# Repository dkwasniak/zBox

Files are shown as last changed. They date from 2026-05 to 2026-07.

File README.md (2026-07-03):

# zBox

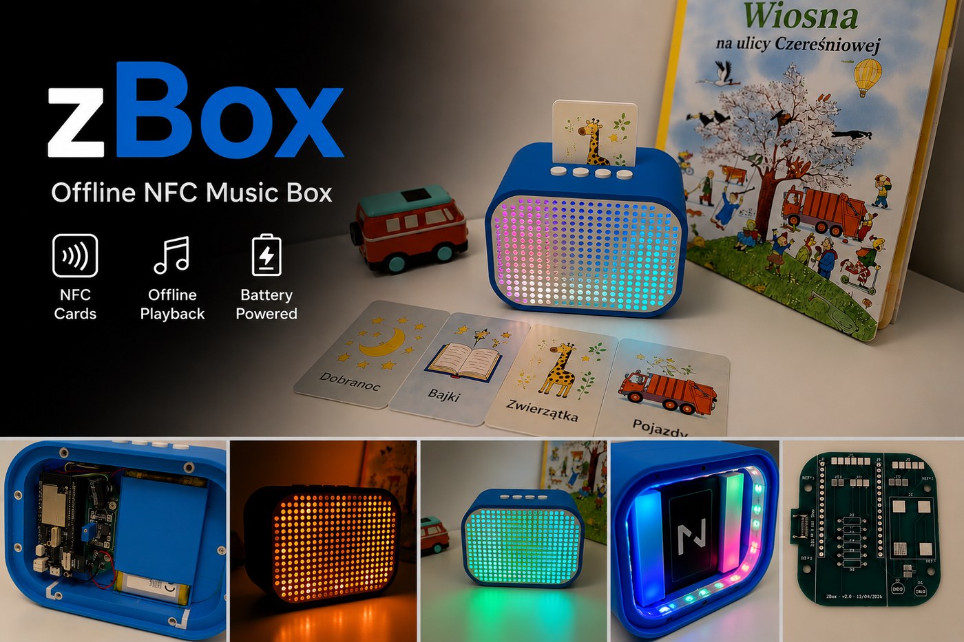
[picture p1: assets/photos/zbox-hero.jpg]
zBox hero


zBox is a custom offline NFC audio box I built for my daughter. It combines an ESP32, local SD card playback, a Raspberry Pi-hosted admin portal, LED effects, and a 3D-printed enclosure into a durable player that works with NFC cards.

This repository is the full build source for the project: firmware, backend, web admin, PCB design files, and the project documentation needed to rebuild it or adapt it for a similar box. The device plays audio stored on its SD card after an NFC tag is presented, and Wi-Fi is only used for sync and maintenance.

The box itself is built around a 3D-printed shell and custom electronics. This repository focuses on the complete hardware and software stack used in the build, from the ESP32 firmware and server to the PCB sources and operating notes. Mechanical exports such as the Fusion 360 STEP model live in `hardware/cad/fusion360/step/`.

## Project gallery

<p>
  zBox front view
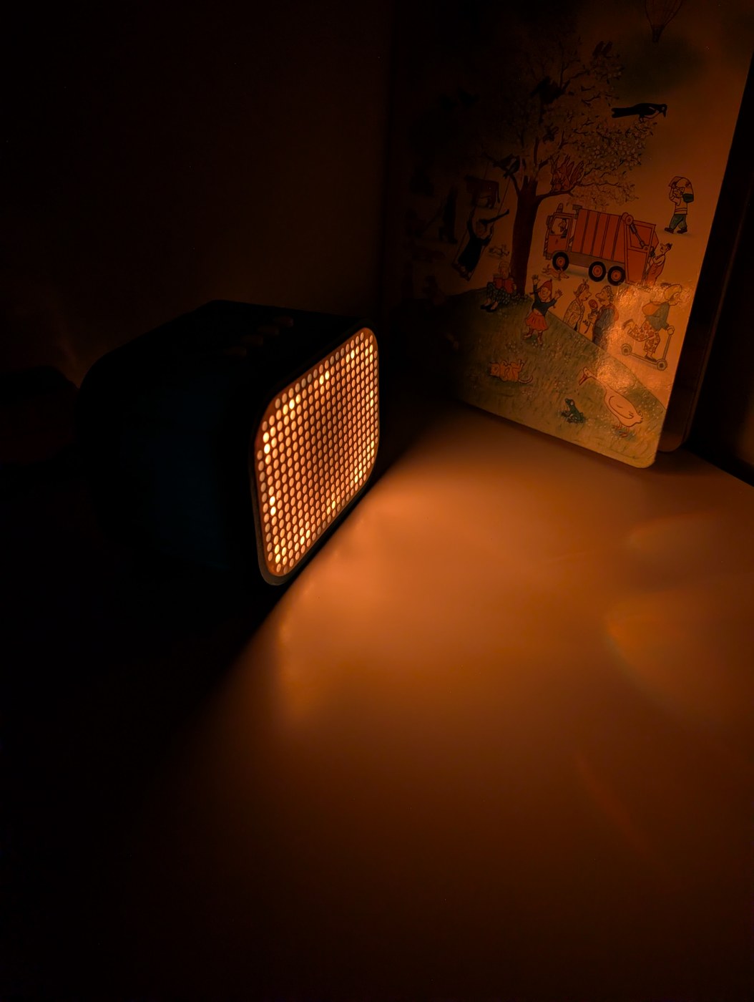
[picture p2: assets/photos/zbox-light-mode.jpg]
zBox in Light Mode
  
</p>
<p>
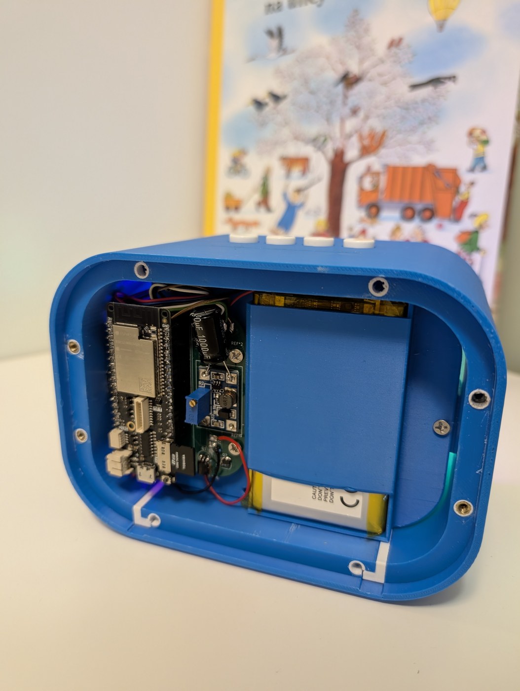
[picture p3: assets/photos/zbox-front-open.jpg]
zBox front opened
  
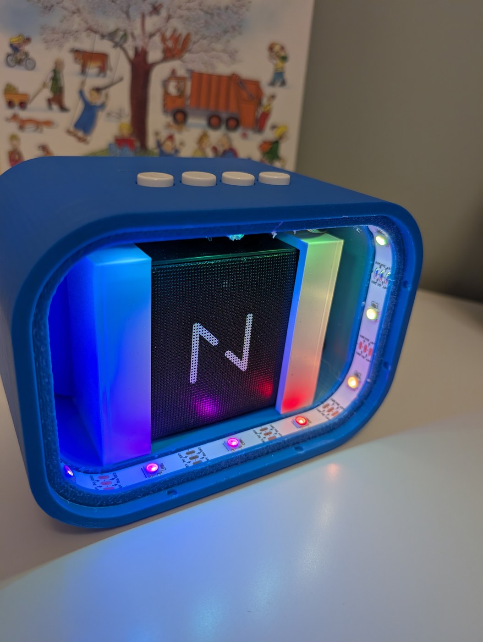
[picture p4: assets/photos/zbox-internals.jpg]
zBox internal layout
  
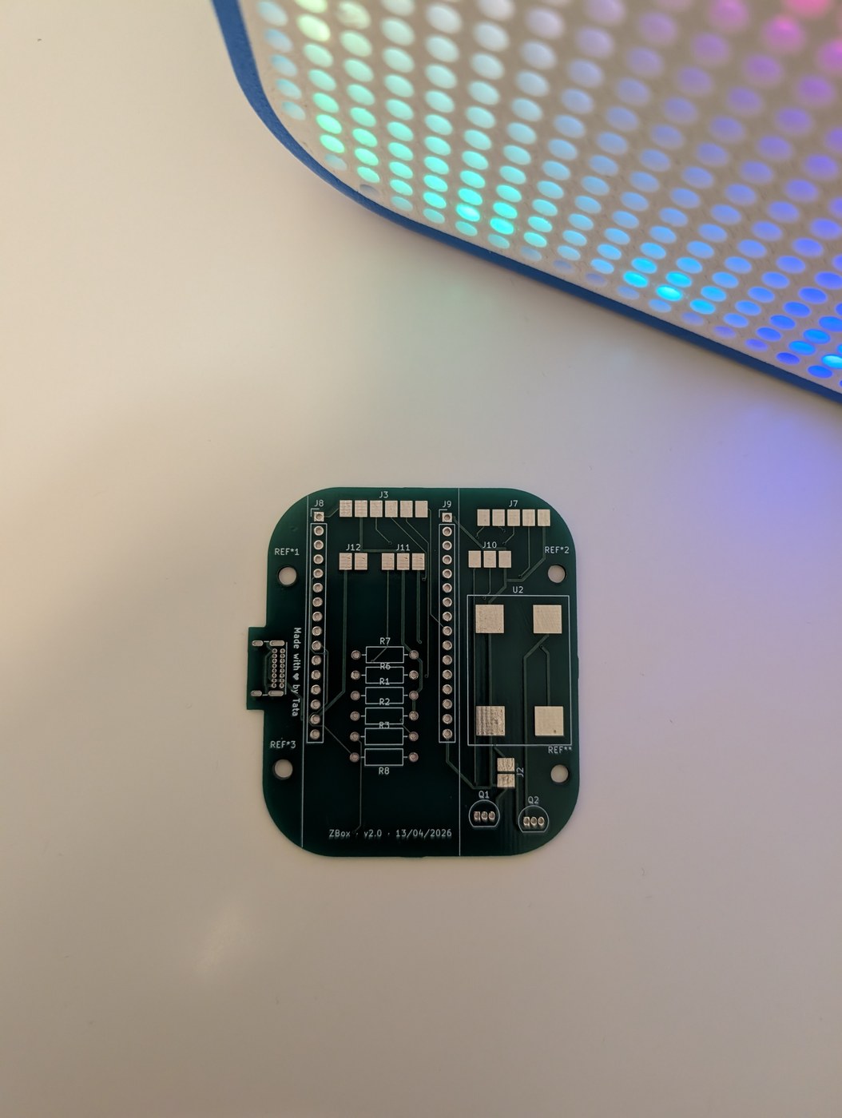
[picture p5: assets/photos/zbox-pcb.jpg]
zBox PCB
  
</p>

## Repository layout

```text
.
├── docs/                   Project documentation
├── esp32/                  ESP32 firmware (PlatformIO)
├── server/                 FastAPI backend and web admin UI
├── web/                    Static admin portal
├── hardware/               PCB, KiCad, Gerbers, and CAD exports
├── assets/                 Project photos and media used in docs
├── scripts/                Utility scripts
├── Dockerfile
└── docker-compose.yml
```

## Project split

- `esp32/` contains the offline playback firmware, Bluetooth audio pipeline, NFC handling, LED logic, and Sync Mode service flow.
- `server/` contains the FastAPI backend, SQLite integration, sync logic, and admin API.
- `web/` contains the static admin portal served by the backend.
- `hardware/pcb/kicad/` contains the PCB and schematic sources for the hardware build.
- `hardware/pcb/gerbers/` contains manufacturing outputs.
- `hardware/cad/fusion360/step/` contains exported mechanical CAD files such as STEP models.
- `assets/photos/` contains the product images used in this README.

## What to buy

If you want to build the current hardware revision, this is the practical shopping list. The various `PAD_*` items in KiCad are just solder pads for wires, not parts you need to buy.

- `1x` ESP32 Lolin D32 Pro
- `1x` PN532 NFC module that supports SPI mode
- `1x` MT3608 step-up module
- `1x` USB-C receptacle `GCT USB4085` or a compatible `USB 2.0 14-pin` footprint match
- `1x` P-channel MOSFET `AO3415A` in `SOT-23`
- `1x` NPN transistor `BC547` in `TO-92`
- `1x` electrolytic capacitor `470uF`
- `2x` resistors `5.1k`
- `1x` resistor `2.2k`
- `1x` resistor `10k`
- `1x` resistor `22k`
- `1x` resistor `100k`
- `1x` WS2812B LED strip or panel for the front light matrix
- `4x` momentary tactile buttons for `A`, `B`, `C`, and `D` — `12 × 12 × 7.3 mm`, 4-pin TACT switches with colored caps (e.g. MSALAMON kit or any equivalent 12 × 12 × 7.3 mm TACT switch)
- `1x` LiPo battery, currently `Akyga LP805080 3.7V / 4000mAh` with `JST 2-pin` connector
  This is the battery used in my build. Pack size: `8 mm` thick, `50 mm` wide, `80 mm` high. If you swap it for another pack, check the physical dimensions against the enclosure first.
- `1x` Bluetooth speaker, currently `JBL Go 2`
- hookup wire for all off-board connections

You will also need the non-electronic build parts:

- 3D-printed enclosure parts from the project CAD
- speaker holder inserts matching the audio setup you choose
- screws or other mounting hardware that fit your chosen assembly method

## Build cost

This is what I spent building one unit. Prices reflect individual-quantity purchases — buying components in bulk would bring the per-unit cost down.

| Part | Cost |
|---|---|
| PCB manufacturing | $5 |
| ESP32 Lolin D32 Pro | $15 |
| LiPo battery | $10 |
| Tactile buttons | $1 |
| Electronic components (resistors, caps, MOSFET, etc.) | ~$5–10 |
| 3D-printed enclosure filament | — |
| Bluetooth speaker (JBL Go 2) | had it at home |
| **Total (without speaker and filament)** | **~$36–41** |
| Enclosure design, prototype prints, and iteration | countless hours |
| Electrical prototyping and circuit debugging | countless hours |
| Fixing the low-quality software Claude Code produced | countless hours |

## Hardware overview

```text
NFC card
        │
        ▼
   PN532 reader
        │
        ▼
 ESP32 Lolin D32 Pro
   ├── SD card with local audio
   ├── WS2812B LED panel
   ├── buttons A / B / C / D
   ├── speaker power control
   └── Wi-Fi for sync and maintenance
        │
        ▼
 Bluetooth speaker
```

The device is offline-first during normal use. Audio and mappings live on the SD card, while Wi-Fi is only used for sync and maintenance.

## Audio design notes

For the current build I used a `JBL Go 2` connected over Bluetooth. It was a pragmatic choice: I already had that speaker at home, it was collecting dust, and I wanted the sound quality to stay reasonably good instead of dropping in a very cheap `2 USD` speaker.

I originally tried a direct wired path using a `PCM5102A` audio module and a jack connection into that speaker, but I could not get rid of the noise and crackling well enough to be happy with the result. Bluetooth ended up being the cleaner and more reliable solution for this revision.

The long-term plan is to reuse the speaker drivers from the JBL and connect them directly to the ESP32 through an `I2S Audio Amplifier Module NS4168`. The reason for that direction is simple: it should remove the extra Bluetooth speaker from the mechanical stack, give tighter integration with the enclosure, and keep a proper digital audio path from the ESP32 to the amplifier.

The speaker sits in a dedicated holder that slides onto internal rails built into the enclosure shell. The holder locks into position on those rails, so swapping it out for a different design requires no changes to the shell itself — print a new holder and slide it in. This makes it straightforward to adapt the enclosure for a different speaker body or a directly-wired driver setup without redesigning the main enclosure.

## PCB and schematic

> [!CAUTION]
> The PCB photo in this repository shows an earlier revision. The current schematic already includes corrections that came up after assembling the enclosure. If you are manufacturing a board, use the schematic and Gerbers from this repository — not the photo.

If you want to inspect or modify the hardware design, start here:

- Schematic: [zbox.kicad_sch](hardware/pcb/kicad/zbox.kicad_sch)
- PCB layout: [zbox.kicad_pcb](hardware/pcb/kicad/zbox.kicad_pcb)
- KiCad project: [zbox.kicad_pro](hardware/pcb/kicad/zbox.kicad_pro)
- Manufacturing outputs: [hardware/pcb/gerbers](hardware/pcb/gerbers)
- 3D enclosure export: [zbox_clear.step](hardware/cad/fusion360/step/zbox_clear.step)

## Printing the enclosure

The STEP model is ready to print. Each part must be printed separately. Print orientation matters:

| Part | Orientation |
|---|---|
| Shell (main body) | Standing upright on the front face |
| Side wall | Vertical |
| Front cover | No strong preference |
| Rear cover | Lying flat on its inner surface |

### Screws and heat-set inserts

| Location | Insert | Screw |
|---|---|---|
| Rear cover | M3 heat-set inserts | M3 |
| Side wall mounting | — | M4 |
| ESP32 board mounting | — | M4 |

### Build notes

- The buttons are soldered onto a protoboard — there is no custom PCB for them. The build uses **12 × 12 × 7.3 mm momentary tactile switches (TACT, 4-pin)** with colored caps, from the MSALAMON kit. Any equivalent 12 × 12 × 7.3 mm TACT switch will fit.
- The cutout for the button board in the enclosure is not symmetric. This can be corrected in Fusion 360, or you can just account for it when positioning the buttons during soldering. It turned out that way, reason unknown.
- The button board is attached to the speaker enclosure with hot glue.

## Hardware disclaimer

I am self-taught when it comes to electronics, so the hardware part of this project may still contain mistakes, weak assumptions, or design issues that I am not aware of.

The current revision works for me in real use, but if you want to reuse, manufacture, or adapt it, treat the design as something to review carefully rather than as a guaranteed reference design. In classic programmer terms: it works on my desk.

## First build walkthrough

Complete flow from assembled hardware to first playback.

**1. Prepare the SD card**

Format the card as FAT32. A 4–16 GB card is sufficient for most use cases. Leave it empty — the sync operation creates the directory structure on the device automatically.

**2. Configure the firmware**

Open the server configuration and set `ZBOX_IP` in `.env` to the IP address or hostname of the ESP32. The admin portal uses this address to reach the device in Sync Mode.

**3. Flash the firmware**

```bash
cd esp32
pio run -t upload
```

**4. Start the server**

```bash
docker compose up -d --build
```

The admin portal is available at `http://<host>:8000`. Set `ZBOX_IP` in `.env` to the IP address or mDNS hostname of the ESP32 so the admin portal can reach the device for maintenance and sync.

**5. Pair the Bluetooth speaker**

See [Bluetooth pairing](#bluetooth-pairing) below.

**6. Add music and register NFC tags**

See [Adding music and NFC tags](#adding-music-and-nfc-tags) below.

**7. Sync**

Trigger a sync from the admin portal. The device must be on the same Wi-Fi network as the server. LEDs show yellow while Wi-Fi is active and a blue progress bar while files are transferring. After sync completes, presenting a registered NFC tag in Card Mode starts playback.

## Bluetooth pairing

The firmware connects to the Bluetooth speaker by name. The expected name is `JBL GO 2`, defined as `BT_SPEAKER_NAME` in `esp32/src/zbox_config.h`. If your speaker broadcasts a different name, update that constant before flashing.

To pair on first boot:

1. Power on the device (hold `D` for 0.8–2 sec from deep sleep).
2. Put the speaker into pairing mode.
3. The device scans for the speaker by name and connects automatically. LEDs show soft blue breathing while waiting.
4. Once connected, LEDs switch to green idle animation.

The connection is not persisted — the device reconnects by name on every boot.

## Adding music and NFC tags

The firmware plays **MP3 files only**. Other formats are not recognised.

**1. Upload a track**

Open the admin portal at `http://<host>:8000`, go to **Songs**, and upload an MP3 file.

**2. Register an NFC tag**

Go to **Tags**. Power on the ESP32 and hold an NFC tag over the PN532 reader — the portal shows the scanned UID once the device is connected. Assign a name to the tag and link it to a track.

**3. Sync**

After saving the mapping, trigger a sync from the portal. The server pushes the updated mappings and audio files to the device over Wi-Fi. Once sync finishes, presenting the tag in Card Mode starts the assigned track.

## Admin portal

The web admin portal runs at `http://<host>:8000` and covers everything needed to manage the device without touching the firmware.

### Dashboard

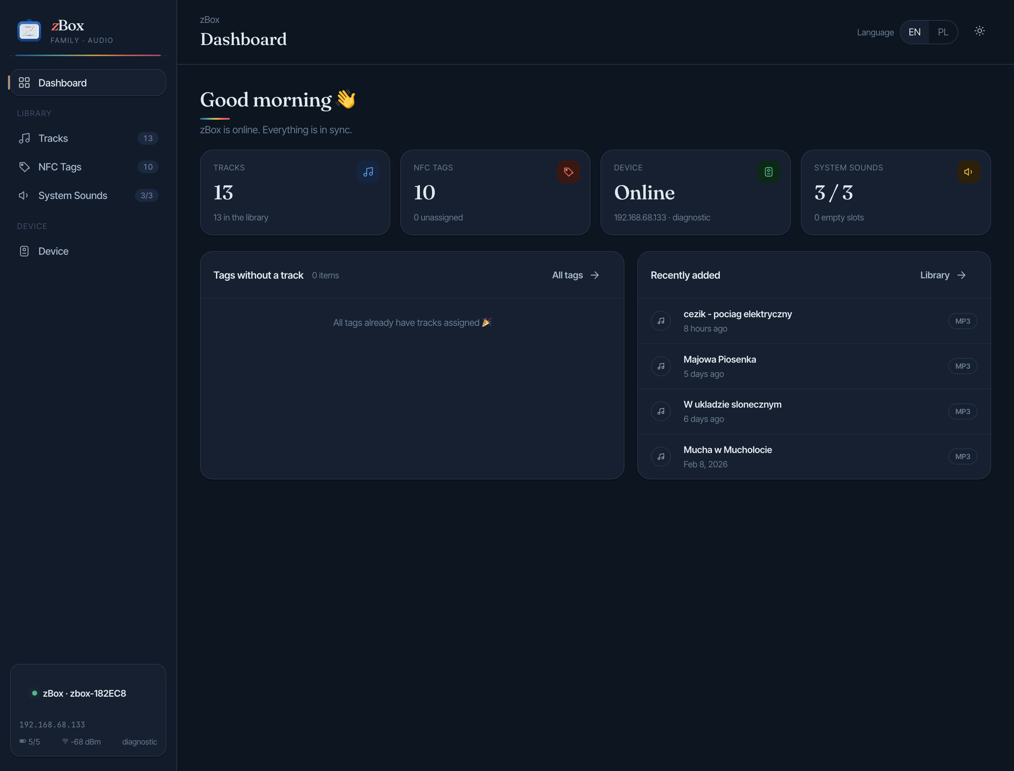
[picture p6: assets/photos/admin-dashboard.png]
Admin dashboard


The dashboard shows the live device status at a glance: connection state, number of tracks and NFC tags in the library, battery level, system sounds assignment, and recently added tracks. If any tags have no track assigned, they are flagged here.

### Tracks

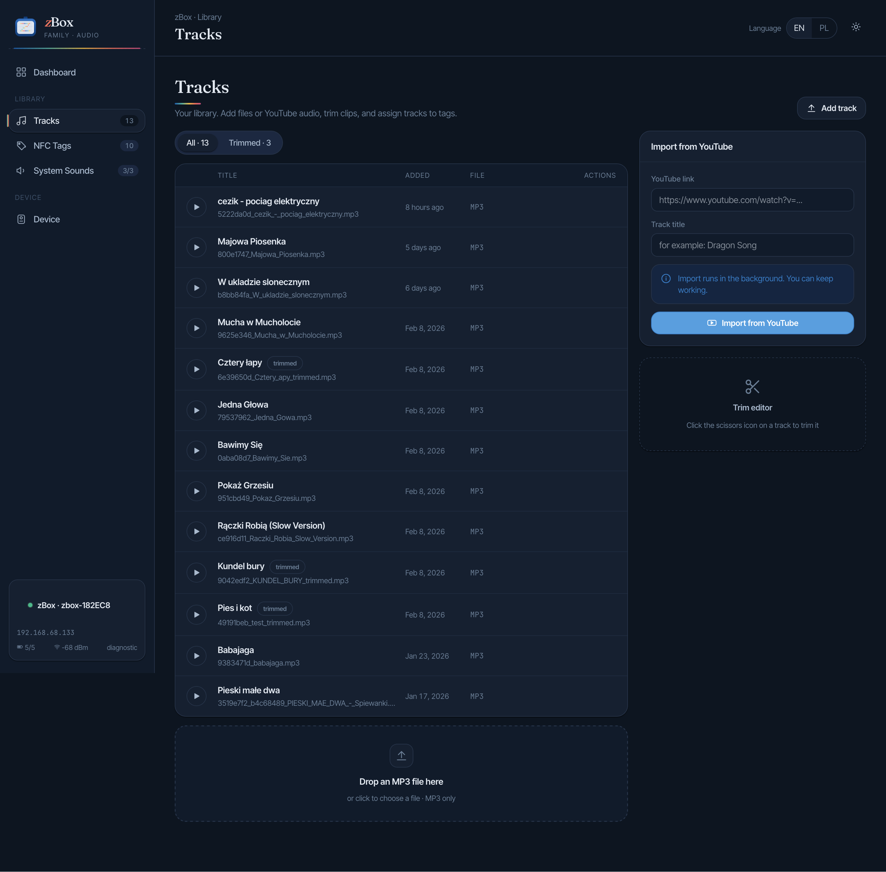
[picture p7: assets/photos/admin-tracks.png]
Tracks


The Tracks section is the music library. You can add tracks by dragging and dropping an MP3 file, or by pasting a YouTube URL to import audio directly in the background. Each track shows its filename, upload date, and size. A built-in trim editor lets you clip the start and end of a track without re-uploading the file.

**YouTube import.** Paste any YouTube URL into the import panel, give the track a title, and the server downloads and converts the audio in the background. You can keep using the portal while it runs — the track appears in the library once the download is complete.

**Trim editor.** Each track has an in-browser trim editor. Set the start and end points to cut intros, silence, or anything you do not want to play on the device. The trimmed version is what gets synced to the SD card. Tracks with an active trim are marked in the library so you can tell them apart from the originals.

### NFC Tags

The NFC Tags section lists every registered tag with its name, UID, and assigned track. The quick assign panel on the right lets you pick a tag and a track and save the mapping in one click. You can also add a tag manually by typing its name and UID hex string — useful when you want to register a tag without having the physical device connected.

**Reading a tag UID with an Android phone**

The admin portal has a built-in NFC scanner that uses the Web NFC API — no separate app needed. It works only in **Chrome on Android**; on iPhone you need to enter the UID manually.

To use it directly from the portal:

1. Open the admin portal in Chrome on Android and go to the **Tags** section.
2. The scan card appears automatically if your browser supports Web NFC.
3. Tap **Scan** and hold the tag against the back of the phone.
4. The UID is read and pre-filled into the tag form.

Web NFC requires a secure context (HTTPS or localhost). If the portal is served over plain HTTP on your local network, Chrome will block it. To work around this, enable the following Chrome flag and add your server address to the allowlist:

```
chrome://flags/#unsafely-treat-insecure-origin-as-secure
```

Alternatively, install a standalone NFC reader app (e.g. **NFC Tools** by wakdev), read the UID from there, and paste it into the manual entry field in the portal.

### System Sounds

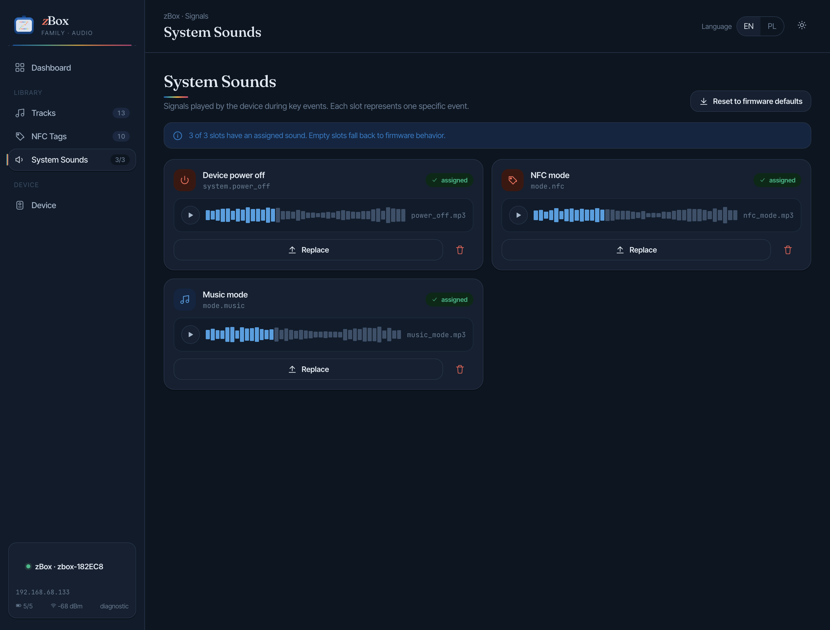
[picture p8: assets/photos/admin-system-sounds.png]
System Sounds


System Sounds are short audio clips the device plays for specific events: power off, switching to NFC mode, and switching to Music mode. Each slot shows a waveform preview and can be replaced with a custom MP3. The reset button restores the firmware defaults.

### Device and sync

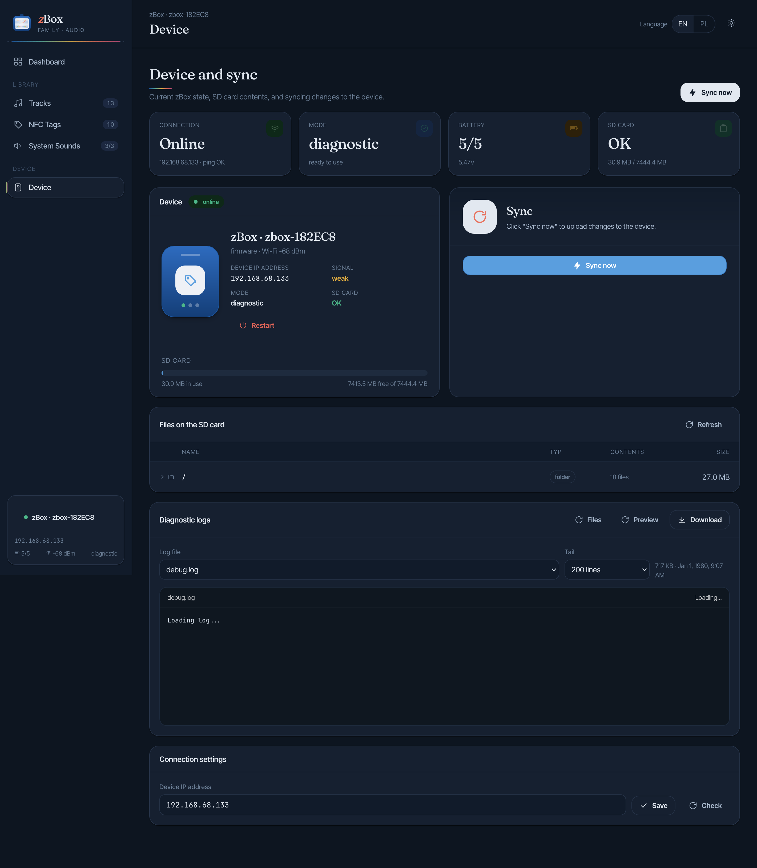
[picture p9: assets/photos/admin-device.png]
Device


The Device section is the maintenance hub. It shows live connection status, current mode, battery voltage, and SD card usage. The sync button pushes the current library and tag mappings to the device over Wi-Fi. Below that, a file browser shows everything on the SD card, and the diagnostic log viewer lets you stream or download device logs without a serial cable. The connection settings panel at the bottom is where you configure the device IP address for the portal.

## Getting started

### Server

```bash
docker compose up -d --build
```

The server runs in Docker. Runtime data is stored in `./data/`, audio assets in `./music/`, and the admin portal files in `./web/`, all mounted into the container by `docker-compose.yml`.

### ESP32 firmware

```bash
cd esp32
pio run
pio run -t upload
pio device monitor
```

The firmware depends on `esp32/lib/ESP32-A2DP`, which is kept as a Git submodule reference to the upstream project.

## Configuration model

- Server runtime configuration is local and installation-specific. The only required variable is `ZBOX_IP` — the IP address or mDNS hostname of the ESP32. Copy `.env.example` to `.env` and set it before starting the container.
- Wiring and GPIO pin assignments are documented in [`docs/hardware.md`](docs/hardware.md).

## Modes

- **Card Mode**. Default playback mode. The device reacts to NFC tags. Placing a known tag starts the assigned track from the SD card.
- **Music Mode**. Library playback mode. NFC is ignored and the buttons control pause, previous, and next track inside the local music library.
- **Light Mode**. Night light mode. Started from deep sleep by holding `D` longer during wake. In this mode `C` and `D` change brightness instead of volume.
- **Sync Mode**. Service mode used by the admin portal for maintenance, file transfer, log access, and configuration over Wi-Fi.

## Button shortcuts

| Button(s) | Action | Hold / Press | Context |
|---|---|---|---|
| `D` | **Power on** | hold `0.8–1.6 sec` while waking from deep sleep | from deep sleep |
| `D` | **Turn night light on** | hold `>= 1.6 sec` while waking from deep sleep | from deep sleep |
| `C` | **Power off** | hold `2 sec`, then release | Card Mode / Music Mode |
| `C` | **Emergency deep sleep** | hold `10 sec` | Card Mode / Music Mode |
| `C` | **Turn night light off** | hold `1 sec` | Light Mode |
| `B` | **Change mode: Music / Card** | hold `2 sec` | Card Mode / Music Mode |
| `A + B` | **Sync mode** | hold `2 sec` | Card Mode / Music Mode |
| `A` | **Battery level** | hold `2 sec` | Card Mode / Music Mode |
| `A` | **Pause / Resume** | short press | Music Mode |
| `A` | **Previous song** | double press | Music Mode |
| `B` | **Next song** | double press | Music Mode |
| `C` | **Vol −** | short press | Card Mode / Music Mode |
| `D` | **Vol +** | short press | Card Mode / Music Mode |
| `C` | **Light −** | short press | Light Mode |
| `D` | **Light +** | short press | Light Mode |

## LED animations

- **Boot progress**. Blue step-by-step progress. Each completed startup stage stays lit, and the current stage blinks three times.
- **Waiting for Bluetooth**. Soft blue breathing animation while the device is waiting for the speaker connection.
- **Idle**. Calm green breathing animation when the device is ready but not currently playing.
- **Playing**. Animated rainbow ring that reacts to audio energy and beats during playback.
- **Night Light**. Solid warm orange light. Brightness is controlled by `C` and `D`.
- **Volume**. Temporary white bar showing the current volume level for about one second after `Vol +` or `Vol -`.
- **Mode change**. Two short flashes. Music Mode uses the Music color, Card Mode uses the Card color.
- **Sleep ready**. Red blinking animation after holding `C` for two seconds. Releasing `C` at that point enters normal deep sleep.
- **Sync mode entry**. Purple animated dot pattern shown after `A+B` is held, while the device is preparing to reboot into Sync Mode.
- **Wi-Fi sync**. Blue blinking after the reboot, while the device is connecting to Wi-Fi and exposing the service endpoints used by the admin portal.
- **Sync progress**. Blue progress bar that fills while files are transferred to the SD card during sync.
- **Warning**. Slow amber breathing pulse when a mapping or file is missing.
- **Shutdown**. Purple sweep animation before the device powers down.
- **Battery check**. A color-coded bar on the LEDs: blue for high charge, then green, yellow, orange, and red for critical battery.

## Emergency deep sleep

**Emergency deep sleep** is a forced low-power shutdown triggered by holding `C` for `10 sec`.

- It is intended as a fallback if the normal shutdown path is not enough.
- It skips the regular graceful flow and shuts the device down as directly as possible.
- It still tries to turn the speaker off first if the hardware status line says the speaker is on.

## Deployment shape

The intended deployment is:

1. Build and run the FastAPI server in Docker on a small Linux host such as a Raspberry Pi.
2. Flash the ESP32 and configure the server to reach it via `ZBOX_IP`.
3. Use the web admin portal to manage tracks, NFC mappings, system sounds, and sync operations.

## Documentation

- [Server docs](docs/server.md)
- [Hardware docs](docs/hardware.md)
- [ESP32 quick start](esp32/README.md)

## Known constraints

- Playback is offline-first. The device syncs files and metadata to the SD card instead of streaming during normal use.
- Bluetooth and Wi-Fi are intentionally not used at the same time on the ESP32 due to memory and radio constraints.
- The current firmware configuration still requires a compile-time server host value.

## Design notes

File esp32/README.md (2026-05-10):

# zBox ESP32 Firmware

Firmware for the ESP32 Lolin D32 Pro using PlatformIO and the mixed `arduino, espidf` framework setup.

## Quick start

```bash
pio run
pio run -t upload
pio device monitor
```

## Before flashing

- review `ENABLE_LEDS`
- set `SERVER_HOST` for your own deployment
- verify the board and partition settings match your hardware

The main project constants live in [`src/zbox_config.h`](src/zbox_config.h).

## Documentation

- [Firmware architecture](../docs/esp32-firmware.md)
- [Hardware notes](../docs/hardware.md)
- [Server API and deployment](../docs/server.md)

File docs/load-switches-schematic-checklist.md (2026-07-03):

# Checklista do naniesienia w schemacie KiCad — load-switche NS + NFC

Mechaniczna lista do wklepania w `hardware/pcb/kicad/zbox.kicad_sch`. Bez step-upa.
Źródło prawdy: [`load-switches.md`](load-switches.md). Kolejność: nety → elementy → połączenia → zmiany na złączach.

## 0. Nowe nety do utworzenia

| Net | Rola |
|---|---|
| `+3V3_NS` | zasilanie modułu NS4168 za tranzystorem Q3 (przełączane) |
| `NS_EN_G` | bramka Q3 |
| `NFC_GND_SW` | masa modułu PN532 za tranzystorem Q4 (przełączana) |
| `NFC_EN_G` | bramka Q4 |

Istniejące, używane bez zmian: `+3V3`, `GND`, `GPIO15` (J9.15), `GPIO12` (J8.12).

## 1. Elementy do dodania

| Ref | Symbol / wartość | Footprint |
|---|---|---|
| Q3 | AO3401A (P-MOSFET) | `Package_TO_SOT_SMD:SOT-23` |
| Q4 | AO3400A (N-MOSFET) | `Package_TO_SOT_SMD:SOT-23` |
| R11 | 100k | `Resistor_THT:R_Axial_DIN0207_L6.3mm_D2.5mm_P10.16mm_Horizontal` |
| R12 | 10k | `Resistor_THT:R_Axial_DIN0207_L6.3mm_D2.5mm_P10.16mm_Horizontal` |
| R13 | 100k | `Resistor_THT:R_Axial_DIN0207_L6.3mm_D2.5mm_P10.16mm_Horizontal` |
| R14 | 100R | `Resistor_THT:R_Axial_DIN0207_L6.3mm_D2.5mm_P10.16mm_Horizontal` |
| C6 | 100nF | `Capacitor_THT:C_Disc_D5.0mm_W2.5mm_P5.00mm` |
| C2 | 10µF (elektrolit) | `Capacitor_THT:CP_Radial_D5.0mm_P2.50mm` |
| C3 | 100nF | `Capacitor_THT:C_Disc_D5.0mm_W2.5mm_P5.00mm` |
| C4 | 10µF (elektrolit) | `Capacitor_THT:CP_Radial_D5.0mm_P2.50mm` |
| C5 | 100nF | `Capacitor_THT:C_Disc_D5.0mm_W2.5mm_P5.00mm` |

BOM: 1× AO3401A · 1× AO3400A · 2× 100k · 1× 10k · 1× 100R · 3× 100nF · 2× 10µF.

## 2. Pinout FET-ów (SOT-23)

Oba: **pin1 = G, pin2 = S, pin3 = D.**

## 3. Połączenia pin-po-pinie

### NS — Q3 (high-side P-FET, aktywne LOW, soft-start)

| Od | Net |
|---|---|
| Q3 pin2 (S) | `+3V3` |
| Q3 pin3 (D) | `+3V3_NS` |
| Q3 pin1 (G) | `NS_EN_G` |
| R11 | `NS_EN_G` ↔ `+3V3` |
| R12 (10k) | `GPIO15` (J9.15) ↔ `NS_EN_G` |
| C6 (100nF) | `NS_EN_G` ↔ `+3V3` |
| C2 (10µF) | `+3V3_NS` (**+**) ↔ `GND` (**–**) |
| C3 (100nF) | `+3V3_NS` ↔ `GND` |

### NFC — Q4 (low-side N-FET, aktywne HIGH)

| Od | Net |
|---|---|
| Q4 pin3 (D) | `NFC_GND_SW` |
| Q4 pin2 (S) | `GND` |
| Q4 pin1 (G) | `NFC_EN_G` |
| R13 | `NFC_EN_G` ↔ `GND` |
| R14 (100R) | `GPIO12` (J8.12) ↔ `NFC_EN_G` |
| C4 (10µF) | `+3V3` (**+**) ↔ `NFC_GND_SW` (**–**) |
| C5 (100nF) | `+3V3` ↔ `NFC_GND_SW` |

## 4. Zmiany netów na istniejących połączeniach (KRYTYCZNE)

Nie zapomnij przepiąć zasilania modułów — inaczej switche nic nie robią:

- **NS4168 VDD:** `J13.p4` z `+3V3` → **`+3V3_NS`**.
- **PN532 GND:** `J3.p2` z `GND` → **`NFC_GND_SW`** (p1 zostaje `+3V3`).

## 5. Sanity-check po naniesieniu (ERC + logika)

- `+3V3_NS` łączy: Q3.D, C2+, C3, VDD NS4168 — i **nic** poza tym (żadnego `+3V3`).
- `NFC_GND_SW` łączy: Q4.D, C4–, C5, GND PN532 — i **nic** poza tym (żadnego `GND`).
- `NS_EN_G` łączy tylko: Q3.G, R11, R12, C6.
- `NFC_EN_G` łączy tylko: Q4.G, R13, R14.
- Bramki wyjściowe: `GPIO15`→R12, `GPIO12`→R14 (nie wprost do bramki).
- Elektrolity: C2 **+** na `+3V3_NS`, C4 **+** na `+3V3`.
- ERC bez „unconnected"/„conflict" na nowych netach.

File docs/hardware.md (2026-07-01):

# zBox Hardware

## Main components

- ESP32 Lolin D32 Pro
- PN532 NFC reader over software SPI
- NS4168 I2S amplifier as the default speaker output
- Optional Bluetooth headphones mode over A2DP
- WS2812B LED strip
- SD card for offline music and mappings
- Custom PCB for wiring and power distribution
- 3D-printed enclosure with exported CAD kept in `hardware/cad/fusion360/step/`
- Current exported model: `hardware/cad/fusion360/step/zbox_clear.step`

## High-level architecture

```text
ESP32 + SD + NFC + LEDs + buttons
        │
        ├── I2S audio ──> NS4168 amplifier ──> speaker
        ├── Optional Bluetooth A2DP audio ──> headphones
        └── Wi-Fi only during sync / diagnostics
```

## Important pin assignments

| GPIO | Function |
|---|---|
| `4` | SD card chip select |
| `5` | PN532 chip select |
| `0` | PN532 MOSI |
| `12` | PN532 power enable (NFC_EN, low-side, active HIGH) |
| `13` | NS4168 I2S data out |
| `14` | WS2812B data |
| `15` | NS4168 power enable (NS_EN, high-side, active LOW) |
| `21` | PN532 MISO |
| `22` | PN532 SCK |
| `25` | Button C |
| `26` | Button D |
| `27` | LED power enable |
| `32` | NS4168 I2S bit clock |
| `33` | NS4168 I2S word select |
| `36` | Button A |
| `39` | Button B |

## Lolin D32 Pro header numbering from the board photo

The board photo uses `L1..L16` on the left header and `R1..R16` on the right header, counted from top to bottom with the USB connector at the bottom.

### Header labels from the board photo

| Position | Board label | GPIO / signal |
|---|---|---|
| `L1` | `3V3` | `3V3` |
| `L2` | `RST` | `RST` |
| `L3` | `VP` | `GPIO36` |
| `L4` | `VN` | `GPIO39` |
| `L5` | `34` | `GPIO34` |
| `L6` | `32` | `GPIO32` |
| `L7` | `33` | `GPIO33` |
| `L8` | `25` | `GPIO25` |
| `L9` | `26` | `GPIO26` |
| `L10` | `27` | `GPIO27` |
| `L11` | `14` | `GPIO14` |
| `L12` | `12` | `GPIO12` |
| `L13` | `13` | `GPIO13` |
| `L14` | `EN` | `EN` |
| `L15` | `USB` | `5V / USB` |
| `L16` | `BAT` | `VBAT` |
| `R1` | `GND` | `GND` |
| `R2` | `23` | `GPIO23` |
| `R3` | `22` | `GPIO22` |
| `R4` | `TX` | `GPIO1` |
| `R5` | `RX` | `GPIO3` |
| `R6` | `21` | `GPIO21` |
| `R7` | `19` | `GPIO19` |
| `R8` | `18` | `GPIO18` |
| `R9` | `5` | `GPIO5` |
| `R10` | `NC` | `NC` |
| `R11` | `NC` | `NC` |
| `R12` | `4` | `GPIO4` |
| `R13` | `0` | `GPIO0` |
| `R14` | `2` | `GPIO2` |
| `R15` | `15` | `GPIO15` |
| `R16` | `GND` | `GND` |

### Project wiring in `Lx/Rx` format

| Position | Function |
|---|---|
| `L3` | `GPIO36 / BTN_A` |
| `L4` | `GPIO39 / BTN_B` |
| `L6` | `GPIO32 / AUDIO_I2S_BCLK` |
| `L7` | `GPIO33 / AUDIO_I2S_LRCK` |
| `L8` | `GPIO25 / BTN_C` |
| `L9` | `GPIO26 / BTN_D` |
| `L10` | `GPIO27 / LED_EN` |
| `L11` | `GPIO14 / LED_PIN` |
| `L13` | `GPIO13 / AUDIO_I2S_DOUT` |
| `R3` | `GPIO22 / PN532_SCK` |
| `R6` | `GPIO21 / PN532_MISO` |
| `R9` | `GPIO5 / PN532_SS` |
| `R12` | `GPIO4 / SD_CS` |
| `R13` | `GPIO0 / PN532_MOSI` |

## Audio wiring

The current board revision assumes a direct digital audio path:

- `GPIO32` -> `NS4168 BCLK`
- `GPIO33` -> `NS4168 LRCK / WS`
- `GPIO13` -> `NS4168 DIN`

The old JBL-specific control wiring is no longer part of the active firmware design:

- `GPIO13` is reused for I2S data.
- `GPIO34` is free from audio duties.
- There is no firmware dependency on a speaker power transistor or speaker status ADC.

## Power switching (load switches)

Goal: the NS4168 amplifier and the PN532 NFC reader are powered only while the ESP32 is
awake, each on its own transistor. They stay off in deep sleep and default off at
power-on/flash.

Pin choice is constrained by ESP32 strapping: the only free output-capable GPIOs are
`2`, `12`, `15` (`16/17` are PSRAM on the D32 Pro, `34` is input-only, the rest are used).
- `NS_EN = GPIO15` — high-side P-FET, gate pull-up to `+3V3` (default OFF); HIGH at boot is
  safe. **Active LOW** (LOW = on).
- `NFC_EN = GPIO12` — MTDI must be LOW at boot, so PN532 uses a **low-side N-FET** with a
  gate pull-down. **Active HIGH** (HIGH = on).
- `GPIO2` was rejected: a pull-up to `+3V3` (HIGH at boot) can block USB flashing.

### NS4168 amplifier — high-side P-FET (Q3), `GPIO15`

| Part | Value | Connection |
|---|---|---|
| Q3 | AO3401A (P-MOSFET, SOT-23) | S -> `+3V3`, D -> `+3V3_NS`, G -> `NS_EN_G` |
| R11 | 100k | `NS_EN_G` <-> `+3V3` (gate pull-up, default OFF) |
| R12 | 100R | `GPIO15` <-> `NS_EN_G` (series gate) |
| C2 | 220uF | `+3V3_NS` <-> `GND` (bulk near J13) |
| C3 | 100nF | `+3V3_NS` <-> `GND` (HF decoupling near J13) |

Net change: **J13 (NS4168) VDD pin `+3V3` -> `+3V3_NS`**.

### PN532 NFC reader — low-side N-FET (Q4), `GPIO12`

| Part | Value | Connection |
|---|---|---|
| Q4 | AO3400A (N-MOSFET, SOT-23) | D -> `NFC_GND_SW`, S -> `GND`, G -> `NFC_EN_G` |
| R13 | 100k | `NFC_EN_G` <-> `GND` (gate pull-down, default OFF + strap LOW) |
| R14 | 100R | `GPIO12` <-> `NFC_EN_G` (series gate) |
| C4 | 10uF | `+3V3` <-> `NFC_GND_SW` (bulk near J3) |
| C5 | 100nF | `+3V3` <-> `NFC_GND_SW` (HF decoupling near J3) |

Net change: **J3 (PN532) GND pin `GND` -> `NFC_GND_SW`** (VDD pin stays `+3V3`).

Firmware (`esp32/src/zbox_config.h`): add `NS_EN 15` (active LOW) and `NFC_EN 12`
(active HIGH). On wake: enable, wait ~20-50 ms, then init SPI/NFC and `i2s.begin()`. Before
sleep:
- NS (high-side): deinit I2S -> lines **LOW** -> `NS_EN = HIGH` (off). LOW is safe because
  the module VDD is 0.
- NFC (low-side): deinit SPI -> lines **hi-Z (INPUT)** -> `NFC_EN = LOW` (off). Not LOW! The
  module ground floats toward `+3V3`, so driving the lines LOW would forward-bias the module
  ESD diodes (GND->pin) and back-power the ESP. Hi-Z lets the lines float with the module.

Pull-up/pull-down hold both off in sleep and at cold boot.

### Status

- [x] Audio path I2S -> NS4168 (`GPIO32/33/13`), speaker via NS4168 module (J13)
- [x] Buttons A/B moved to L3/L4 (`GPIO36/39`) with 10k external pull-ups (R9/R10)
- [x] JBL circuit removed (Q1, R3/R6/R7, J10, J12, all `JBL_*` nets)
- [ ] NS4168 load switch: Q3, R11, R12, C2, C3; J13 VDD -> `+3V3_NS`
- [ ] PN532 load switch: Q4, R13, R14, C4, C5; J3 GND -> `NFC_GND_SW`
- [ ] Correct `C1` value in the schematic to the fitted `470uF`
- [ ] Firmware: add `NS_EN` / `NFC_EN` and the wake/sleep power sequencing

## Notes

- The PN532 is wired over software SPI: `SS=GPIO5`, `SCK=GPIO22`, `MISO=GPIO21`, `MOSI=GPIO0`.
- The SD card uses the board SPI wiring, so the related SPI pins should not be repurposed.
- The current firmware starts on local I2S audio immediately. Bluetooth is only an on-demand headphones mode triggered by a long hold on `BTN_A`.
- LED power is switched so the strip can be fully shut down during sleep.
- The PCB currently uses a `470uF` polarized capacitor (`C1`) in the power path near the step-up / LED supply section.

## Practical constraints

- Keep a shared ground between the ESP32, LED supply, and speaker control circuit.
- Treat wake, button routing, and diagnostic wiring as firmware-coupled decisions. Review [`esp32/src/zbox_config.h`](../esp32/src/zbox_config.h) before changing the PCB.
- If you revise the board, check whether the current button header and optional audio breakout still match the firmware goals.
- KiCad sources live in `hardware/pcb/kicad/`, and production Gerbers live in `hardware/pcb/gerbers/`.

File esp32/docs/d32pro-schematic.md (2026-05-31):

# LOLIN D32 Pro — Schematic Reference

**Board**: LOLIN D32 Pro, REV 2.0.0, Date: 2018-06-13
**MCU module**: ESP32-WROVER (ESP32 dual-core 240 MHz, 16 MB Flash @ 1.8 V, 8 MB PSRAM @ 1.8 V)
**Supply**: 3.3 V I/O, 5 V USB input, 3.7 V LiPo battery
**Dimensions**: 65 × 25.4 mm, Weight: 7.5 g

---

## Block 1: USB – UART

**Connector P2**: USB Micro B (USB-MICRO_5P)
- VBUS (pin 1) → power path
- D+ (pin 2), D- (pin 3) → CH340C
- ID (pin 4): not connected
- GND (pin 5)

**IC U3**: CH340C USB-to-UART bridge
- No external crystal required (internal RC oscillator)
- VCC (pin 16): connected to VBUS (5 V)
- GND (pin 1)
- UD+ / UD- (pins 5/6): USB differential pair
- TXD (pin 2): → ESP32 IO3 / RXD0
- RXD (pin 3): ← ESP32 IO1 / TXD0
- V3 (pin 4): internal 3.3 V reference output — bypass cap 100 nF to GND
- DTR# (pin 13): active-low → Auto Flash circuit (controls EN via transistor)
- RTS# (pin 14): active-low → Auto Flash circuit (controls IO0 via transistor)
- CTS#, DSR#, RI#, DCD# (pins 9–12): not connected on this board
- R232 (pin 15): RS-232 level output, not used

**Decoupling**:
- C9: 10 µF electrolytic — bulk cap on VCC line
- C10: 100 nF ceramic — high-frequency bypass on VCC

---

## Block 2: Power

**Power path overview**: VBUS (USB 5 V) and VBAT (LiPo 3.7–4.2 V) are OR-ed through CJ2301 + B5819 to feed the ME6211 LDO.

**Q (CJ2301)**: P-channel MOSFET — power path switch
- Source: VBAT
- Drain: feeds into power rail
- Gate: pulled toward VBUS via two 100 kΩ resistors (voltage divider)
  - When VBUS present and VBUS > VBAT: gate voltage ≈ VBUS → Vgs ≈ 0 → MOSFET OFF → battery disconnected from power rail
  - When no VBUS: gate pulled toward GND via divider → MOSFET ON → battery feeds power rail

**D2**: B5819 Schottky diode
- Anode: VBUS (USB 5 V after connector)
- Cathode: power rail input
- Forward drop: ~0.3 V
- Purpose: allows VBUS to power the rail; blocks reverse current from battery into USB

**Two 100 kΩ resistors**: form gate bias divider for CJ2301

**U2**: ME6211 — 300 mA LDO 3.3 V regulator
- IN: power rail (~4–5 V from VBUS or VBAT path)
- OUT: +3V3 system rail
- EN: enable (HIGH = on); tied or controlled
- BP: bypass pin for internal reference (100 nF cap recommended)
- C3: 1 µF ceramic — input decoupling
- C1: 1 µF ceramic — output decoupling / stability

**Output**: +3V3 rail powering MCU, SD card, TFT port, I2C port, and pull-ups

---

## Block 3: Battery

**U5**: TP4054 — single-cell Li-Ion/LiPo charger (linear, up to 500 mA)
- VCC: connected to VBUS (5 V USB) — charger only active when USB connected
- CHRG (open-drain output): active LOW when charging → drives LED2 via current-limiting resistor
- STDBY (open-drain output): active LOW when charge complete (not explicitly wired to LED on this revision)
- PROG pin: sets charge current: **I_CHG = 1000 V / R_PROG** → R_PROG ≈ 2 kΩ → I_CHG = 500 mA
- BAT pin: connects to VBAT rail and C2 (10 µF ceramic bulk cap) and P1 positive terminal

**P1**: JST PH-2 (2.0 mm pitch) — LiPo battery connector
- Pin 1: BAT+ → VBAT rail
- Pin 2: GND

**C2**: 10 µF — bulk decoupling on VBAT rail

**Battery ADC divider**:
- R12: 100 kΩ from VBAT to IO35 / I35
- R17: 100 kΩ from IO35 / I35 to GND
- IO35 therefore reads approximately VBAT / 2 for firmware battery measurement

**LED2**: charge status LED
- Anode: +3V3 (or VBUS)
- Cathode: CHRG pin via current-limiting resistor (~1 kΩ)
- LED ON = charging; LED OFF = full or no USB

**R_PROG**: ~2 kΩ from PROG pin to GND → sets max charge current = 500 mA

**R6**: resistor near VBUS input (input filtering / ESD)

**C6**: capacitor near VBUS (input bypass for charger)

---

## Block 4: Auto Flash

**U4**: UMH3N — dual NPN digital transistor array (pre-biased: built-in base and emitter resistors ~10 kΩ / ~10 kΩ)

**Purpose**: enables automatic entry to ESP32 bootloader during firmware upload (used by esptool / PlatformIO)

**Circuit — Transistor 1 (RTS# → IO0)**:
- Base: RTS# from CH340C (active LOW)
- Collector: IO0 (ESP32 strapping pin, boot mode)
- Emitter: GND
- Logic: RTS# LOW → T1 ON → IO0 pulled LOW → download mode enabled

**Circuit — Transistor 2 (DTR# → EN)**:
- Base: DTR# from CH340C (active LOW)
- Collector: EN (reset pin, active LOW)
- Emitter: GND
- Logic: DTR# LOW → T2 ON → EN pulled LOW → reset

**Auto-flash sequence** (esptool protocol):
1. DTR=1, RTS=0 → T2 OFF, T1 ON → IO0=LOW (boot mode set)
2. DTR=0, RTS=1 → T2 ON, T1 OFF → EN=LOW (reset pulse)
3. DTR=1, RTS=1 → both OFF → EN=HIGH → ESP32 starts in download mode
4. Upload completes; esptool sends normal reset to boot from flash

---

## Block 5: Core (ESP32-WROVER)

**U9**: ESP32-WROVER module, 38-pin SMD
- Dual-core Xtensa LX6, up to 240 MHz
- Integrated Wi-Fi 802.11 b/g/n and Bluetooth 4.2 (BR/EDR + BLE)
- **16 MB SPI Flash @ 1.8 V** (external to ESP32 die, inside WROVER can)
- **8 MB PSRAM @ 1.8 V** (external, inside WROVER can)
- **IMPORTANT**: FLASH and PSRAM operate at 1.8 V — do NOT apply 3.3 V directly to their SPI bus lines. The ESP32 die handles level translation internally.
- GPIO voltage: 3.3 V (all I/O pins)

**Reset circuit**:
- K1: tactile RESET button → connects EN to GND when pressed
- C4: 100 nF ceramic — debounce capacitor on EN line
- R1: 10 kΩ pull-up — EN to +3V3 (ensures stable HIGH when button released)

**Power decoupling at module**:
- C7: 10 µF — bulk cap on 3V3 near module
- C8: 100 nF ceramic — high-frequency bypass on 3V3 near module

**Built-in LED**: GPIO5 drives onboard blue LED (active HIGH)

**Key UART pins routed to CH340C**:
- IO1 (TXD0): ESP32 → CH340C RXD
- IO3 (RXD0): ESP32 ← CH340C TXD

---

## Block 6: IO — GPIO Headers

Two 1×16P headers: JP1 (left side) and JP2 (right side). All signals at 3.3 V logic.

### JP1 — Left header (top to bottom)

| Pin | Signal | Notes |
|-----|---|---|
| 1 | RST | EN — active LOW reset |
| 2 | IO32 / TFT_LED | TFT backlight PWM; RTC-capable; output only recommended |
| 3 | IO22 / SCL | I2C clock; also routed to I2C port P3 |
| 4 | IO21 / SDA | I2C data; also routed to I2C port P3 |
| 5 | IO17 | UART2 TX; general purpose output |
| 6 | IO14 / TFT_CS | TFT chip select; also routed to TFT port P4; strapping pin (MTMS) — must be HIGH or float at boot |
| 7 | VBAT | Raw battery voltage (3.7–4.2 V on battery, ~4.7 V on USB after diode) |
| 8–9 | GND | Ground |
| 10 | IO15 | Strapping pin (MTDO) — internal pull-up; must be HIGH at boot (add 10 kΩ pull-down on custom PCB if peripheral pulls it LOW) |
| 11 | IO13 | General purpose; JTAG MTCK |
| 12 | IO12 | Strapping pin (MTDI) — **must be LOW at boot** (selects flash voltage); internal pull-down; do NOT pull HIGH at boot |
| 13 | IO2 | Strapping pin — must be LOW or float at boot (internal pull-down) |
| 14 | IO0 | Strapping pin — HIGH=normal boot, LOW=download mode; controlled by Auto Flash circuit |
| 15 | +3V3 | 3.3 V regulated output |
| 16 | GND | Ground |

### JP2 — Right header (top to bottom)

| Pin | Signal | Notes |
|-----|---|---|
| 1 | IO23 / MOSI | SPI MOSI — shared bus (TFT and SD card) |
| 2 | IO22 / SCL | Same GPIO22 as JP1 pin 3 (both headers expose it) |
| 3 | IO5 / LED | Built-in blue LED (active HIGH); strapping pin — must be LOW at boot |
| 4 | IO19 / MISO | SPI MISO — shared bus (TFT and SD card) |
| 5 | IO18 / SCK | SPI clock — shared bus (TFT and SD card) |
| 6 | IO25 | DAC1; analog output; RTC-capable |
| 7 | IO4 / TF_CS | SD card SPI chip select |
| 8 | IO16 | UART2 RX; general purpose |
| 9 | +3V3 | 3.3 V regulated output |
| 10–11 | GND | Ground |
| 12 | IO33 / TFT_RST | TFT reset; also routed to TFT port P4; RTC-capable; ADC1_CH5 (input only on ADC) |
| 13 | IO27 / TFT_DC | TFT Data/Command select; also routed to TFT port P4; RTC-capable |
| 14 | IO26 | DAC2; RTC-capable |
| 15 | IO35 | **Input only** — no internal pull-up/pull-down; ADC1_CH7; connected to onboard VBAT/2 divider |
| 16 | IO34 | **Input only** — no internal pull-up/pull-down; ADC1_CH6 |

---

## Block 7: Micro SD Card

**Connector**: MICROSD_CNF1_NOCD (standard micro SD push-push, no card-detect switch variant)

**Interface**: SPI (hardware SPI, shared with TFT)

**Signal mapping**:

| SD Pin | Signal | ESP32 GPIO |
|---|---|---|
| CS | TF_CS | IO4 |
| DI (CMD) | MOSI | IO23 |
| CLK | SCK | IO18 |
| DO (DAT0) | MISO | IO19 |
| VCC | +3V3 | — |
| GND | GND | — |

**Pull-up resistors**: R2, R3, R8, R10 — each **10 kΩ** to +3V3
- R2: CS line pull-up
- R3: MOSI line pull-up
- R8: SCK line pull-up
- R10: MISO line pull-up
- Purpose: ensure defined logic levels when no card inserted; required by SD SPI spec

**Card detect**: S1 — micro switch (short to GND when card inserted) → CD1 / CD2 terminals
- Not connected to any ESP32 GPIO on this revision (NOCD variant in firmware use)
- CD1, CD2: decoupling caps to GND on card detect lines

**Firmware usage**:
```cpp
SPI.begin(18, 19, 23, 4);  // SCK, MISO, MOSI, SS
SD.begin(4);               // CS = GPIO4
```
GPIO 18/19/23 are internally routed to the SD slot. Do NOT use these GPIOs for other peripherals while SD is active unless using separate CS lines.

---

## Block 8: TFT LCD Port

**Connector P4**: SH1.0-10-LI (10-pin, 1.0 mm pitch JST SH)

| P4 Pin | Signal | ESP32 GPIO | Notes |
|---|---|---|---|
| 1 | GND | — | |
| 2 | +3V3 | — | |
| 3 | MOSI | IO23 | SPI MOSI (shared with SD) |
| 4 | SCK | IO18 | SPI clock (shared with SD) |
| 5 | MISO | IO19 | SPI MISO (shared with SD) |
| 6 | TFT_CS | IO14 | TFT chip select |
| 7 | TFT_DC | IO27 | Data/Command select (D/C or RS pin) |
| 8 | TFT_RST | IO33 | TFT hardware reset (active LOW) |
| 9 | TFT_LED | IO32 | Backlight control (PWM) |
| 10 | +3V3 | — | Second 3V3 pin for display VCC |

SPI bus shared with SD card — differentiated by CS: IO14 (TFT) vs IO4 (SD). Only one CS active at a time.

Compatible displays: LOLIN TFT 1.4" (ST7735, 128×128) or similar 1.0 mm pitch SH connector TFTs.

---

## Block 9: I2C Port

**Connector P3**: SH1.0-4 (4-pin, 1.0 mm pitch JST SH)

| P3 Pin | Signal | ESP32 GPIO |
|---|---|---|
| 1 | GND | — |
| 2 | SDA | IO21 |
| 3 | SCL | IO22 |
| 4 | +3V3 | — |

No pull-up resistors on the D32 Pro board itself for I2C — must be provided externally (typically 4.7 kΩ to 3.3 V) or enabled via ESP32 internal pull-ups.

Compatible with LOLIN I2C sensors (SHT30, BMP280, etc.) using the same SH1.0-4 connector.

---

## Critical Notes for Firmware / Agent Reference

### Strapping pins — boot constraints

| GPIO | Constraint | Risk |
|---|---|---|
| IO0 | Must be HIGH (or floating) for normal boot | Connected to Auto Flash circuit — do not pull LOW permanently |
| IO2 | Must be LOW or float at boot | Has internal pull-down |
| IO5 | Internal pull-up → HIGH at boot (normal); affects SDIO slave timing only | Built-in LED (active HIGH); not critical for SPI-flash boot |
| IO12 | **Must be LOW at boot** | Selects 3.3 V flash voltage. If pulled HIGH: ESP32 expects 1.8 V flash → crash |
| IO14 | Must be HIGH or float at boot | Used as TFT_CS — TFT library must not assert CS during reset |
| IO15 | Should be HIGH at boot | Has internal pull-up; custom PCB may add 10 kΩ pull-down on IO15 |

### Input-only GPIOs (no internal pull-up)
IO34 and IO35 are input-only with no pull-up/pull-down. Use external resistors when needed.

### Shared SPI bus
IO18 (SCK), IO19 (MISO), IO23 (MOSI) are wired to **both** the SD card slot and the TFT port. Never activate both CS pins simultaneously.

### Flash and PSRAM voltage
Both Flash and PSRAM inside the ESP32-WROVER operate at **1.8 V**. The schematic explicitly notes: *"The FLASH & PSRAM work at 1.8V"*. This is handled internally by the WROVER module. Required build flags: `-DBOARD_HAS_PSRAM=1 -mfix-esp32-psram-cache-issue`.

### Battery voltage on VBAT pin
VBAT on JP1 is raw LiPo voltage (3.7–4.2 V nominal). When powered via USB without a battery connected, VBAT may read higher (~4.7 V). Do not feed VBAT directly to 3.3 V-only peripherals.

### Charging indicator
LED2 (CHRG from TP4054) is active-LOW — LED is ON while charging, OFF when full or USB disconnected.

### Charge current
TP4054 PROG resistor ≈ 2 kΩ → max charge current = **500 mA**. Do not replace R_PROG with a lower value without thermal verification.

### I2C pull-ups
The D32 Pro board has no onboard I2C pull-up resistors. Add 4.7 kΩ to 3.3 V externally, or enable `Wire.begin()` with `INPUT_PULLUP` (internal ~45 kΩ, adequate only for short buses at low speed).

---

## Relationship to other project docs

| Topic | File |
|---|---|
| Custom PCB pinout, project GPIO assignments | `docs/hardware.md` |
| Firmware architecture, audio stack, build flags | `docs/esp32-firmware.md` |
| This file — D32 Pro base board internal schematic | `esp32/docs/d32pro-schematic.md` |

Migracja na hardware spi

  PN532 SCK  -> GPIO22 / prawy 3
  PN532 MISO -> GPIO21 / prawy 6
  PN532 MOSI -> GPIO0  / prawy 13
  PN532 SS   -> GPIO5  / prawy 9

  Po migracji

  PN532 SCK  -> GPIO18 / prawy 8
  PN532 MISO -> GPIO19 / prawy 7
  PN532 MOSI -> GPIO23 / prawy 2
  PN532 SS   -> GPIO5  / prawy 9

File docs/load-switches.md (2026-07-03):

# Load switche: sterowanie zasilaniem NS4168 i PN532

Moduł NS (wzmacniacz) i moduł NFC zasilane tylko gdy ESP jest wybudzone. Każdy na osobnym
tranzystorze. Domyślnie OFF w deep sleep i przy starcie/flashu.

Sterowanie:
- **NS_EN = GPIO15** (J9.15) — high-side P-FET, **aktywne LOW** (LOW = on).
- **NFC_EN = GPIO12** (J8.12) — low-side N-FET, **aktywne HIGH** (HIGH = on).

Dobór pinów wymuszony strappingiem: GPIO15 bezpieczny przy HIGH na boot, GPIO12 wymaga LOW
na boot (pull-down = zgodne). GPIO2 odrzucony (pull-up→HIGH blokuje wgrywanie przez USB).

## Elementy i footprinty

| Ref | Wartość | Footprint | Uwaga |
|---|---|---|---|
| Q3 | AO3401A (P-MOSFET) | `Package_TO_SOT_SMD:SOT-23` | switch NS, high-side |
| Q4 | AO3400A (N-MOSFET) | `Package_TO_SOT_SMD:SOT-23` | switch NFC, low-side |
| R11 | 100k | `Resistor_THT:R_Axial_DIN0207_L6.3mm_D2.5mm_P10.16mm_Horizontal` | pull-up bramki Q3 |
| R12 | 10k | `Resistor_THT:R_Axial_DIN0207_L6.3mm_D2.5mm_P10.16mm_Horizontal` | szereg bramki Q3 (soft-start z C6) |
| R13 | 100k | `Resistor_THT:R_Axial_DIN0207_L6.3mm_D2.5mm_P10.16mm_Horizontal` | pull-down bramki Q4 |
| R14 | 100R | `Resistor_THT:R_Axial_DIN0207_L6.3mm_D2.5mm_P10.16mm_Horizontal` | szereg bramki Q4 |
| C6 | 100nF | `Capacitor_THT:C_Disc_D5.0mm_W2.5mm_P5.00mm` | soft-start bramki Q3 (G↔S) |
| C2 | 10uF (10–47uF) | `Capacitor_THT:CP_Radial_D5.0mm_P2.50mm` | bulk NS (przy module) |
| C3 | 100nF | `Capacitor_THT:C_Disc_D5.0mm_W2.5mm_P5.00mm` | HF NS (przy module) |
| C4 | 10uF | `Capacitor_THT:CP_Radial_D5.0mm_P2.50mm` | bulk NFC |
| C5 | 100nF | `Capacitor_THT:C_Disc_D5.0mm_W2.5mm_P5.00mm` | HF NFC |

BOM: 1× AO3401A · 1× AO3400A · 2× 100k · 1× 10k · 1× 100R · 3× 100nF · 2× 10uF.

> **Soft-start Q3 (obowiązkowy).** R12 = **10k** (nie 100R) + **C6 100nF** bramka↔źródło dają
> rampę załączenia ~1 ms. Bez tego NS4168 przy `nsPowerOn()` łapie inrush na współdzielonym railu
> `+3V3` → detektor brownout ESP resetuje płytkę w pętli. Zasada: **większy C2 → wolniejszy soft-start**
> (C2 220µF wymaga C6 ≈ 470nF). Przy C6 100nF trzymaj C2 ≤ ~47µF. Szczegóły niżej.

## Połączenia — NS4168 (Q3, high-side, GPIO15, aktywne LOW)

- Q3: S → `+3V3`, D → `+3V3_NS`, G → `NS_EN_G`
- R11: `NS_EN_G` ↔ `+3V3` (pull-up → OFF przy Hi-Z)
- R12 (**10k**): `GPIO15` (J9.15) ↔ `NS_EN_G`
- C6 (**100nF**): `NS_EN_G` ↔ `+3V3` (bramka↔źródło, soft-start)
- C2 (**10µF**): `+3V3_NS` ↔ `GND` — **wprost na pinach V/GND modułu**
- C3 (**100nF**): `+3V3_NS` ↔ `GND` — **wprost na pinach V/GND modułu**
- Zmiana netu: **J13.p4 (NS4168 VDD) `+3V3` → `+3V3_NS`**

Prąd: `+3V3` → S → D → `+3V3_NS` → VDD modułu NS. Brama G decyduje o załączeniu.
R12 + C6 spowalniają załączenie (rampa ~1 ms) → prąd rozruchowy ≈ C2·(3,3V/czas) mały → rail nie siada.
C2/C3 lutuj jak najbliżej modułu (lokalny rezerwuar).

## Połączenia — PN532 (Q4, low-side, GPIO12, aktywne HIGH)

- Q4: D → `NFC_GND_SW`, S → `GND`, G → `NFC_EN_G`
- R13: `NFC_EN_G` ↔ `GND`
- R14: `GPIO12` (J8.12) ↔ `NFC_EN_G`
- C4: `+3V3` ↔ `NFC_GND_SW`
- C5: `+3V3` ↔ `NFC_GND_SW`
- Zmiana netu: **J3.p2 (PN532 GND) `GND` → `NFC_GND_SW`** (p1 zostaje `+3V3`)

Prąd wraca: masa modułu PN532 (`NFC_GND_SW`) → D → S → `GND`. Brama G decyduje o załączeniu.
Masa PN532 unosi się o kilka mV (Rds×prąd) — dla software-SPI bez znaczenia.

## Zasady

- Pull-up R11 (Q3) i pull-down R13 (Q4) trzymają OFF, gdy GPIO jest hi-Z (sen, cold boot).
- R12/R14 chronią bramki; R12 (10k) + C6 dodatkowo robią soft-start Q3.
- **Czemu NS musi mieć soft-start, a NFC/LED nie:** NS4168 wisi na `+3V3` — **tym samym railu co rdzeń ESP**,
  którego pilnuje detektor brownout. Skokowy inrush przy `nsPowerOn()` sadza ten rail → reset. NFC ciągnie
  znikomy prąd, a LED-boost (patrz `stepup_replace.md`) ma soft-start w chipie i siedzi na `VBAT` (osobny rail,
  ESP go nie pilnuje). Sztywne wpięcie NS do `+3V3` działało bo amp wstawał **razem z narastającym railem**
  przy cold-boocie (brak zdarzenia przełączenia) — ale żarło prąd w śnie. Load-switch + soft-start = oszczędność
  w śnie **oraz** łagodne załączanie.
- Linie danych (I2S → NS, SPI → NFC) bez zmian; przełączane jest tylko zasilanie/masa modułu.
- Pull-upy przycisków R9/R10 zostają na nieprzełączanym `+3V3`.

## Firmware (`esp32/src/zbox_config.h`, `esp32/src/power/peripheral_power.cpp`)

- `#define NS_EN 15` (aktywne LOW), `#define NFC_EN 12` (aktywne HIGH).
- **NS OFF = Hi-Z (`pinMode(NS_EN, INPUT)`), nie OUTPUT-HIGH.** `pinMode(OUTPUT)` na chwilę zatrzaskuje
  pin na LOW zanim `digitalWrite(HIGH)` zdąży zadziałać — przez R12 to **na µs załącza Q3** → inrush →
  brownout w pętli przy boocie. Hi-Z zdaje wyłączanie na R11 (pull-up trzyma bramkę w +3V3 = FET off),
  bez żadnego glitcha. Dotyczy `peripheralPowerInitEarly()` i `nsPowerOff()`.
- **NS ON:** najpierw `digitalWrite(NS_EN, LOW)`, potem `pinMode(NS_EN, OUTPUT)` — pin nigdy nie mrugnie HIGH.
- Wybudzenie NS: ON → zwłoka ~20–50 ms → `i2s.begin()`. Soft-start (R12 10k + C6) daje miękkie załączenie.
- Wybudzenie NFC: OUTPUT → `NFC_EN = HIGH` → zwłoka ~20–50 ms → init SPI/NFC.
- Przed snem:
  - NS (high-side): deinit I2S → linie **LOW** → `NS_EN` w **Hi-Z (INPUT)** (off, R11 trzyma FET wyłączony).
  - NFC (low-side): deinit SPI → linie w **hi-Z (INPUT)** → `NFC_EN = LOW` (off). Nie LOW na liniach SPI! Masa modułu unosi się ku +3V3; linie na LOW forward-biasowałyby diody ESD (GND→pin) i back-powerowały ESP. Hi-Z pływa razem z masą modułu.

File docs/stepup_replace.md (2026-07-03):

# Wymiana step-up: MT3608 → TPS613222A

Wymiana dużego modułu MT3608 (z potencjometrem) na mały, stały 5 V boost. Przy okazji:
w śnie odcinamy cały podsystem LED istniejącym tranzystorem przeniesionym na **wejście**
boosta. Zachowujemy `C1 470 µF` (fix na piszczenie głośnika przy animacji diod).

## Elementy — bilans

**USUŃ:**
- moduł MT3608 (U2 stary) — razem z nim znika potencjometr

**DODAJ:**

| Ref | Wartość | Obudowa | Rola |
|---|---|---|---|
| U2 | TPS613222A | SOT-23-6 | boost stałe 5 V (bez potu) |
| L1 | 2,2 µH, Isat ≥1,5–2 A | SMD | cewka boosta (była w module) |
| Cin | 10 µF | ceramik | filtr wejścia |
| Cout | 22 µF | ceramik | stabilność pętli boosta |
| Rg | 100R | — | szereg bramki Q1 |

**PRZENIEŚ (istniejące):**
- Q1 (AO3415A P-FET) i R8 (100k) — z wyjścia `+5V_LED` na **wejście** boosta

**ZOSTAW bez zmian:**
- `C1 470 µF` — rezerwuar anti-pisk, przy pasku na `+5V_LED`
- pasek WS2812B, `LED_PIN` = GPIO14 (dane), load-switche NS/NFC

## Nety

| Net | Opis |
|---|---|
| `VBAT` | + ogniwa (3,0–4,2 V) |
| `BOOST_IN` | wejście boosta za tranzystorem (przełączane) |
| `+5V_LED` | wyjście boosta → pasek |
| `LED_EN_G` | bramka Q1 |
| `GND` | masa |

## Schemat ideowy

```
                 ┌───────────── R8 100k ─────────────┐
                 │                                    │
 VBAT ─────S│Q1│G├── LED_EN_G ── Rg 100R ── GPIO27 (LED_EN)
  (AO3415A)  │
            D
            │
        BOOST_IN ──┬──── L1 2.2µH ────┐
            │      │               ┌──┴─ SW ─┐
            │    Cin 10µF          │ TPS613222A         +5V_LED
           EN     │                │   U2    VOUT ─┬──────┬────────> WS2812B VDD (×12)
            │    GND               │   GND         │      │
            └─VIN─┘                │   NC(nc)    Cout 22µF C1 470µF
                                   └──┬──          │      │
       GND ─────────────────────────┴─────────────┴──────┴────────> WS2812B GND
```

## Połączenia (net-po-necie)

**Load-switch na wejściu (Q1, high-side P-FET, aktywne LOW):**
- Q1: **S → `VBAT`**, **D → `BOOST_IN`**, **G → `LED_EN_G`**
- R8 (100k): `LED_EN_G` ↔ `VBAT` (pull-up → OFF przy Hi-Z: sen/boot)
- Rg (100R): `GPIO27` ↔ `LED_EN_G`
- Logika: GPIO27 **LOW** → Q1 on → boost zasilony · GPIO27 **Hi-Z** → Vgs=0 → Q1 off → boost całkiem martwy

**Boost (U2 = TPS613222A):**
- **VIN → `BOOST_IN`**
- **EN → `BOOST_IN`** (na stałe on, gdy jest zasilanie)
- **L(SW) → L1**, drugi koniec **L1 → `BOOST_IN`**
- **VOUT → `+5V_LED`**
- **GND → `GND`**
- **NC → niepodłączony**
- Cin 10 µF: `BOOST_IN` ↔ `GND` (przy VIN)
- Cout 22 µF: `+5V_LED` ↔ `GND` (**tuż przy VOUT** — dla pętli)

**Wyjście / pasek:**
- **C1 470 µF**: `+5V_LED` ↔ `GND` (**przy pasku** — rezerwuar anti-pisk)
- `+5V_LED` → VDD 12× WS2812B
- `GPIO14` → DIN (bez zmian)
- wspólny `GND`

## Firmware (`esp32/`)

- **Logika bez zmian** — `LED_EN` (GPIO27) LOW=on / Hi-Z=off działa identycznie;
  `ledPowerOff()` gasi teraz cały boost zamiast samego paska
- `leds.cpp:298`: dodać **`delay(3)`** po `digitalWrite(LED_EN, LOW)` — soft-start
  boosta z zimna (dojście do 5 V + ładowanie 470 µF ≈ do 5 ms)
- `zbox_config.h:19`: poprawić komentarz (pin gasi boost, nie sam pasek)

## Docs

- `docs/hardware.md` — sekcja power path: nowy boost TPS613222A, `C1 470 µF` zostaje
  jako anti-pisk, `LED_EN` teraz na wejściu boosta

## Uwagi

- Dokładne **numery pinów 1–6** U2 wziąć z tabeli „Pin Configuration" datasheetu
  TPS613222A przy tworzeniu symbolu KiCad (tu opisane po nazwach — jednoznacznie)
- Duży `C1 470 µF` na wyjściu = boost musi go naładować przy starcie
  (`t ≈ C·V/I = 470µF·5V/0,5A ≈ 5 ms`); soft-start to udźwignie, gra ze zwłoką
  `delay(3)` w `ledInit()`. Gdyby był hiccup przy starcie → zejść do 220 µF + ceramik
- Star-ground (masa paska i NS4168 zbiegają się przy ogniwie) = opcjonalny dodatek
  dławiący pisk u źródła, gdyby sam 470 µF nie wystarczył po zmianie boosta

## Dlaczego tak (skrót decyzji)

- **TPS613222A**: stałe 5 V (nie trzeba potencjometru — zawsze chcemy 3→5 V), SOT-23,
  ~500 mA przy 3 V→5 V = ~4× zapasu nad realnym poborem 12 LED (master brightness
  capowany na 40/255 w firmware → ~115 mA worst-case)
- **P-FET na wejściu, nie EN**: EN=low zostawia body-diode path (VOUT ≈ VBAT, pasek
  cieknie). Odcięcie wejścia zabija boost i pasek naraz. Istniejący drive
  (LOW=on / Hi-Z→pull-up do BAT) daje na wejściu czysty OFF (Vgs=0) — level-shifter
  zbędny
- **C1 zostaje**: to rezerwuar łykający szpilki prądu animacji LED, inaczej NS4168 piszczy

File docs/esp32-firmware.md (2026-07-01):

# ESP32 Firmware

Firmware for the zBox NFC audio device, built with PlatformIO on the ESP32 Lolin D32 Pro using the mixed `arduino, espidf` framework.

## Build environments

| Environment | Purpose |
|---|---|
| `lolin_d32_pro` | Main firmware for the device — **logging compiled out** (default) |
| `lolin_d32_pro_debug` | Main firmware **with logging enabled** (`LOG_ENABLED`) |
| `lolin_d32_pro_ota` | `lolin_d32_pro` flashed over the air (espota) |
| `lolin_d32_pro_debug_ota` | `lolin_d32_pro_debug` flashed over the air (espota) |
| `native` | Unit tests (reducer, state logic) — runs on the host |
| `native_btndec` | Unit tests for the button decoder module |

```bash
pio run                              # build release firmware (no logs)
pio run -t upload                    # flash to device
pio device monitor                   # serial monitor at 115200 baud

pio run -e lolin_d32_pro_debug       # build with logging enabled
pio device monitor -b 921600         # serial monitor for the debug build

pio test -e native                   # run native unit tests
```

## Compile-time configuration

All device-specific constants live in [`esp32/src/zbox_config.h`](../esp32/src/zbox_config.h). The ones you are most likely to change before flashing:

| Constant | Default | Purpose |
|---|---|---|
| `AUDIO_I2S_BCLK` | `32` | NS4168 bit clock pin |
| `AUDIO_I2S_LRCK` | `33` | NS4168 left/right clock pin |
| `AUDIO_I2S_DOUT` | `13` | NS4168 data output pin |
| `ENABLE_LEDS` | `true` | Enable or disable the WS2812B LED panel |

GPIO assignments and tuning constants (timeouts, ADC factors, volume steps) are also defined there.

## Logging

Logging is controlled by the compile-time flag `LOG_ENABLED`, defined only in the `_debug` environments. The macros and persistent-log backend live in [`esp32/src/util/logging.h`](../esp32/src/util/logging.h) and [`esp32/src/util/persistent_log.cpp`](../esp32/src/util/persistent_log.cpp); the flag is wired up in [`esp32/platformio.ini`](../esp32/platformio.ini).

**Release** (`lolin_d32_pro`, the default env) — logging is compiled out entirely. The `LOGI/LOGW/LOGE/LOGC` macros expand to `((void)0)` (arguments are never evaluated) and `plog*`/`logWritef` early-return. No `Serial`/`vsnprintf` cost, no RTC/SD persistence, and about 12 KB less flash. The trade-off is losing the post-crash "RECOVERED FROM RTC" dump.

**Debug** (`lolin_d32_pro_debug`) — logging is on. Serial runs at 921600 baud with an enlarged TX buffer, and writes are **non-blocking**: a line is dropped rather than stalling a task when the TX buffer is full, so bursts of logs can't add jitter to the audio/BT path. Persistent lines are still kept in the RTC ring even when the Serial print is skipped.

Sync mode is separate: the `/diag/logs` HTTP ring buffer stays populated in every build, and only its `Serial` output is gated behind `LOG_ENABLED`.

## Architecture

The firmware uses a **reducer + dispatcher** architecture. All application logic lives in a pure function:

```
reduce(AppState, Event) → (next AppState, Effects[])
```

The dispatcher executes effects (start audio, enter/leave BT headphones mode, sleep, sync-mode restart) and feeds feedback events back into the queue. No module owns hidden state — all state is in `AppState`.

### Modules

| Module | Responsibility |
|---|---|
| `state` | `AppState` definition and zero-init |
| `reducer` | Pure `reduce()` function, no I/O |
| `dispatcher` | FreeRTOS task, event queue, effect execution |
| `audio` | SD card audio playback over local I2S with optional BT headphones routing and zBox-side PCM volume attenuation |
| `nfc_module` | PN532 NFC reader, tag detection loop |
| `playback` | Track list management and position tracking |
| `button_adapter` | Button press detection, debounce, combo and long-press decoding |
| `sleep` | Deep sleep entry, wake protocol, night-light mode |
| `sync_mode` | Wi-Fi service mode used by the admin portal for push sync, logs, and maintenance |
| `leds` | WS2812B LED scenes derived from `AppState` |
| `bt_adapter` | Temporary BT headphones-mode lifecycle and connection edges |
| `volume` | Output volume persistence and apply path |
| `battery` | ADC battery level reading |
| `sd_storage` | SD card init, file listing, path helpers |
| `persistent_log` | Diagnostic log written to SD |
| `logging` | Serial log helpers |
| `helpers` | Miscellaneous utilities |
| `musicbox_config` | Runtime configuration loaded at boot |

### Event flow

```
ISR / NFC task / timer
        │  Event
        ▼
   Event queue (FreeRTOS)
        │
        ▼
   Dispatcher task
        │  reduce(state, event) → (next_state, effects)
        ├─ updates AppState
        └─ executes Effects
               │  async result
               └─ feedback Event → queue
```

## Sleep and wake

The device enters deep sleep on:
- idle timeout (10 minutes without playback)
- BTN_C 2-second hold (normal sleep with shutdown animation)
- BTN_C 10-second hold (emergency sleep, skips animation)

Local audio is the default output on every boot. A long hold on `BTN_A` enables a temporary Bluetooth headphones mode; when the mode exits or the device restarts, output returns to local I2S.

Output volume is owned by zBox in both modes. For BT headphones the firmware scales PCM before it reaches the transport; it does not rely on remote headphone volume support. The legacy NVS key remains `bt_volume` only for backward compatibility with devices already in the field.

Wake from deep sleep requires a hold of BTN_D:
- release < 800 ms → return to sleep
- 800–1600 ms hold → normal boot
- ≥ 1600 ms hold → night-light mode

## Tests

Native tests cover reducer transitions and state invariants without requiring hardware. Run with:

```bash
pio test -e native
```

Hardware tests (sleep/wake cycles, BT reconnect, fault injection) are described in [`docs/refactor/10b_test_hardware.md`](refactor/10b_test_hardware.md).

## Further reading

Detailed design documents for the reducer/dispatcher architecture live in [`docs/refactor/`](refactor/):

- [00_overview.md](refactor/00_overview.md) — goals, locked decisions, safety constraints
- [01_appstate.md](refactor/01_appstate.md) — AppState layout
- [02_events_effects.md](refactor/02_events_effects.md) — event hierarchy and effects
- [03_reducer.md](refactor/03_reducer.md) — reducer contract
- [09_migration_stages.md](refactor/09_migration_stages.md) — staged migration plan with acceptance criteria

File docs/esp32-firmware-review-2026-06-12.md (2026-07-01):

# Review firmware ESP32 — MusicBox

Data: 2026-06-12 · Branch: `modul_ns` · Zakres: wyłącznie `esp32/src/` (+ `sdkconfig`, `platformio.ini`, submoduł `lib/ESP32-A2DP` w zakresie `end()`)

Objawy zgłoszone: (1) sporadyczne, krótkie zacięcia audio podczas odtwarzania; (2) zaskakująco szybkie rozładowanie baterii 4000 mAh „podczas snu".

**Kontekst architektury (zastany stan):** reducer jest czysty ✓, ISR-y tylko postują do kolejek ✓, single-owner per domena ✓. Wszystkie taski aplikacyjne (dispatcher „app" prio 1, audio prio 2, LED prio 1, btnadapt prio 2, nfc prio 1, loopTask) są przypięte do **core 1**; core 0 ma tylko stack BT + worker `btctrl`. NFC jest na bit-bangowanym SoftSPI (GPIO 22/21/0/5), SD na sprzętowym SPI (18/19/23) — **brak konfliktu magistrali SD↔NFC**. CPU 160 MHz (nie 240) ✓.

---

## 1. Zacięcia audio

### A1. Zapisy logu na SD z taska `loop()` konkurują z odczytem audio z SD — **wysokie / mechanizm potwierdzony w kodzie, związek z objawem: silna hipoteza**

- `src/main.cpp:276` — `plogFlushToSd()` w heartbeacie loop(); `src/util/persistent_log.cpp:166-181` — każdy flush robi `plogRotateIfNeeded()` (otwarcie `/data/debug.log` do odczytu rozmiaru), potem `SD.open(FILE_APPEND)` + pętla `println` + `close`.
- **Mechanizm:** task audio czyta plik z SD w pętli (`src/audio/audio.cpp:612`). Append do FAT (aktualizacja łańcucha FAT + wpisu katalogu) na typowej karcie trwa 50–500 ms i serializuje się z odczytem audio na poziomie FatFs/SPI. Bufor DMA I2S to ledwie kilkadziesiąt ms audio — dłuższy stall = słyszalna przerwa, po której odtwarzanie wraca. Flush odpala się najwyżej co 10 s i **tylko gdy są nowe linie WARN/ERROR/CRIT** (LOGW są persistent — `logging.h:16`), a te generują się sporadycznie (np. `[LED] frame gap`, `[AUDIO] slow decode`) — stąd nieregularność objawu („raz na jakiś czas").
- **Poprawka:** w `plogFlushToSd()` wyjść natychmiast, gdy `audioIsRunning()` (flush dogoni przy idle/przed snem); `plogRotateIfNeeded()` wykonywać co N-ty flush. Ryzyko regresji: niskie — linie i tak siedzą w ringu RTC (40×96 B, odzyskiwane po crashu); jedyny koszt to opóźnienie logu na SD. Weryfikacja: `pio run -e lolin_d32_pro`, `pio test -e native` (bez wpływu); **wymaga testu na sprzęcie** — odtwarzanie 30–60 min z wymuszanymi LOGW i nasłuch zacięć.

### A2. Blokujące logowanie w hot-path taska audio + sprzężenie przez `plogMutex` — **wysokie / potwierdzone w kodzie**

- `src/util/persistent_log.cpp:141-164` — każde LOGx to 2×`snprintf` + **blokujący** `Serial.println` (115200 bd ≈ 9 ms na 100-znakową linię). W tasku audio: heartbeat (`audio.cpp:517-521`), `[AUDIO_BT_START]` (617-625), `slow decode` LOGW (626-633). Gorzej: LOGW/E/C biorą `plogMutex` (timeout 50 ms), a `plogFlushToSd()` **trzyma ten mutex przez cały zapis na SD** (`persistent_log.cpp:175-179`) — task audio logujący ostrzeżenie potrafi czekać do 50 ms dokładnie wtedy, gdy trwa flush z A1 (efekty się sumują).
- **Poprawka:** (a) pod mutexem tylko kopiować pending-linie do lokalnego bufora, zapis SD poza mutexem; (b) logi z taska audio rate-limitować albo zdegradować do nietrwałych. Ryzyko: niskie (czysta zmiana sekcji krytycznej, semantyka logów bez zmian). Weryfikacja: `pio run`; soak-test na sprzęcie zalecany.

### A3. Churn heapu: `String` w pętli NFC co 1 s, `end()/begin()` dekodera per utwór — **średnie / potwierdzone w kodzie (skutek: hipoteza)**

- `src/nfc/nfc_module.cpp:249-288` + `util/helpers.h:28-41` — każdy poll (co `NFC_READ_INTERVAL`) alokuje kilka obiektów `String`; `src/audio/audio.cpp:383-397` — pełny `decoderStream.end()/begin()` przy każdym utworze (realloc buforów Helix); do tego `std::map<String,String>` (`sd_storage.cpp:11-12`) i `std::vector<String>` (`playback.cpp:18`).
- **Mechanizm:** wielogodzinna sesja → fragmentacja → malejący largest-free-block (już logowany: `audio.cpp:665`) → wolniejsze/nieudane alokacje w torze audio.
- **Poprawka (bezpieczna część):** w pętli NFC zastąpić `String` buforem `char[32]` (formatowanie UID bez heapu) — **zero zmian w cadence odczytów**. Mapy/wektory zostawić (alokują przy boot/sync). Restrukturyzacja dekodera **odrzucona** — ryzyko regresji toru audio przewyższa zysk, dopóki telemetria largest-block nie potwierdzi problemu. Weryfikacja: `pio test -e native` (test_uid_format wymaga aktualizacji sygnatur), `pio run`; obserwacja `[AUDIO] Track ended heap=... largest=...` w terenie.

### A4. `BtPcmBufferSink`: wielokilobajtowe `memcpy` do/z PSRAM w `portENTER_CRITICAL` — **średnie (dotyczy trybu BT) / potwierdzone w kodzie**

- `src/audio/audio.cpp:276-311` — `writeSome`/`readSome` kopiują dane wewnątrz spinlocka (przerwania wyłączone na rdzeniu wołającym); bufor 15 360 B leży w PSRAM (linie 204-205). `readForA2dp` woła task stosu BT na **core 0** — kopie z PSRAM (wolniejsze, z `-mfix-esp32-psram-cache-issue`) przy wyłączonych przerwaniach core 0 zaburzają timing kontrolera BT.
- **Poprawka:** trzymać w sekcji krytycznej wyłącznie aktualizacje indeksów (rezerwacja zakresu → kopiowanie poza lockiem → commit), ewentualnie przenieść bufor do RAM wewnętrznego (15 KB się zmieści). Ryzyko: średnie (łatwo o race przy złej implementacji dwufazowej) — wymaga testu na sprzęcie w trybie BT; logika audio poza tym nietknięta. Weryfikacja: `pio run` + odsłuch BT.

### A5. `CONFIG_BTDM_CTRL_MODEM_SLEEP=y` (ORIG) przy źródle A2DP — **niskie–średnie / hipoteza**

- `sdkconfig.defaults` — modem sleep kontrolera BT to znana przyczyna okresowych zacięć A2DP source na ESP32. Dotyczy wyłącznie trybu słuchawek. Poprawka: wyłączyć modem sleep — ale to podnosi pobór w trybie BT; rekomendacja: tylko **eksperyment na sprzęcie** (jeśli zacięcia występują też na słuchawkach), nie zmiana na stałe.

### A6. Dispatcher loguje LOGI przy każdym evencie/efekcie — **niskie / potwierdzone**

- `dispatcher.cpp:345, 296` — blokujący Serial na tasku dispatchera; nie zacina audio bezpośrednio, ale dodaje latencję do wykonania efektów (w tym komend startu audio).

### Wykluczone (warto odnotować)

- **FastLED RMT vs BT na core 0** (hipoteza z `docs/random_hang.md`): task LED jest tworzony na **core 1** (`leds.cpp:317`), więc RMT-ISR rejestruje się na core 1; show() dla 12 diod ≈ 360 µs przy prio 1 < audio prio 2. Mało prawdopodobny sprawca zacięć audio.
- **NFC**: brak wspólnej magistrali z SD, prio 1 < audio 2 — odczyty NFC nie wywłaszczają audio. `nfcCriticalBegin` zawiesza task LED na czas odczytu (20–90 ms co sekundę) — to może powodować mikro-zacięcia **animacji LED**, nie audio (obserwacja, bez propozycji zmian timingu).

### Top 3 najbardziej prawdopodobne przyczyny zacięć

1. **A1** — okresowy append logu do SD z `loop()` blokujący odczyt audio z tej samej karty (periodyczność i losowość idealnie pasują do objawu);
2. **A2** — blokujące `Serial.println` + czekanie na `plogMutex` w samym tasku audio, kumulujące się z A1;
3. **A3/A4** — fragmentacja heapu w długich sesjach (głośnik lokalny) oraz kopie PSRAM w sekcjach krytycznych (tryb BT).

---

## 2. Energia

### E1. Wyjście z trybu BT **nie wyłącza kontrolera BT** — `btA2dp.end(false)` — **krytyczne (złamana twarda reguła radia) / potwierdzone w kodzie**

- `src/audio/audio.cpp:807` → `lib/ESP32-A2DP/src/BluetoothA2DPCommon.cpp:131-235`: przy `release_memory=false` wykonywany jest tylko deinit profili A2DP/AVRC; `esp_bluedroid_disable/deinit` i `esp_bt_controller_disable/deinit` są **wyłącznie w gałęzi `release_memory=true`**. Po wyjściu z trybu słuchawek urządzenie gra dalej z głośnika z **włączonym radiem BR/EDR** (modem-sleep łagodzi, ale to nadal mA-poziom ciągłego poboru) aż do deep sleep.
- **Poprawka:** po `end(false)` dołożyć ręczny teardown: `esp_bluedroid_disable()`+`deinit()`, `esp_bt_controller_disable()`+`deinit()` — **bez** `esp_bt_controller_mem_release` (release uniemożliwiłby ponowny start trybu BT do rebootu; biblioteka po `Source::end` zeruje `is_bluedroid_initialized` — `BluetoothA2DPSource.cpp:190` — więc `start_raw` ponownie zainicjalizuje bluedroid, ale kontroler trzeba będzie re-init analogicznie do `initBtForScan()` w sync_mode). **Ryzyko regresji: wysokie** — to dokładnie okolica znanego crasha przy rozłączaniu słuchawek (submoduł ma już lokalne łatki, 29 insertions). Wdrażać osobnym commitem, z pełnym cyklem na sprzęcie: start BT → graj → stop → start ponowny → rozłączenie słuchawek z ich strony → sleep. `pio run` + `pio test -e native` (test_bt_adapter) przed i po. **Wymaga testu na sprzęcie.**

### E2. Sync mode bez timeoutu + flaga `sync_pending` przeżywa crash — **krytyczne dla scenariusza drenażu / potwierdzone w kodzie**

- `src/modes/sync_mode.cpp:1374-1417` — `for(;;)` bez żadnego limitu bezczynności; flaga kasowana tylko w `exitSyncMode()` (598) i przy timeoucie portalu (1359). `src/main.cpp:185-191` — każdy boot z istniejącą flagą wchodzi w sync.
- **Mechanizm:** przypadkowe A+B (urządzenie dla dziecka!) → restart do sync → WiFi + 160 MHz + miganie LED **bez końca** ≈ 80–120 mA → 4000 mAh znika w 1,5–2 doby. Crash w sync → reboot → znowu sync (flaga na SD). Jeśli użytkownik sądzi, że urządzenie „śpi", to jest najprostsze wyjaśnienie szybkiego drenażu.
- **Poprawka:** (a) timeout bezczynności w pętli sync (np. 30 min od ostatniego żądania HTTP/OTA → `exitSyncMode("idle timeout")`); (b) licznik wejść w sync z rzędu (NVS) — po 2 nieudanych skasować flagę. Ryzyko: niskie (sync to tryb serwisowy). Weryfikacja: `pio run`; ręcznie: wejść w sync, nie dotykać, sprawdzić restart po timeoucie.

### E3. Sekwencja wejścia w deep sleep nie odcina peryferiów — **wysokie / mechanizm potwierdzony, skala poboru do zmierzenia**

- `src/power/sleep.cpp:29-46` (`sleepExecuteDeepSleep`): przed `esp_deep_sleep_start()` jest tylko: delete audio taska, NFC PowerDown, LED off (MOSFET przez `LED_EN`→INPUT — to akurat zrobione dobrze, `leds.cpp:455-460`). Brakuje:
  - **SD**: brak `SD.end()`/`SPI.end()`; CS (GPIO4) i linie SPI floatują w deep sleep → karta może nie wejść w standby (typowo 100 µA–2 mA, wadliwe karty więcej);
  - **Wzmacniacz NS4168**: firmware **w ogóle nie steruje pinem enable** (brak w `zbox_config.h`); piny I2S 32/33/13 po zaśnięciu floatują → wejścia wzmacniacza nieokreślone (możliwy pobór/szum). Czy NS4168 ma wyprowadzony CTRL na PCB — do weryfikacji poza firmware;
  - **GPIO hold/izolacja**: brak `gpio_hold_en`/`rtc_gpio_isolate` dla CS, linii PN532 (SS/SCK/MOSI floatują w stronę zasilanego PN532), I2S.
- **Poprawka:** przed snem: `SD.end()` + `SPI.end()`, CS na OUTPUT HIGH + `gpio_hold_en`, piny I2S OUTPUT LOW + hold, `PN532_SS` HIGH + hold; po wake (początek `setup()`) `gpio_hold_dis` na tych pinach. Ryzyko: **średnie** — zapomniany `hold_dis` po wake da „SD FAIL"/martwe NFC po przebudzeniu; zmiana dotyka sekwencji snu i budzenia. Weryfikacja: `pio run`; **wymaga testu na sprzęcie z pomiarem µA** (przed/po, każda ścieżka: sleep z przycisku, idle, night-light, emergency).

### E4. PN532 może przespać noc **obudzony** — ścieżki błędów PowerDown — **wysokie (skutek katastrofalny, ścieżka rzadka) / potwierdzone w kodzie**

- `src/nfc/nfc_module.cpp:409-433`: `nfcPowerDown()` rezygnuje przy zajętym busie (timeout 1 s) lub braku acku — urządzenie i tak zasypia, a PN532 zostaje w trybie normalnym (komentarz w kodzie: ~100 mA vs ~1 mA) → bateria pada w 1–2 doby. Dodatkowo drugi wywołany `nfcPowerDown` (po wcześniejszym `stopNfcForMusicMode`) wchodzi w gałąź „not ready" i **nadpisuje `rtcNfcPowerDownSent=false`** (linia 414) mimo wysłanego wcześniej PowerDown — psuje raw-wake przy następnym boocie (wolniejszy init przez retry).
- **Poprawka:** retry PowerDown (3× z krótkim odstępem) i wpis CRIT do plog przy ostatecznej porażce; w gałęziach „skipped" nie zerować flagi RTC, jeśli PowerDown był już wysłany. **Cadence odczytów nietknięte.** Ryzyko: niskie. Weryfikacja: `pio run`; sprzęt: pomiar prądu po śnie + log `[SLEEP] NFC PowerDown ... ack=1`.

### E5. Sleep z sync mode bez `esp_wifi_stop()` i bez teardownu BT — **średnie / potwierdzone w kodzie**

- `sync_mode.cpp:1384-1389` → `sleep.cpp:13-27` (`enterDeepSleep`): WiFi nadal połączone, po skanie BT kontroler może być aktywny; IDF dokumentuje podwyższony pobór deep sleep bez uprzedniego `esp_wifi_stop()`. Poprawka: w ścieżce BTN_D w sync wywołać `cleanupBtForSyncExit()` + `WiFi.disconnect(true)` + `esp_wifi_stop()` przed `enterDeepSleep()`. Ryzyko: niskie. **Pomiar na sprzęcie.**

### E6. Możliwość „utknięcia na zawsze obudzonym": `PlayingFile` bez idle-deadline + droppable `TrackEnded` — **średnie / hipoteza poparta kodem**

- `reducer.cpp:373-374, 386-387` — podczas grania `idle_deadline_ms=0` (słusznie); powrót deadline'u zależy od `TrackEnded`/`AudioStopped`. `TrackEnded` ma domyślną politykę **Coalescible** (`event_queue.cpp:30`) i przy pełnej kolejce (głębokość **16**, `event_queue.h:6`) jest po cichu dropowany — a dispatcher bywa blokowany ~3,7 s (patrz I1). Wynik: stan `PlayingFile` na zawsze, urządzenie nigdy nie zaśnie → noc po cichu zjada baterię.
- **Poprawka:** watchdog spójności w dispatcherze (co ~30 s: `audio_state==PlayingFile && !audioIsRunning()` → syntetyczny `AudioStopped`) lub polityka retry dla `TrackEnded`. Testowalne natywnie (`pio test -e native` — nowy test reducera/dispatchera). Ryzyko: niskie.

### E7. Drobiazgi energetyczne — **niskie / potwierdzone**

- Dzielnik baterii on-board 2×100k stale pod VBAT ≈ 18–20 µA (hardware, nie do naprawy w FW; ~0,5% pojemności/miesiąc — pomijalne).
- `CONFIG_PM_ENABLE` wyłączone, brak DFS: pobór aktywny stały (160 MHz — dobrze, że nie 240); akceptowalne, bo idle→deep sleep po 10 min.
- Tick taska LED co 15 ms nawet w `LED_OFF` (`leds.cpp:920-932`) — niepotrzebne budzenie CPU; w LED_OFF można spać 200 ms+ (uwaga na responsywność przejść scen).
- Pull-up BTN_D podczas deep sleep: `INPUT_PULLUP` na padzie RTC GPIO26 powinien przetrwać (pull w domenie RTC, ext0 trzyma RTC_PERIPH zasilone), ale brak jawnego `rtc_gpio_pullup_en` — jeśli pin jednak floatuje, sporadyczne wybudzenia drenują baterię; zweryfikować licznikiem wpisów BOOT/`wake_cause` w plog po nocy. Hipoteza.
- `handleWakeFromDeepSleep`: abort <400 ms → szybki powrót do snu ✓ dobrze zrobione.

### Weryfikacja twardej reguły radia — ścieżka po ścieżce

| Ścieżka | Status |
|---|---|
| Boot normalny / music / card / night-light | ✓ radia nieinicjalizowane (grep: WiFi tylko w `sync_mode.cpp`; `audioInit` nie dotyka kontrolera) |
| BT mode start (długi BTN_A) | ✓ jedyna ścieżka startu BT poza sync |
| **BT mode exit** | ✗ **E1 — kontroler i bluedroid zostają ENABLED** |
| **BT start failure** | ✗ `audio.cpp:448-453` — po nieudanym `start_raw` brak teardownu; stack może zostać częściowo zainicjalizowany na stałe (naprawić razem z E1) |
| Rozłączenie słuchawek | ✓ wg reguły (tryb BT trwa, okno reconnect do idle-timeoutu) |
| Sync mode: WiFi | ✓ tylko tam; ✓ BT startuje wyłącznie po żądaniu HTTP `/bt/start-scan` (nigdy automatycznie) |
| Sync exit (A+B / HTTP restart / portal timeout) | ✓ `cleanupBtForSyncExit()` + restart |
| **Sleep z sync (BTN_D)** | ✗ E5 — bez wifi_stop/BT cleanup |
| Wejście w deep sleep (normalne) | ✓ fizycznie radio gaśnie; bez czystego deinit (akceptowalne) |
| Martwy kod | `releaseBtMemoryIfUnused()` (`sync_mode.cpp:117-124`) — nigdy niewywoływane; do usunięcia przy okazji |

### Top podejrzani drenażu (w kolejności prawdopodobieństwa)

1. **Urządzenie wcale nie śpi** — sync mode bez timeoutu / flaga po crashu (E2) albo utknięcie w `PlayingFile` (E6): jedyne scenariusze tłumaczące rozładowanie 4000 mAh w dni, a nie miesiące;
2. **PN532 nieuśpiony po nieudanym PowerDown** (E4) — dziesiątki mA przez całą noc, ścieżka rzadka, skutek identyczny z objawem;
3. **Karta SD + wzmacniacz z floatującymi liniami w deep sleep** (E3) — setki µA–pojedyncze mA, czyli tygodnie zamiast miesięcy;
4. Radio BT pozostawione po sesji słuchawkowej (E1) — drenaż aktywny, do najbliższego snu;
5. (obserwacja, bez propozycji zmian) cadence NFC i pull-up BTN_D w sleep: pull pada RTC powinien przetrwać deep sleep, ale warto policzyć wybudzenia — `wake_cause` jest już logowany do plog przy każdym boocie; jeśli nocą przybywa wpisów BOOT, to spurious wake'i.

---

## 3. Inne (wydajność i stabilność)

### I1. `ledShowBattery` blokuje dispatcher na ~2,3–3,7 s — **wysokie / potwierdzone w kodzie**

- `dispatcher.cpp:181` → `leds.cpp:680-729`: scena BatteryPreview wykonuje na **tasku dispatchera** sweep (480 ms) + hold (1500 ms) + opcjonalne miganie (1380 ms) + sweep-out (360 ms), wszystko przez `delay()`. Przez ten czas: zero obsługi eventów (kolejka tylko 16), przyciski martwe, deadline'y stoją, a przepełnienie kolejki eventem Critical = `esp_restart` (patrz I2).
- **Poprawka:** przenieść animację do taska LED (nowy tryb `LED_BATTERY` sterowany sceną, jak pozostałe animacje) — nieblokująco. Ryzyko: średnie (nowa maszyna stanów animacji); weryfikacja `pio run` + sprzęt (BTN_C-long podczas grania, klikać inne przyciski). `ledShutdownAnim` w ścieżce snu też blokuje 2,4 s — tam akceptowalne, nie ruszać.

### I2. Pełna kolejka + event Critical → natychmiastowy `esp_restart` — **średnie / potwierdzone**

- `event_queue.cpp:39-41`: `SleepRequested`/`BtHeadphonesModeStopped` przy pełnej kolejce restartują urządzenie bez próby ponowienia. W połączeniu z I1 scenariusz realny. **Poprawka:** przed restartem retry `xQueueSend` z timeoutem ~100 ms. Ryzyko: minimalne. Test natywny możliwy (`test_dispatcher`).
- `postEventFromIsr`: drop Critical bez śladu (komentarz w kodzie to przyznaje) — przyciski nie emitują Critical z ISR; akceptowalne, odnotowane.

### I3. `audioDeleteTaskForSleep` — `vTaskDelete` taska w nieznanym stanie — **średnie / potwierdzone (wzorzec „działa przypadkiem")**

- `audio.cpp:770-775` ← `sleep.cpp:35`: kill taska, który może właśnie trzymać lock FatFs, heap-lock (malloc w dekoderze) albo być w `decoderStream.write`. Dziś ścieżka snu po tym wywołaniu prawie nie używa SD/heapu, więc uchodzi — ale każda przyszła zmiana sekwencji snu (np. flush logu po delete) może się zawiesić. **Poprawka:** STOP przez istniejący mechanizm cmd_id (`AudioStopped` już istnieje) + `vTaskSuspend` zamiast delete. Ryzyko: wydłuża wejście w sen o ułamki sekundy; **wymaga testu na sprzęcie** (wszystkie ścieżki snu).

### I4. Stacki i watchdog — stan dobry, do potwierdzenia danymi z pola — **niskie**

- HWM logowane co 30 s dla app/led/audio/nfc (`dispatcher.cpp:381-388`, `main.cpp:281-285`) ✓; WDT 15 s panic na loop+dispatcher ✓. Stacki: app 8192, audio 8192, pozostałe 4096; `i2s_init` 2048 (jednorazowy, ciasny). Tasków audio/nfc/led nie ma w WDT — zawieszenie audio wykryje tylko brak heartbeatu w logu. Rekomendacja: bez zmian rozmiarów, dopóki HWM z terenu nie pokaże <~512 B („measure before").
- `buttonAdapterISR`: `millis()`+`digitalRead` w ISR — obie funkcje są IRAM w arduino-esp32 ✓ OK.

### I5. Obsługa błędów SD w runtime — **niskie / potwierdzone**

- `audio.cpp:656` — wyjęcie karty podczas grania wygląda jak koniec utworu (brak rozróżnienia błędu odczytu od EOF); `sdReady` ustawiane raz na boot (`main.cpp:168`), brak detekcji utraty karty. Kolejne starty kończą się czysto obsłużonym `FileNotFound` ✓. Akceptowalne; ewentualnie dźwięk błędu przy serii niepowodzeń.
- `playback.cpp:111` — lazy `refreshMusicLibrary()` na tasku dispatchera przy starcie utworu (skan katalogu + `String`): przy dużej bibliotece setki ms blokady. Poprawka: refresh tylko na boot (już jest w `playbackInit`) — usunąć lazy-fallback albo zwracać błąd. Ryzyko: niskie; `pio test -e native` (test_mapping).
- `initSD`: `SD.begin(SD_CS)` z domyślną częstotliwością 4 MHz — zapas przepustowości dla MP3 jest (≈10×), nie ruszać bez pomiarów.

### I6. Drobiazgi — **niskie**

- `nightLightTick()` (`night_light.cpp:89`) — martwy kod (timeout przejął reducer ✓ spójnie); `jbl.cpp` — pusty stub; `releaseBtMemoryIfUnused` — martwy kod (patrz tabela radiowa).
- Drift dokumentacji vs kod: skill mówi „queue 32 slots", realnie **16** (`event_queue.h:6`); wspomniany `BtState::Disabled` nie istnieje w `app_state.h`.
- `s_isPlaying`/`s_isPaused`/`btTransportStarted` (`audio.cpp:348-352`) czytane między taskami bez `volatile`/atomic — w praktyce bezpieczne (wywołania między jednostkami translacji), dla porządku `std::atomic<bool>`.

---

## Podsumowanie weryfikacyjne

- Wszystkie poprawki są weryfikowalne przez `pio run -e lolin_d32_pro` + `pio test -e native`; dodatkowego **testu na sprzęcie** wymagają: A1, A2 (soak), A4, A5 (eksperyment), E1 (pełny cykl BT), E3/E4/E5 (pomiar prądu snu), I1, I3.
- Poprawki **odrzucone** (ryzyko > zysk): restrukturyzacja `end()/begin()` dekodera per utwór (A3), zmiana częstotliwości SPI SD, zmiany priorytetów/pinningu tasków (obecny układ jest spójny z koegzystencją BT na core 0), jakiekolwiek zmiany cadence/timingu NFC (wszystkie uwagi NFC to obserwacje lub zmiany niedotykające cadence).
- Sugerowana kolejność wdrażania: **E2 → A1+A2 → E4 → I1+I2 → E3 → E1** — od najtańszych z największym zyskiem, z E1 na końcu jako najbardziej ryzykowną.

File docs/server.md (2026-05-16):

# zBox Server

The server is a FastAPI application with a SQLite database and a browser-based admin portal. It manages the track library, figurine mappings, system sound assignments, and ESP32 sync operations.

## Stack

- Python 3.11
- FastAPI
- SQLAlchemy
- SQLite in `./data/zbox.db`
- React-based static admin portal served from `web/`
- Docker / Docker Compose for deployment

## Directory layout

```text
server/
├── main.py
├── paths.py
├── database.py
├── device_sync.py
├── models.py
├── system_sounds.py
├── requirements.txt
├── routers/
│   ├── admin.py
│   └── api.py
```

```text
web/
├── index.html
├── app.jsx
├── data.jsx
├── styles.css
└── section-*.jsx
```

## Data model

- `Track`: library entry with title, stored filename, and creation timestamp.
- `Figurine`: NFC UID mapped to an optional track. Referred to as "NFC Tag" in the admin UI and user-facing documentation.
- `SystemSound`: named event slot such as `power_on` or `ready`, optionally assigned to an MP3 file.

## Public API used by the ESP32

| Method | Path | Purpose |
|---|---|---|
| `GET` | `/api/play/{nfc_uid}` | Legacy online playback response. Kept for compatibility. |
| `GET` | `/api/stream/{track_id}` | Legacy track streaming by database ID. |
| `GET` | `/api/stream/file/{filename}` | File download endpoint used by ESP32 sync. |
| `GET` | `/api/sync` | Sync manifest containing figurines, tracks, and assigned system sounds. |
| `GET` | `/api/health` | Health endpoint. |
| `GET` | `/api/system_sounds/{sound_name}` | Preview endpoint for assigned system sounds. |

## Admin API

The `/admin/...` routes provide:

- track upload, trimming, delete, and background YouTube import
- figurine CRUD and track assignment
- system sound upload and reset
- device status lookup
- device sync planning and execution
- diagnostic log browsing and download

## Sync diagnostics

The backend now emits structured application logs for device connectivity and sync execution. The most useful log streams are:

- `zbox.main`: server startup and base runtime initialization
- `zbox.admin`: admin-triggered sync task lifecycle, per-stage progress, offline detection, log download failures, and restart requests
- `zbox.device_sync`: direct HTTP interactions with the ESP32, sync plan generation, per-file upload start/finish, delete operations, metadata writes, and retry-after-connection-reset events

When investigating a failed or interrupted sync, look for:

- the sync `task_id`
- configured device IP and resolved `device_id`
- current sync `stage`
- `current_file` and per-file upload progress
- connection errors raised while polling `/diag/status`, `/diag/files`, `/diag/logs`, or `/diag/upload`

## Sync task status payload

The admin sync status response includes both aggregate progress and per-file progress for uploads.

Important fields on `GET /admin/devices/{device_id}/sync/{task_id}/status`:

- `progress`: whole-task progress in percent
- `stage`: current sync stage such as `fetching_device_state`, `uploading_audio`, or `writing_system_sounds`
- `current_file`: file currently being uploaded
- `current_file_progress`: percent for the current file
- `sync_files`: ordered list of files scheduled for upload, each with:
  - `path`
  - `status`: `pending`, `uploading`, or `uploaded`
  - `progress`

The web admin uses `sync_files` to render the live upload queue so short connectivity glitches are easier to correlate with the exact file being transferred.

## Runtime model

```bash
docker compose up -d --build
```

The server is intended to run in Docker, not as a host-level Python process.

The compose setup mounts:

- `./music` to `/app/music`
- `./data` to `/app/data`
- `./web` to `/app/web`

## Deployment

The default deployment shape is a Linux host running Docker:

```bash
docker compose up -d --build
```

Avoid hardcoding personal hostnames or private IP addresses in documentation or scripts.

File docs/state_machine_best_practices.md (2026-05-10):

# State machines in embedded C/C++ — reliability and testability

> Applies to: bare-metal, FreeRTOS, Arduino framework, ESP-IDF, STM32 HAL.  
> Assumptions: no exceptions (`-fno-exceptions`), no RTTI, static memory allocation, deterministic execution time.

---

## 1. Closed set of states — `enum` instead of `int`

The first and most important rule: the state must be a type, not a magic number.

```c
/* ❌ BAD — nothing prevents state 99 */
int state = 0;

/* ✅ GOOD — the compiler knows every possible state */
typedef enum {
    STATE_IDLE,
    STATE_CONNECTING,
    STATE_CONNECTED,
    STATE_ERROR,
    STATE_COUNT  /* sentinel — enables array-based validation */
} State;
```

In C++ you can use `enum class` for stronger typing:

```cpp
enum class State : uint8_t {  /* uint8_t = RAM savings on small MCUs */
    Idle,
    Connecting,
    Connected,
    Error
};
```

**Why this matters in embedded:** Undefined enum values fall into the `default` case of a switch, which in well-written code either logs an error or halts the system — instead of silently corrupting state.

---

## 2. Explicit transitions — table or switch, never blind `if/else if`

### Variant A — transition table (deterministic timing, easy to verify)

A transition table reads like a specification and is trivial to review in code review.

```c
typedef enum {
    EVENT_CONNECT,
    EVENT_CONNECTED_OK,
    EVENT_TIMEOUT,
    EVENT_DISCONNECT,
    EVENT_COUNT
} Event;

/* STATE_INVALID = transition not allowed */
#define STATE_INVALID 0xFF

static const uint8_t TRANSITION_TABLE[STATE_COUNT][EVENT_COUNT] = {
    /*                  CONNECT            CONNECTED_OK       TIMEOUT          DISCONNECT     */
    [STATE_IDLE]      = { STATE_CONNECTING,  STATE_INVALID,     STATE_INVALID,   STATE_INVALID  },
    [STATE_CONNECTING]= { STATE_INVALID,     STATE_CONNECTED,   STATE_ERROR,     STATE_IDLE     },
    [STATE_CONNECTED] = { STATE_INVALID,     STATE_INVALID,     STATE_INVALID,   STATE_IDLE     },
    [STATE_ERROR]     = { STATE_CONNECTING,  STATE_INVALID,     STATE_INVALID,   STATE_IDLE     },
};

State sm_process(State current, Event event) {
    if (current >= STATE_COUNT || event >= EVENT_COUNT) {
        /* Defence against out-of-bounds — critical in embedded */
        return current;
    }
    uint8_t next = TRANSITION_TABLE[current][event];
    if (next == STATE_INVALID) {
        /* Disallowed transition — ignore or log */
        return current;
    }
    return (State)next;
}
```

### Variant B — switch/case (readable for complex transitions)

```c
State sm_process(State current, Event event) {
    switch (current) {
        case STATE_IDLE:
            if (event == EVENT_CONNECT) return STATE_CONNECTING;
            break;

        case STATE_CONNECTING:
            if (event == EVENT_CONNECTED_OK) return STATE_CONNECTED;
            if (event == EVENT_TIMEOUT)      return STATE_ERROR;
            if (event == EVENT_DISCONNECT)   return STATE_IDLE;
            break;

        case STATE_CONNECTED:
            if (event == EVENT_DISCONNECT)   return STATE_IDLE;
            break;

        case STATE_ERROR:
            if (event == EVENT_CONNECT)      return STATE_CONNECTING;
            if (event == EVENT_DISCONNECT)   return STATE_IDLE;
            break;

        default:
            /* Unknown state — system error */
            break;
    }
    /* Disallowed transition — no state change */
    return current;
}
```

**Rule:** The transition function never calls HAL, UART, GPIO. It takes a state + event and returns a new state. That is all.

---

## 3. Pure transition function — separation of logic from effects

In embedded, "side effects" are: writing to a peripheral register, sending data over UART, turning on an LED, calling `HAL_GPIO_WritePin`. They should never be inside the transition logic — they make testing harder and create hidden dependencies.

```c
/* Transition logic — pure, no effects */
State sm_reduce(State current, Event event);

/* Effects — called by the outer layer after a state change */
void sm_on_entry(State state);
void sm_on_exit(State state);
```

The main loop or a FreeRTOS task ties these elements together:

```c
void sm_dispatch(SmContext *ctx, Event event) {
    State prev  = ctx->state;
    State next  = sm_reduce(prev, event);

    if (next != prev) {
        sm_on_exit(prev);       /* Cleanup on exit */
        ctx->state = next;
        sm_on_entry(next);      /* Initialisation of the new state */
        sm_log_transition(prev, event, next);  /* Observability */
    }
}
```

### Entry/exit actions

```c
void sm_on_entry(State state) {
    switch (state) {
        case STATE_CONNECTING:
            timer_start(TIMER_CONNECTION, TIMEOUT_MS);
            led_set(LED_STATUS, LED_BLINK_FAST);
            break;
        case STATE_CONNECTED:
            led_set(LED_STATUS, LED_ON);
            break;
        case STATE_ERROR:
            led_set(LED_STATUS, LED_BLINK_SLOW);
            error_counter_increment();
            break;
        default:
            break;
    }
}

void sm_on_exit(State state) {
    switch (state) {
        case STATE_CONNECTING:
            timer_stop(TIMER_CONNECTION);
            break;
        default:
            break;
    }
}
```

---

## 4. Impossible states do not exist in the type

Instead of storing multiple flags that can contradict each other, encode every possible context as a separate state.

```c
/* ❌ BAD — bool-hell, 2^3 = 8 combinations, most of them nonsensical */
typedef struct {
    bool is_loading;
    bool has_data;
    bool has_error;
} UiState;

/* ✅ GOOD — 4 states, each semantically complete */
typedef enum {
    UI_IDLE,
    UI_LOADING,
    UI_READY,       /* implies has_data == true */
    UI_ERROR        /* implies has_error == true */
} UiState;
```

For states that carry data, use a union:

```c
typedef struct {
    State state;
    union {
        struct { uint32_t retry_count; } connecting;
        struct { uint8_t data[64]; uint16_t len; } connected;
        struct { uint32_t error_code; } error;
    } ctx;
} SmContext;
```

**Rule:** If it makes no sense to store a piece of data in a given state, it should not be accessible. An untagged union in C requires discipline; in C++ you can use `std::variant` if the environment allows it.

---

## 5. ISR-safety — state machine and interrupts

The state machine should almost always be executed from a single context. Events from an ISR must go through a queue or a flag.

```c
/* In ISR — ONLY set a flag or push to a queue */
void HAL_UART_RxCpltCallback(UART_HandleTypeDef *huart) {
    /* ❌ DO NOT call sm_dispatch() from ISR */
    /* ✅ Instead: */
    BaseType_t xHigherPriorityTaskWoken = pdFALSE;
    xQueueSendFromISR(event_queue, &event_rx_complete, &xHigherPriorityTaskWoken);
    portYIELD_FROM_ISR(xHigherPriorityTaskWoken);
}

/* In FreeRTOS task — event processing */
void sm_task(void *arg) {
    SmContext ctx = { .state = STATE_IDLE };
    Event event;

    for (;;) {
        if (xQueueReceive(event_queue, &event, portMAX_DELAY) == pdTRUE) {
            sm_dispatch(&ctx, event);
        }
    }
}
```

On bare-metal without an RTOS, use a `volatile` flag and process it in the main loop:

```c
volatile Event pending_event = EVENT_NONE;  /* set in ISR */

/* In main loop */
if (pending_event != EVENT_NONE) {
    Event e = pending_event;
    pending_event = EVENT_NONE;  /* Atomic on 8/32-bit MCU for uint */
    sm_dispatch(&ctx, e);
}
```

> **Note:** On MCUs with non-atomic writes (e.g. 8-bit AVR with a 16-bit variable) use `ATOMIC_BLOCK` or a critical section.

---

## 6. Observability — logging transitions

Every transition should be loggable without changing the logic. In embedded, logging typically goes to UART, RTT (Segger), or a circular buffer in RAM.

```c
static const char *STATE_NAMES[] = {
    "IDLE", "CONNECTING", "CONNECTED", "ERROR"
};
static const char *EVENT_NAMES[] = {
    "CONNECT", "CONNECTED_OK", "TIMEOUT", "DISCONNECT"
};

void sm_log_transition(State from, Event event, State to) {
#ifdef DEBUG
    printf("[SM] %s + %s -> %s\n",
           STATE_NAMES[from],
           EVENT_NAMES[event],
           STATE_NAMES[to]);
#endif
}
```

For production with a strict RAM budget: a circular buffer of the last N transitions.

```c
#define SM_HISTORY_SIZE 8

typedef struct {
    uint8_t from;
    uint8_t event;
    uint8_t to;
} SmRecord;

static SmRecord sm_history[SM_HISTORY_SIZE];
static uint8_t  sm_history_idx = 0;

void sm_record(State from, Event event, State to) {
    sm_history[sm_history_idx % SM_HISTORY_SIZE] = (SmRecord){from, event, to};
    sm_history_idx++;
}
```

After a crash or watchdog reset, this buffer (in non-volatile RAM or a `.noinit` section) allows you to reconstruct the sequence of events.

---

## 7. Testability — unit tests without hardware

The pure transition function (`sm_reduce`) requires no MCU, no HAL, no peripheral mock. Tests can be written and run on a PC (CMake + Unity / Catch2).

### Directory structure

```
project/
├── src/
│   ├── sm.c          ← transition logic (pure, no HAL)
│   ├── sm.h
│   └── sm_effects.c  ← on_entry / on_exit (with HAL, not unit-tested)
└── test/
    ├── test_sm.c     ← tests on PC
    └── CMakeLists.txt
```

### Example tests (Unity)

```c
#include "unity.h"
#include "sm.h"

void test_idle_connect_transitions_to_connecting(void) {
    State result = sm_reduce(STATE_IDLE, EVENT_CONNECT);
    TEST_ASSERT_EQUAL(STATE_CONNECTING, result);
}

void test_connecting_timeout_transitions_to_error(void) {
    State result = sm_reduce(STATE_CONNECTING, EVENT_TIMEOUT);
    TEST_ASSERT_EQUAL(STATE_ERROR, result);
}

void test_invalid_transition_returns_current_state(void) {
    /* IDLE cannot transition via CONNECTED_OK */
    State result = sm_reduce(STATE_IDLE, EVENT_CONNECTED_OK);
    TEST_ASSERT_EQUAL(STATE_IDLE, result);
}

void test_full_happy_path(void) {
    State s = STATE_IDLE;
    s = sm_reduce(s, EVENT_CONNECT);
    TEST_ASSERT_EQUAL(STATE_CONNECTING, s);
    s = sm_reduce(s, EVENT_CONNECTED_OK);
    TEST_ASSERT_EQUAL(STATE_CONNECTED, s);
    s = sm_reduce(s, EVENT_DISCONNECT);
    TEST_ASSERT_EQUAL(STATE_IDLE, s);
}

void test_all_invalid_transitions_from_connected(void) {
    /* From STATE_CONNECTED you cannot enter via CONNECT or TIMEOUT */
    TEST_ASSERT_EQUAL(STATE_CONNECTED, sm_reduce(STATE_CONNECTED, EVENT_CONNECT));
    TEST_ASSERT_EQUAL(STATE_CONNECTED, sm_reduce(STATE_CONNECTED, EVENT_TIMEOUT));
    TEST_ASSERT_EQUAL(STATE_CONNECTED, sm_reduce(STATE_CONNECTED, EVENT_CONNECTED_OK));
}
```

**Test pattern:** Given `(current_state, event)` → assert `next_state`. No hardware initialisation, no `HAL_Init()`, no `FreeRTOS_Init()`.

---

## 8. Watchdog integration

The state machine integrates naturally with the watchdog: every transition to a "healthy" state resets the WDT counter; getting stuck in one state for too long causes a system reset.

```c
void sm_on_entry(State state) {
    /* Reset watchdog on every transition — proof of activity */
    HAL_IWDG_Refresh(&hiwdg);

    switch (state) {
        /* ... */
    }
}
```

For long-lived states (e.g. `STATE_CONNECTED` for hours) the watchdog must be refreshed inside the task loop, not only on transition.

---

## Summary — checklist

| Property | Technique in C/C++ embedded |
|---|---|
| Closed set of states | `enum` / `enum class` + `STATE_COUNT` sentinel |
| Explicit transitions | Transition table or `switch/case` — every disallowed transition = no change |
| Pure transition function | `State sm_reduce(State, Event)` without HAL, without effects |
| Separated effects | `on_entry()` / `on_exit()` called by the dispatcher |
| Impossible states | Tagged union instead of multiple bool flags |
| ISR-safety | Events via queue (`xQueueSendFromISR`) or volatile flag |
| Observability | `sm_log_transition()` + history buffer in `.noinit` |
| Testability | `sm_reduce()` in a separate `.c`, Unity/Catch2 tests on PC without MCU |
| Watchdog | WDT reset in `on_entry()` / in the loop of long-lived states |

> **Golden rule of embedded:** If a transition between two states is not in the table or switch — it is impossible. Not "should not happen" — **impossible at runtime**.

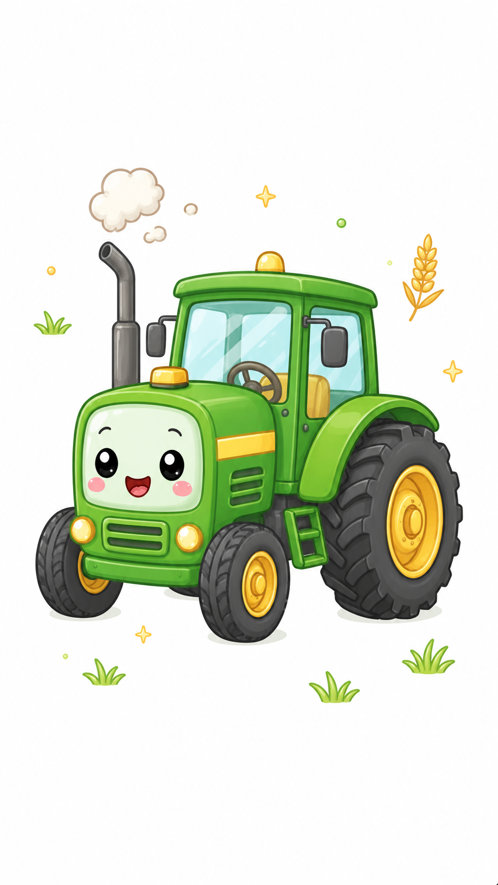
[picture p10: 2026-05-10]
cards_images/traktor.png

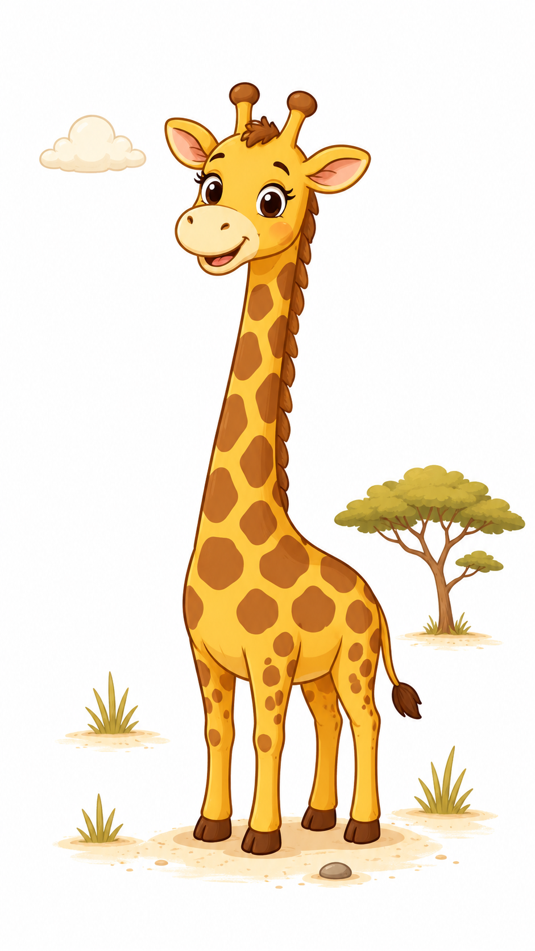
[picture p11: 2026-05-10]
cards_images/zyrafa.png

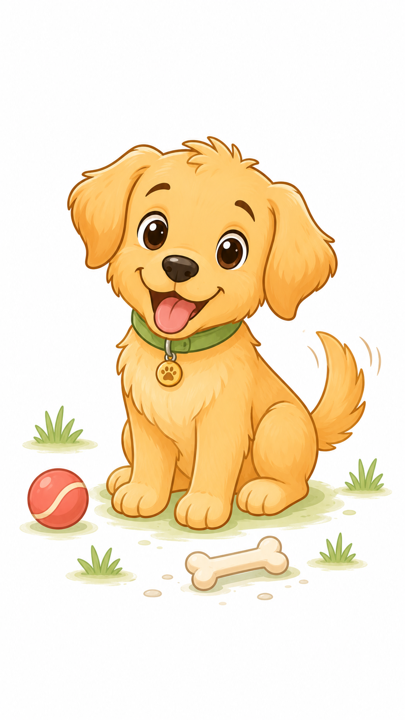
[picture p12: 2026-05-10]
cards_images/pies.png

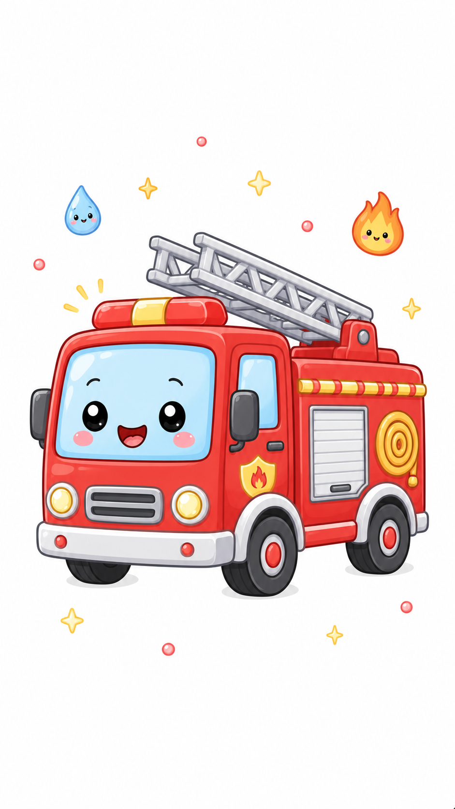
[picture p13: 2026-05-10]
cards_images/straz.png

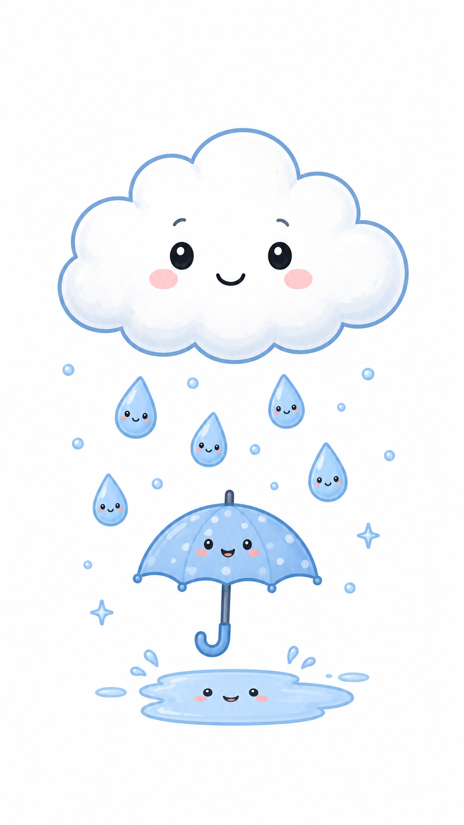
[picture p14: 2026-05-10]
cards_images/chmurka.png

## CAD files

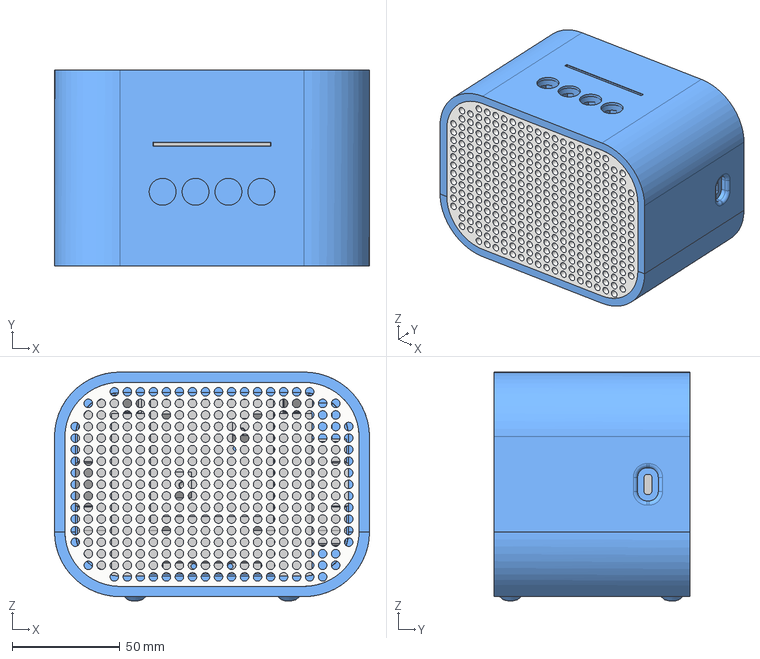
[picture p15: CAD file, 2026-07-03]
hardware/cad/fusion360/step/zbox_clear.step
146.4 x 91.0 x 106.4 mm

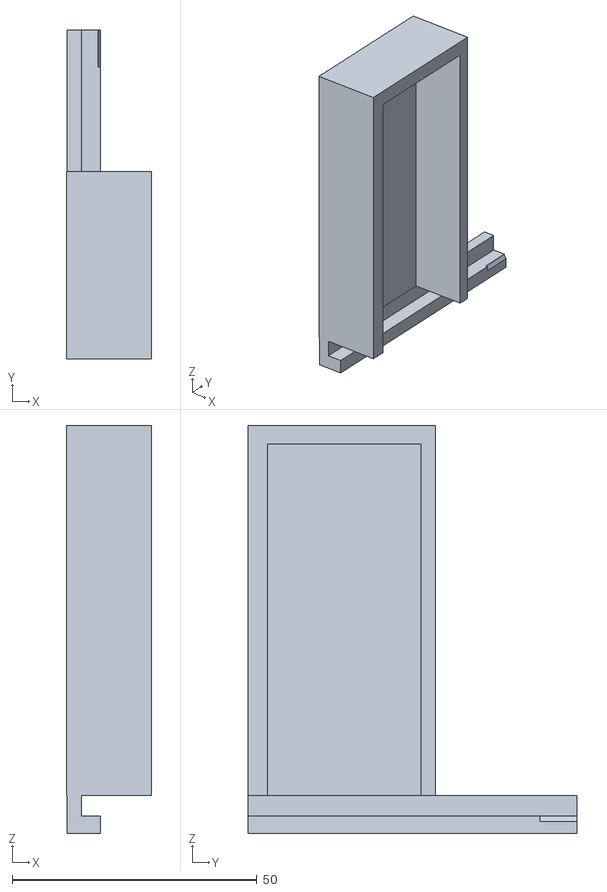
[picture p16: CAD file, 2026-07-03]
hardware/stl/speaker_holder_right_zbox_clear.stl
17.3 x 67.3 x 83.4

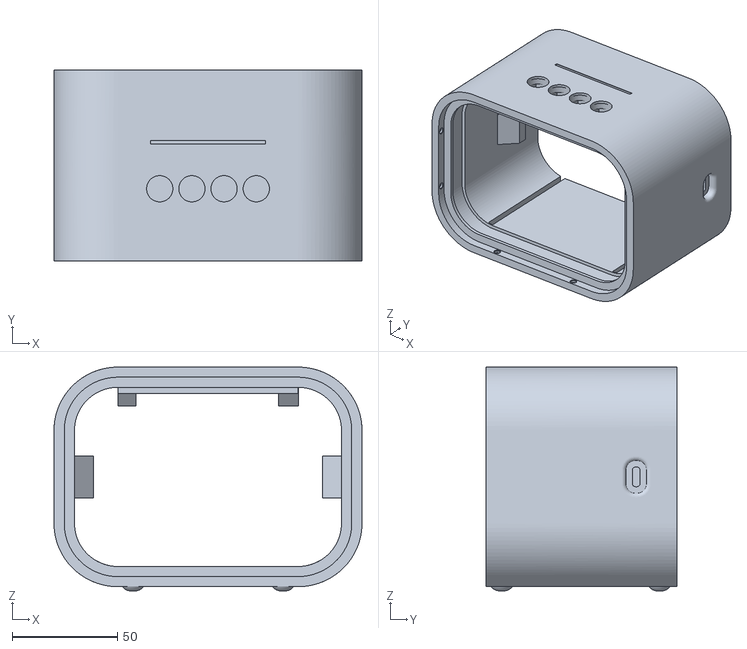
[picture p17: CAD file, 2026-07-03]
hardware/stl/shell_zbox_clear.stl
146.4 x 91.0 x 106.4

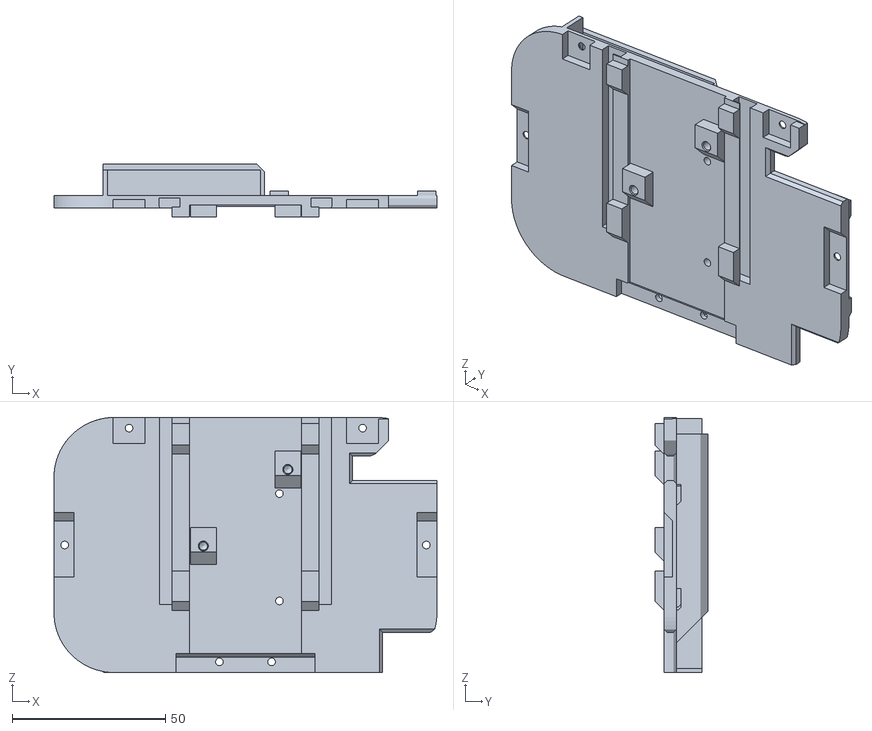
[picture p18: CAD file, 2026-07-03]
hardware/stl/wall_zbox_clear.stl
124.9 x 17.3 x 83.2

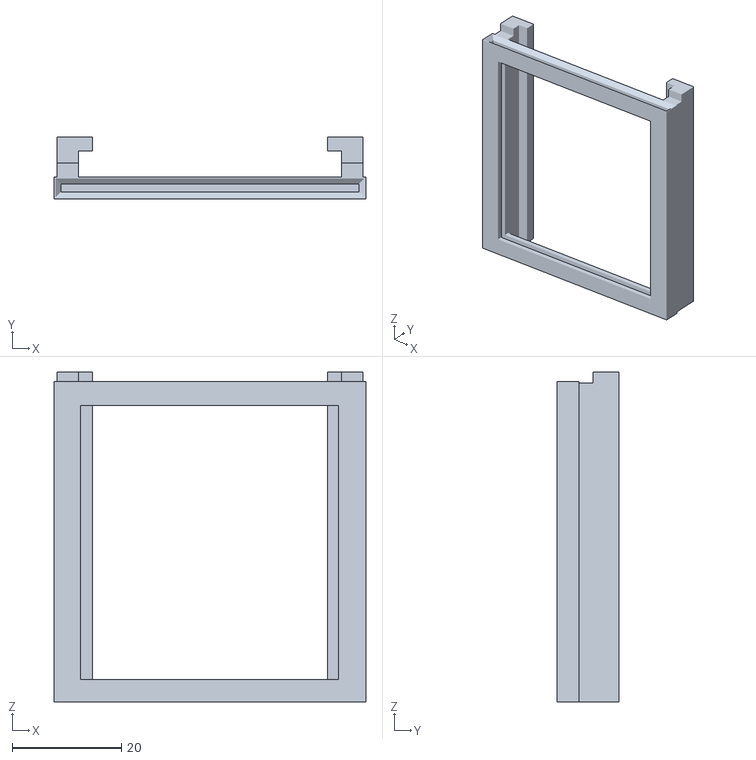
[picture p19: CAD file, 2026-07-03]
hardware/stl/nfc_card_slot_zbox_clear.stl
57.0 x 11.3 x 60.3

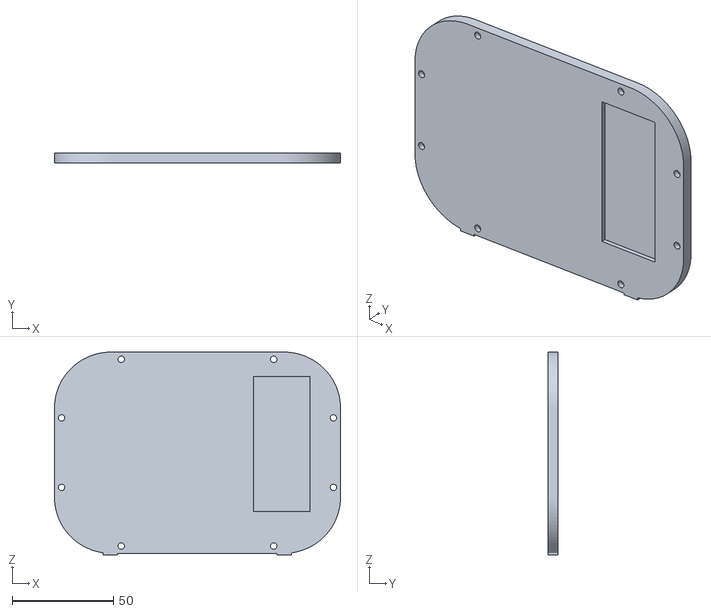
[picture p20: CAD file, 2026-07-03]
hardware/stl/rear_lid_zbox_clear.stl
141.5 x 5.00 x 100.4

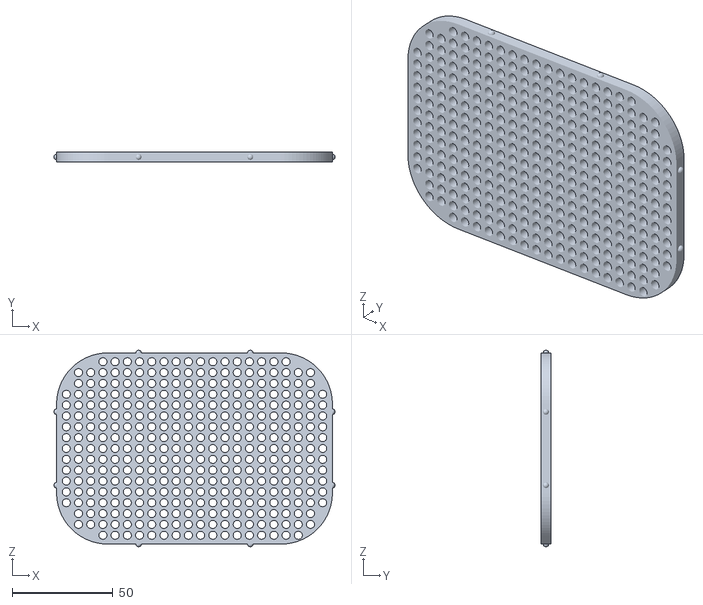
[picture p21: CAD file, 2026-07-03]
hardware/stl/front_lid_zbox_clear.stl
139.2 x 5.00 x 97.4

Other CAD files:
hardware/stl/speaker_holder_left_zbox_clear.stl

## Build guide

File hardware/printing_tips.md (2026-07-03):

# 3D Printing Tips

Practical print orientation and support notes for the zBox enclosure parts.
Part names follow the CAD/STL naming used in this repository.

## Part Settings

| Part | Print orientation | Supports | Notes |
| --- | --- | --- | --- |
| `front_lid` | Any convenient orientation | No | The part should print cleanly without support material. |
| `nfc_card_slot` | Place it on the bottom/base face | Usually no | Keep the base flat on the build plate for the cleanest fit. |
| `rear_lid` | Place it on the inner face | Yes | Supports are needed around the ESP cutout. |
| `shell` | Place it on the front face | Yes | The front face is the side closer to the button cutout. |
| `speaker_holders` | Place each holder on its side, using the largest flat face | Usually no | This gives the part the most stable contact with the build plate. |
| `wall` | Place it on the bottom/base face | Usually no | Use the flat base as the build-plate contact surface. |

## General Notes

- Preview generated supports in the slicer before printing.
- Keep visible exterior faces away from support contact whenever possible.
- If the fit is tight, test-fit the lids and NFC card slot before final assembly.

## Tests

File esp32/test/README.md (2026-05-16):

# zBox — test documentation

## Overview

The firmware test strategy is now host-side only.

All maintained tests live under `esp32/test/test_*` and run in PlatformIO `native` environments. There are no serial integration tests, tester-firmware flows, or manual hardware test scripts in this repository anymore.

## Running

```bash
cd esp32
pio platform install native   # one-time
pio test -e native -v
pio test -e native_btndec -v
```

## Suites

### `test_uid_format` (7 tests)

Tests `uidToString()` formatting rules for NFC UIDs:

- 4-byte and 7-byte UIDs
- uppercase hex output
- zero padding regression cases
- all-zero and single-byte inputs

### `test_volume` (21 tests)

Tests pure helpers:

- output-volume clamp/step logic
- battery-to-bars thresholds

### `test_mapping` (8 tests)

Tests JSON mapping parsing behavior:

- valid and invalid `mappings.json`
- empty and missing `figurines`
- lookup for known and unknown UIDs

### `test_reducer` (21 tests)

Tests the pure `reduce(AppState, Event, now_ms)` state machine:

- boot readiness and startup autoplay
- `PlaybackModeLoaded`, `MappingsLoaded`, `VolumeLoaded`
- NFC playback and music playback transitions
- play/pause/next/prev behavior
- BT headphones mode lifecycle
- sleep flow, power-off sound, BT stop-before-sleep
- battery preview and volume overlay deadlines

### `test_bt_adapter` (3 tests)

Tests the BT adapter contract:

- start while headphones are already connected
- connection-edge event emission
- stop completion without false disconnect events

### `test_audio_adapter` (7 tests)

Tests critical audio-adapter failure paths:

- missing NFC mapping
- missing music index
- missing or unknown system sound
- queue rejection for playback/system sound
- best-effort `AudioStopped` on failed stop enqueue

### `test_dispatcher` (4 tests)

Tests dispatcher timeout handling:

- NFC playback start timeout
- system-sound timeout
- stop timeout
- pending registry cleanup after feedback

### `test_button_decoder` (27 tests, `native_btndec`)

Tests pure button decoding:

- single and double click behavior
- short `BTN_C` / `BTN_D` volume actions
- long `BTN_A` -> BT headphones mode request
- long `BTN_D` -> battery preview request
- long `BTN_B` -> mode toggle
- long `BTN_C` and emergency hold sleep paths
- combo `A+B` and `C+D`
- debounce and swallowed-release regressions

## Scope

These tests cover the maintained architectural contracts:

- pure reducer logic
- dispatcher timeout behavior
- adapter-level failure handling
- button decoding
- target firmware compilation via `pio run -e lolin_d32_pro`

They do not simulate real ESP32 peripherals or radio stacks. NFC silicon behavior, SD timing, deep sleep wake causes, and actual Bluetooth stack behavior still require manual hardware validation outside this repo.

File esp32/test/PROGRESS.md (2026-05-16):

# zBox Test Progress

## Current policy

The repository maintains host-side native tests only.

Removed:

- serial integration tests
- tester-firmware button automation
- manual NFC pytest flows

## Current suites

### `native`

- `test_uid_format`
- `test_mapping`
- `test_volume`
- `test_reducer`
- `test_bt_adapter`
- `test_audio_adapter`
- `test_dispatcher`

### `native_btndec`

- `test_button_decoder`

## Run

```bash
cd esp32
pio test -e native -v
pio test -e native_btndec -v
```

## Last known verification target

- host-side native suites should be green
- firmware should still build with `pio run -e lolin_d32_pro`

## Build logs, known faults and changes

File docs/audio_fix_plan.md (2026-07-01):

# Plan: Fix NS audio stutter via PCM elasticity buffer + drain task

## Context

The local-speaker (NS / I2S) path stutters ("efekt jak cofnięta płyta"), most visibly on
`b8bb84fa_W_ukladzie_slonecznym.mp3`. The hypothesis in `docs/audio-stutter-fix.md` was that the
**file encoding** is at fault (and that a 96 KB PCM buffer + drain task already exists).
Investigation disproved both.

### What the investigation found (evidence)

Downloaded the real files from the running server (`GET /api/stream/file/<name>`) and analysed
them with ffprobe + custom frame parsers:

| File | Bitrate | Stutters? | Notes |
|---|---|---|---|
| `b8bb84fa_W_ukladzie_slonecznym.mp3` | 64k CBR | **YES** | clean |
| `9383471d_babajaga.mp3` | 64k CBR | NO (doc was wrong) | clean |
| `9625e346_Mucha_w_Mucholocie.mp3` | ~192k VBR | NO | clean |

- **The stuttering file is not defectively encoded.** Standard 44.1 kHz / joint‑stereo (MS) /
  64 kbps CBR MP3, **structurally identical to the non‑stuttering `babajaga`**: same 44‑byte
  ID3v2, no embedded art, no inter‑frame gaps, no trailing junk, **0 ffmpeg decode errors**, and
  it uses the bit reservoir *less* than babajaga. Bitrate, stereo mode and reservoir depth are
  ruled out.
- **The doc's firmware premise is stale.** On branch `modul_ns` there is **no PCM buffer and no
  drain task** for NS. The NS path is fully synchronous: `SD read → Helix decode →
  BeatTracker (beat+volume) → i2s.write` in one loop (`esp32/src/audio/audio.cpp:642-725`).

### Most probable root cause (to be CONFIRMED on device, not yet proven)

Firmware buffering fragility, file‑independent. I2S DMA is left at the audio‑tools default
**6 × 512 = 3072 B ≈ 17 ms** (`ensureLocalTransport()` only sets pins, never
`buffer_count`/`buffer_size`, `audio.cpp:412-434`). I2S writes block
(`ticks_to_wait_write = portMAX_DELAY`), so nothing decouples a stall from the DAC. SD reads
already spike to **21–26 ms (> 17 ms buffer)**, the audio task shares **core 1 with NFC
SoftSPI** (sched_gap), and every transition blocks on a synchronous 40 ms `writeSilenceGap`.
Any gap > ~17 ms between `i2s.write()` calls underruns the DAC → stutter. Which track shows it
"most" is likely SD sector layout/fragmentation, which is why re‑copying a file can *appear* to
fix it.

> This is a strong hypothesis but **must be confirmed with on‑device telemetry** (Stage 0 +
> Stage 1) before we accept it as the root cause.

### Library‑usage issues found

- `mp3Decoder.addNotifyAudioChange(audioInfoLogger)` (`audio.cpp:790`) only **logs**; never
  calls `i2s.setAudioInfo()`. I2S is hardcoded 44.1 kHz/2/16 — fine for current files, wrong
  pitch for any other rate.
- I2S DMA depth never configured (too shallow).
- Per‑chunk `vTaskDelay(pdMS_TO_TICKS(1))` (`audio.cpp:724`); idiomatic audio‑tools pacing is
  sink back‑pressure, not a fixed sleep.

### Goal

Decouple SD/decode from the DAC with a PCM elasticity ring buffer drained by a dedicated task,
so SD‑read spikes and core‑1 jitter no longer underrun I2S — **delivered in small, verifiable
stages**, each independently testable, so we can attribute every audio change. Also (later,
separately) forward decoder AudioInfo to I2S, and restore LEDs. **Must avoid the previous
`tx_chan != nullptr` panic** (race between drain and I2S reconfiguration).

All work is in `esp32/src/audio/audio.cpp` (+ `esp32/src/zbox_config.h`). Implementer must load
`.claude/skills/firmware-dev/SKILL.md` and the `embedded-refactoring` skill first (RTOS tasks,
ISR/core pinning, timing‑sensitive code).

---

## Staged plan

Each stage is a separate commit, built + soak‑tested before the next. If a stage regresses
audio, we know exactly which change did it.

### Stage 0 — Baseline (no code change beyond logging)
Capture the "before" so the fix is measurable. With current firmware, record for the
problem path:
- `[AUDIO_TEL]` (SD B/s, dec_in, drops, max_read, max_decode_write, max_total, max_sched_gap,
  slow_* counters),
- `[DIAG] HWM` (loop/led/audio/nfc) and heap / largest block,
- exact track path + audible symptom (timestamped),
- repro recipe (which file, fast‑switch or steady playback).

Deliverable: a short "baseline" note appended here with the actual numbers for
`b8bb84fa_W_ukladzie_slonecznym.mp3`. Do not move on until we have it.

### Stage 1 — Deepen I2S DMA + extend telemetry (smallest fix first)
- In `ensureLocalTransport` set `cfg.buffer_count` / `cfg.buffer_size` explicitly (e.g.
  `buffer_count 16–24`, `buffer_size 512` → ~45–70 ms) before `i2s.begin(cfg)`.
- **Do not introduce a `[PCM]` line here** — there is no ring yet, so `[PCM] used/min/max`
  would be fake telemetry. Instead just **extend `[AUDIO_TEL]`** (`audio.cpp:697-719`) with the
  DMA depth / any extra sched_gap/read maxima needed. The genuine `[PCM] used/min/max/underruns`
  line arrives in Stage 2 with the real ring.
- Re‑test the problem path. **This alone may materially reduce or eliminate the stutter** and, if
  so, confirms the buffering hypothesis cheaply. Keep this commit even if Stage 2 follows — it is
  defence in depth.

### Stage 2 — Local PCM ring + drain task (the core decoupling, NO AudioInfo reconfig)
This is the heart of the fix. I2S stays at fixed 44.1 kHz/2/16 (current behaviour); **no
`setAudioInfo()` yet** — that is Stage 3.

All of Stage 2 lives behind a compile‑time flag **`ENABLE_LOCAL_PCM_DRAIN`** (in
`zbox_config.h`, see Feature flag §). When off → the current synchronous path; when on → the
ring + drain path. This single commit must include the **minimal lifecycle safety** (2f), so the
drain task is never flashed without BT guard + sleep park. Stage 4 only *extends* hardening/tests.

**2a. `LocalPcmBufferSink` (PSRAM ring).** Model on existing `BtPcmBufferSink`
(`audio.cpp:209-331`): `portMUX`‑guarded ring (multi‑core safe), `heap_caps_malloc(SPIRAM)` with
internal fallback, `write()` that blocks via `vTaskDelay(1)` until room (feed self‑paces on
ring‑full back‑pressure), `clear()`, `readSome()`, `usedBytes()`.
- **`write()` must never block forever when the drain is parked.** During normal NS playback,
  blocking until room is correct. But on stop / BT switch / sleep / reset the drain stops
  consuming, so a full ring would hang the audio task inside `decoderStream.write()`. So `write()`
  exits early (short timeout, drop remaining) whenever `drainStop`, `activeSinkIsBt`,
  `reconfiguring`, or a `sinkDisabled` flag is set. The mode transitions (2d, 2f, Stage 4) must
  **set `sinkDisabled`/pause the drain BEFORE clearing the ring**, so the audio task is released
  from `write()` first and can't get stuck during the switch. (Mirror `BtPcmBufferSink`'s
  existing `BT_PCM_WRITE_TIMEOUT_MS` bounded‑write pattern, `audio.cpp:232-248`.)
- Size constant in `zbox_config.h`. **Precise numbers** (176400 B/s for 44.1/2/16):
  `LOCAL_PCM_BUFFER_SIZE = 48 KB ≈ 272 ms`. Start the **prefill smaller** to limit latency:
  `LOCAL_PCM_PREFILL = 16 KB ≈ 91 ms` (not 50%). Note: prefill is the **start threshold only**,
  not a runtime floor — `used` will normally dip below it during steady playback. Tune both
  against measured underruns; raise only if Stage‑0/Stage‑1 spikes demand it.

**2b. Drain task.** `xTaskCreatePinnedToCore(localDrainTask, "pcm_drain", 4096, …, prio 3,
core 0)` — core 0 (with the I2S DMA ISR), off core‑1/NFC. State machine:
- IDLE (no NS playback, ring empty, **or `activeSinkIsBt`**, **or `drainStop`**) → short
  `vTaskDelay`, no I2S writes, set `parked=true`.
- PREFILL (track started) → wait until `used ≥ LOCAL_PCM_PREFILL`, then STREAM.
- STREAM → read a chunk (512–1024 B) from ring, scale volume + run beat detection (2e), write to
  I2S (mutex + lock‑ordering discipline §).
- Mid‑track empty ring → underrun: write one small silence frame to keep the DAC clocked, bump
  `pcmUnderruns`.
- Report drain‑task HWM, state, and `pcmUnderruns` + ring `used` min/max/current in the `[PCM]`
  line.

**2c. Sink rewire.**
- Local sink becomes `&localPcmSink` instead of `&i2s` everywhere `selectSink(&i2s, false)` is
  used (`audio.cpp:871,881`, init `788`).
- `BeatTracker` stops doing volume scaling for the NS path (see Volume path §).
- Remove the NS‑branch `vTaskDelay(1)` (`audio.cpp:724`) → `taskYIELD()`; pacing now comes from
  `LocalPcmBufferSink::write` back‑pressure.

**2d. Transition/reset — explicit, with mandatory double clear.** The old worry (doc suspect #1)
is that `decoderStream.end()` flushes a PCM tail *after* the first clear. So the clear after
`end()` is **mandatory, not optional**. The exact NS sequence in
`resetDecoderForNewTrack`/`flushStoppedPlayback` (`audio.cpp:392-410`), replacing the synchronous
`writeSilenceGap` I2S flush:
```
set sinkDisabled + pause drain  // releases audio task from write(), stops drain touching ring/I2S
localPcmSink.clear()
decoderStream.end()
localPcmSink.clear()            // MANDATORY: drop tail emitted by end()
decoderStream.begin()
rearm prefill                   // drain re-enters PREFILL
clear sinkDisabled + resume drain   // streams once new PCM passes prefill
```
Order matters: `sinkDisabled`/pause is set **before** the first `clear()` so the audio task
cannot be stuck in `LocalPcmBufferSink::write()` while the ring is being reset.
`clearActiveTransport()` (`audio.cpp:382-390`) also gains `localPcmSink.clear()` for the BT/stop
paths.

**2e. Beat/energy detection → drain task (part of THIS stage, not free).** Moving detection to
playback time also moves `millis()`, `g_audioEnergy`, `g_beatDetected` and the beat history onto
core 0/the drain task. Keep the `detectBeat` math (`audio.cpp:122-150`) identical, just
relocated to run on raw PCM in the drain loop. Verify the LED globals are accessed cross‑task the
same way they are today (they are already `volatile` and written from the audio task → either
confirm that is the existing accepted single‑writer pattern, now with the writer being the drain
task, or guard them). LED timing must be verified on device as part of Stage 2 (see Verification).

**2f. Minimal lifecycle safety (must ship in this commit).**
- BT guard: drain STREAM gated on `!activeSinkIsBt`; on local→BT clear ring + park, on BT→local
  resume (the full BT switch wiring is exercised in Stage 4, but the gate exists now).
- Sleep park: `audioDeleteTaskForSleep` signals `drainStop`, waits (bounded) for `parked`, then
  deletes both tasks. No `vTaskDelete` of the drain task while it may hold `i2sMutex` / be in
  `i2s.write`. (Bounded‑timeout + diagnostics detailed in Stage 4 / Teardown §.)

### Stage 3 — Safe AudioInfo forwarding (SEPARATE, because it caused the prior panic)
Only after Stage 2 is stable. `setAudioInfo` fires *inside* `decoderStream.write()` (audio‑task
context), concurrent with the drain task — this is exactly what produced `tx_chan != nullptr`.
- Replace the log‑only `AudioInfoLogger` so that on a SR/channel change it follows the
  **park‑then‑reconfigure** sequence (no nested locks, see Lock ordering §):
  ```
  set reconfiguring
  wait (bounded) for drain to report parked   // drain out of i2s.write
  localPcmSink.clear()                         // old-rate PCM, ring mux only, released here
  take i2sMutex                                // ring mux already released — no nesting
  i2s.setAudioInfo(info)
  release i2sMutex
  update cached rate
  rearm prefill
  clear reconfiguring                          // drain resumes
  ```
  The `i2sMutex` around `setAudioInfo` is **mandatory even though the drain is parked** — it is
  the invariant that all `i2s.*` calls hold the mutex; do not skip it just because the drain is
  paused. There is no nesting because the ring `clear()` has already acquired+released the ring
  mux before `i2sMutex` is taken.
- Gate so this is a no‑op when the new info equals the current (the common 44.1/2/16 case → no
  reconfig, no risk). Because this runs on the audio task while waiting on the drain task, ensure
  the bounded wait can't deadlock if the drain is blocked in `i2s.write` (same diagnostics as the
  teardown handshake).
- Ship with the explicit non‑44.1 kHz test (Verification). If it can't be made reliably safe,
  Stage 2 already fixes the stutter; Stage 3 can be deferred without losing the fix.

### Stage 4 — Lifecycle hardening + full test matrix
The minimal BT guard + sleep park already shipped in Stage 2f. Stage 4 makes them robust and
exercises every path.
- **BT switch wiring:** on local→BT (`audioStartBtHeadphonesMode`, `audio.cpp:858-866`) clear
  local ring + park drain; on BT→local (`audioStopBtHeadphonesMode`, `868-884`) resume. BT path
  (`btFrameSink`/`btPcmSink`/A2DP callback) stays untouched.
- **Sleep teardown** (`audioDeleteTaskForSleep`, `audio.cpp:840-845`): signal `drainStop` → wait
  for `parked` with a **bounded timeout**. Two outcomes:
  - *Parked within timeout (normal):* drain is provably out of `i2s.write`/`i2sMutex` → clean
    teardown: delete audio task + drain task, tear down I2S.
  - *Timeout expires (drain stuck, e.g. in `i2s.write` with the driver wedged):* we do **not**
    know the task is safe to delete, so **do not fake a clean teardown**. Log **CRIT** with drain
    state + drain HWM + heap/largest block, **do not `vTaskDelete` the drain task**, and fall
    back to the safest available path instead of a normal sleep — e.g. abort the sleep
    (controlled), or go straight to deep sleep / device restart that resets the I2S peripheral
    wholesale. Pick one explicitly during implementation; the invariant is: never delete a task
    that may hold `i2sMutex` / be blocked in `i2s.write(portMAX_DELAY)` (the deadlock/`tx_chan`
    trap), and never report success on a teardown that didn't actually quiesce.
- **Wake:** recreate tasks and (re)init I2S in the same order as today; drain starts IDLE until a
  PLAY arrives.

---

## Cross‑cutting design rules

### Feature flag / rollback (point 8)
Compile‑time `#define ENABLE_LOCAL_PCM_DRAIN` in `zbox_config.h`. Off → today's synchronous NS
path (BeatTracker → `&i2s` directly, no drain task, no ring). On → ring + drain path. Lets us
flash both and A/B them, and gives an instant emergency rollback without reverting code. Keep the
old path compiling until Stage 2 has soaked.
- **Default = `false`** for the first committed (compiling) Stage‑2 commit — `main`/the shared
  branch keeps the proven synchronous path. Flip to `true` only on the test branch / test flash
  while validating, and flip the default to `true` only after the full soak matrix passes.

### I2S mutex discipline + lock ordering (points 3, 4)
A single `i2sMutex` guards **only** `i2s.write()`, `i2s.setAudioInfo()`, `i2s.begin()`.
- Do **not** hold it during ring read or volume scaling — only wrap the actual I2S call.
- **No path ever holds the ring mux and the `i2sMutex` at the same time.** The two locks are
  never nested in either direction. Concretely:
  - Drain task: `readSome()` acquires + releases the ring `portMUX`, copying into a local buffer;
    **only after the ring mux is released** does it take `i2sMutex` to write. It must never block
    on `i2sMutex` while holding the ring mux.
  - Stage 3 reconfig does **not** nest either. It does not take `i2sMutex` and then touch the
    ring. Instead it **parks the drain task first** (sets `reconfiguring`/`drainPause`, waits for
    `parked`), and only then — with the drain task guaranteed out of both locks — clears the ring
    and calls `i2s.setAudioInfo()`, then rearms prefill and resumes the drain. So ring clear and
    `setAudioInfo` happen with no contending lock holder at all.
  - Any future path that needs both must follow the same rule: acquire/release one fully before
    the other; nesting ring mux ↔ `i2sMutex` (in any order) is forbidden.
- Because `i2s.write` uses `portMAX_DELAY`, holding `i2sMutex` across it could block
  `setAudioInfo`/sleep/teardown; mitigate by (a) keeping I2S write chunks small (≤1 KB so each
  blocked write is bounded by ~a few ms of DMA), and (b) the bounded parked‑flag handshake for
  teardown (Stage 4) rather than yanking the task.
- Log drain‑task HWM and a "parked" indicator.

### Shared lifecycle/state flags must be thread‑safe (point 2)
A new task on core 0 reads state mutated from other contexts (audio task, BT/sleep callers):
`activeSinkIsBt`, `drainStop`, `sinkDisabled`, `parked`, `reconfiguring`, drain state, and any
`s_isPlaying`‑style gating the drain consults. `volatile` is the **minimum**, not a full sync
model — choose the mechanism by role:
- **Handshake / sequencing state** (`drainStop`, `sinkDisabled`, `reconfiguring`, `parked`,
  drainState): these gate ordered teardown/reconfig sequences, so a torn read or reorder breaks
  the sequence. Use a **stronger primitive**, preferably one of:
  - a small dedicated `portMUX` taken for the snapshot/update of the lifecycle flag set, or
  - **FreeRTOS task notifications / an event group** to command the drain (stop/pause/reconfig)
    and to signal `parked` back — this gives a clean, race‑free handshake without busy‑polling a
    `volatile`.
- **Simple telemetry‑only flags** (where a one‑cycle race doesn't corrupt a sequence) may stay
  `volatile` single‑word with one writer.
- `activeSinkIsBt` must not stay a plain cross‑core `bool` read without a barrier — make it
  `volatile`/atomic or gate the sink behind the same critical section that switches it. One writer
  per flag; the drain task is read‑only on the ones it doesn't own and owns `parked` exclusively.
- Today's loose globals are acceptable only because they were single‑task; the drain task breaks
  that assumption, so audit every flag it touches.

### Volume path (point 6)
- **BT:** unchanged — keeps scaling as today.
- **NS:** ring holds **raw** decoded PCM; the **drain task** applies volume just before I2S,
  reading the existing `volatile int outputVolumePercent` (already updated by
  `audioSetOutputVolumePercent`, `audio.cpp:847-856`). No locks, no allocation (reuse a
  stack/static scratch like `BeatTracker::scratch_`). Result: near‑instant NS volume response.
- `BeatTracker::setVolumePercent` must no longer affect the NS sink output (it may keep the value
  only if beat detection needs it — current detection is energy‑based and volume‑independent, so
  it does not).

### Beat LED placement (point 5 — PRODUCT DECISION, default chosen, flag for review)
If beat detection stays in `BeatTracker` (decode time), LEDs lead the audio by ~the buffer
latency (≤ ~272 ms; ~91 ms once only prefill is buffered). For a music toy this *may* be
visible. **Default: move beat/energy detection into the drain task** (implemented in Stage 2e),
computed on raw PCM right before volume+I2S, so LEDs are sample‑aligned with sound. This is more
than a CPU cost — it relocates `millis()`/`g_audioEnergy`/`g_beatDetected`/history onto core 0
(see 2e for the cross‑task safety check). LED timing is verified on device in Stage 2. If the
drain‑task CPU cost turns out to matter, fall back to decode‑time detection and accept the lead.
Confirm this choice during review.

---

## Critical files
- `esp32/src/audio/audio.cpp` — `LocalPcmBufferSink`, drain task + state machine, `i2sMutex`,
  sink rewire, volume relocation, beat relocation, `clearActiveTransport`/reset changes, BT‑guard,
  sleep teardown handshake, `[PCM]` telemetry, (Stage 3) AudioInfo forwarding. Reuse:
  `BtPcmBufferSink` (209‑331), `BeatTracker` (66‑161), `ensureLocalTransport` (412‑434),
  `selectSink` (375‑380), reset (392‑410), feed loop (642‑725), `audioInit` (776‑795),
  `audioDeleteTaskForSleep` (840‑845), BT mode (858‑884), volume (847‑856).
- `esp32/src/zbox_config.h` — `LOCAL_PCM_BUFFER_SIZE` (48 KB), `LOCAL_PCM_PREFILL` (16 KB), I2S
  DMA depth (if defined here); restore `ENABLE_LEDS true`.

## Verification (per stage + full matrix)
Build/test gates each stage:
1. `pio run -e lolin_d32_pro` (build).
2. `pio test -e native` (31/31 must stay green — they cover the reducer, not audio).

On‑device matrix (Stage 1 onward; mandatory before declaring done):
3. Problem track `b8bb84fa…` end‑to‑end **and** fast next/previous for several minutes. Success
   criteria (prefill is a start threshold, **not** a runtime floor — `used` will normally dip
   below it during steady playback):
   - `pcmUnderruns == 0`,
   - ring `min_used > 0` during stable playback,
   - `used` only reaches 0 at stop / transition / sleep / BT switch,
   - log `used` min/max/current (don't require `used ≥ prefill`),
   - no audible stutter. A/B vs `babajaga` & `mucha`.
4. **pause / resume / stop** mid‑playback (no clicks, no stale tail, ring cleared on stop).
5. **BT on/off** both during playback and while idle; verify local drain parks under BT and
   resumes after, no I2S contention.
6. **sleep/wake** both while idle and right after playback; confirm clean drain‑task park (no
   deadlock, no `tx_chan` panic) and correct task/I2S re‑init order on wake.
7. **20–30 min soak** test on the problem track / playlist.
8. Throughout, log and check **audio‑task HWM + drain‑task HWM + heap/largest block** (no
   downward drift; stacks have margin).
9. (Stage 3 only) play a non‑44.1 kHz MP3 (or synthesise one) → correct pitch, clean
   `[AUDIO] Decoder: SR=…` → I2S reconfig with no panic.
10. Volume change mid‑track → near‑instant NS response; beat LEDs aligned per chosen placement.
11. Update `docs/audio-stutter-fix.md` to reflect the confirmed root cause and the implemented fix.

## Notes / risks
- HEAD warns "nie dotykać bo wybuchnie" — staged commits + per‑stage soak are the safeguard.
- The `i2sMutex` + parked‑flag handshake is the specific guard against the prior
  `tx_chan != nullptr` race; never call any `i2s.*` outside the mutex once the drain task exists,
  and never delete the drain task while it may be inside `i2s.write`.
- Backend encoding is **not** changed — it is not the cause. (Raising backend bitrate from 64k in
  `server/routers/admin.py` is unrelated quality, not a stutter fix.)

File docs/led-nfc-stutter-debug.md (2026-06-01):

# LED/NFC stutter debug notes

Date: 2026-05-30

Symptom: LED animation is smooth for the first 5-8 seconds after boot, then starts stuttering roughly every 2-3 seconds.

Observed tests:
- With NFC fully disabled via `ENABLE_NFC false`, LED animation did not stutter.
- Re-enabling NFC and removing `ledSuspendTask()` from the regular `readNfcTag()` scan was not sufficient; the animation still stuttered.

Current test change:
- `ENABLE_NFC` is set back to `true` in `esp32/src/zbox_config.h`.
- Experiments that did not fix the stutter:
  - regular NFC reads without `ledSuspendTask()`
  - NFC task priority lowered to `0`
  - periodic NFC task pinned to core 0
  - `NFC_PASSIVE_ACTIVATION_RETRIES = 0x00` and `NFC_READ_TIMEOUT_MS = 1`
- Current direction: restore NFC behavior close to `for_github` and test a pinned FastLED version instead of allowing PlatformIO to resolve `^3.6.0` to `3.10.3`.
- FastLED `3.6.0` was tried but does not build with the current ESP-IDF 5.x platform; the current pinned test version is `3.9.16`.
- NFC regular reads, init, prescan, and powerdown use `nfcCriticalBegin()` / `nfcCriticalEnd()`.
- NFC task is back on core 1, priority 1. LED task priority is `1`.

If this breaks the build or behaves worse:
1. In `esp32/platformio.ini`, change the pinned `fastled/FastLED@...` line back to `fastled/FastLED@^3.6.0`.
2. Rebuild with `pio run -e lolin_d32_pro`.

Useful logs to check:
- `[LED] ... frame gap=...`
- `[LED] FastLED.show mode=... dt=...`
- `[NFC] read critical dt=... found=...`

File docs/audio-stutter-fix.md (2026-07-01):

# Audio NS stutter — status diagnozy i plan

Data: 2026-06-29

## Symptom

Na ścieżce NS (lokalny I2S / głośnik) audio wyraźnie przerywa. Problem jest
łatwy do odtworzenia po szybkim przełączaniu utworów, szczególnie w okolicy:

```text
/music/9383471d_babajaga.mp3
```

Opis odsłuchowy: przerywanie / efekt jak cofnięta płyta.

## Co już wiemy z logów

### Wykluczone lub mocno osłabione hipotezy

1. **To nie wygląda na wyciek pamięci.**
   Heap i largest block są stabilne w trakcie testów.

2. **LED/FastLED nie jest główną przyczyną.**
   Test z `ENABLE_LEDS=false` nadal przerywa. W logach:

   ```text
   [DIAG] HWM loop=5924 led=0 audio=5460 nfc=0
   ```

   Czyli task LED nie działa, a symptom zostaje.

3. **Prosty underrun wejścia MP3/SD nie tłumaczy aktualnego objawu.**
   Po wyłączeniu LED:

   ```text
   [AUDIO_TEL] SD=8071-9203 B/s dec_in=8071-9203 B/s drops=0 max_read=21-26
   ```

   Nie ma `drops`, `max_read` jest umiarkowany, heap stabilny.

4. **Eksperyment z dynamicznym przekazywaniem `AudioInfo` do I2S był błędny.**
   Spowodował panic:

   ```text
   assert failed ... I2SDriverESP32V1::writeBytes ... (tx_chan != nullptr)
   ```

   Przyczyna: race między drain taskiem lokalnego bufora PCM a rekonfiguracją I2S.
   Ta ścieżka została wycofana i nie powinna wracać bez synchronizacji.

### Co nadal jest podejrzane

1. **Reset dekodera / resztki PCM przy szybkim przełączaniu.**
   Aktualna sekwencja robi:

   ```cpp
   clearActiveTransport();
   decoderStream.end();
   writeSilenceGap(...);
   decoderStream.begin();
   ```

   Problem: `decoderStream.end()` może jeszcze wypchnąć końcówkę starego dekodera
   do aktualnego sinka. Przy bezpośrednim I2S mogło to być mniej widoczne, ale przy
   lokalnym buforze PCM takie bajty mogą zostać zakolejkowane przed następnym utworem.

2. **Konkretny plik MP3 może mieć cechę, której Helix/audio-tools nie obsługuje dobrze.**
   Do sprawdzenia lokalnie na pliku z SD:

   ```text
   /music/9383471d_babajaga.mp3
   ```

   Szczególnie: VBR, Xing/LAME header, uszkodzone ramki, zmiana sample rate,
   nietypowy encoder, bardzo niski bitrate.

3. **Lokalny bufor PCM może maskować telemetrię, ale nie usuwać artefaktu.**
   `drops=0` oznacza tylko, że decoder przyjął wejściowe bajty MP3. Nie mówi jeszcze,
   czy PCM wychodzący z dekodera jest poprawny i czy reset nie miesza ramek między
   utworami.

## Aktualne zmiany testowe w firmware

### `audio.cpp`

- lokalny bufor PCM dla NS: `LOCAL_PCM_BUFFER_SIZE = 96 KB`
- I2S DMA: `buffer_count=32`, `buffer_size=512`
- odczyt MP3 dla NS: `LOCAL_AUDIO_READ_CHUNK_SIZE = 512`
- telemetry: osobne `read_ms`, `decode_write_ms`, `sched_gap_ms`
- próg utrzymywania lokalnego bufora PCM podniesiony testowo do `80 KB`

### `zbox_config.h`

Testowo:

```cpp
#define ENABLE_LEDS false
```

To jest wyłącznie test diagnostyczny. Po zakończeniu diagnozy trzeba przywrócić LED-y.

## Następny plan

### Krok 1 — sprawdzić plik MP3

Skopiować z karty SD problematyczny plik i sprawdzić:

```bash
ffprobe -hide_banner -show_format -show_streams 9383471d_babajaga.mp3
ffmpeg -v warning -i 9383471d_babajaga.mp3 -f null -
```

Jeśli `ffmpeg` pokaże błędy ramek albo nietypowe parametry, zrobić testową konwersję:

```bash
ffmpeg -i 9383471d_babajaga.mp3 -ar 44100 -ac 2 -b:a 128k babajaga_fixed.mp3
```

I sprawdzić, czy `babajaga_fixed.mp3` nadal przerywa na urządzeniu.

### Krok 2 — instrumentacja lokalnego PCM

Dodać krótką telemetrię bufora PCM, ale bez spamowania UART:

```text
[PCM] active=1 used=xxxxx min=xxxxx max=xxxxx underruns=n
```

Cel: zobaczyć, czy podczas słyszalnego przerywania `used` spada do zera albo czy
artefakt występuje mimo pełnego bufora.

### Krok 3 — bezpieczny test resetu dekodera

Jeżeli plik MP3 jest poprawny, przetestować zmianę kolejności resetu:

```cpp
clearActiveTransport();
decoderStream.end();
clearActiveTransport();  // drop tail emitted by end()
writeSilenceGap(...);
decoderStream.begin();
```

To musi być osobny test, bo zmienia zachowanie przejścia między utworami.

### Krok 4 — jeśli reset nie pomaga

Rozważyć obejście dla NS:

- na zmianie utworu zatrzymać drain lokalnego PCM,
- wyczyścić bufor,
- zrestartować dekoder,
- dopiero po prefillu nowego utworu wznowić drain.

To wymaga ostrożnej synchronizacji, żeby nie wrócić do błędu `tx_chan != nullptr`.

## Ważna decyzja

Nie traktować już “za mały I2S DMA” jako potwierdzonego root cause. Była to sensowna
pierwsza hipoteza, ale aktualne testy z lokalnym PCM, większym buforem i wyłączonymi
LED-ami wskazują, że główny problem jest raczej w:

- konkretnym pliku MP3,
- granicy Helix/audio-tools,
- albo resetowaniu / mieszaniu PCM przy szybkiej zmianie utworów.

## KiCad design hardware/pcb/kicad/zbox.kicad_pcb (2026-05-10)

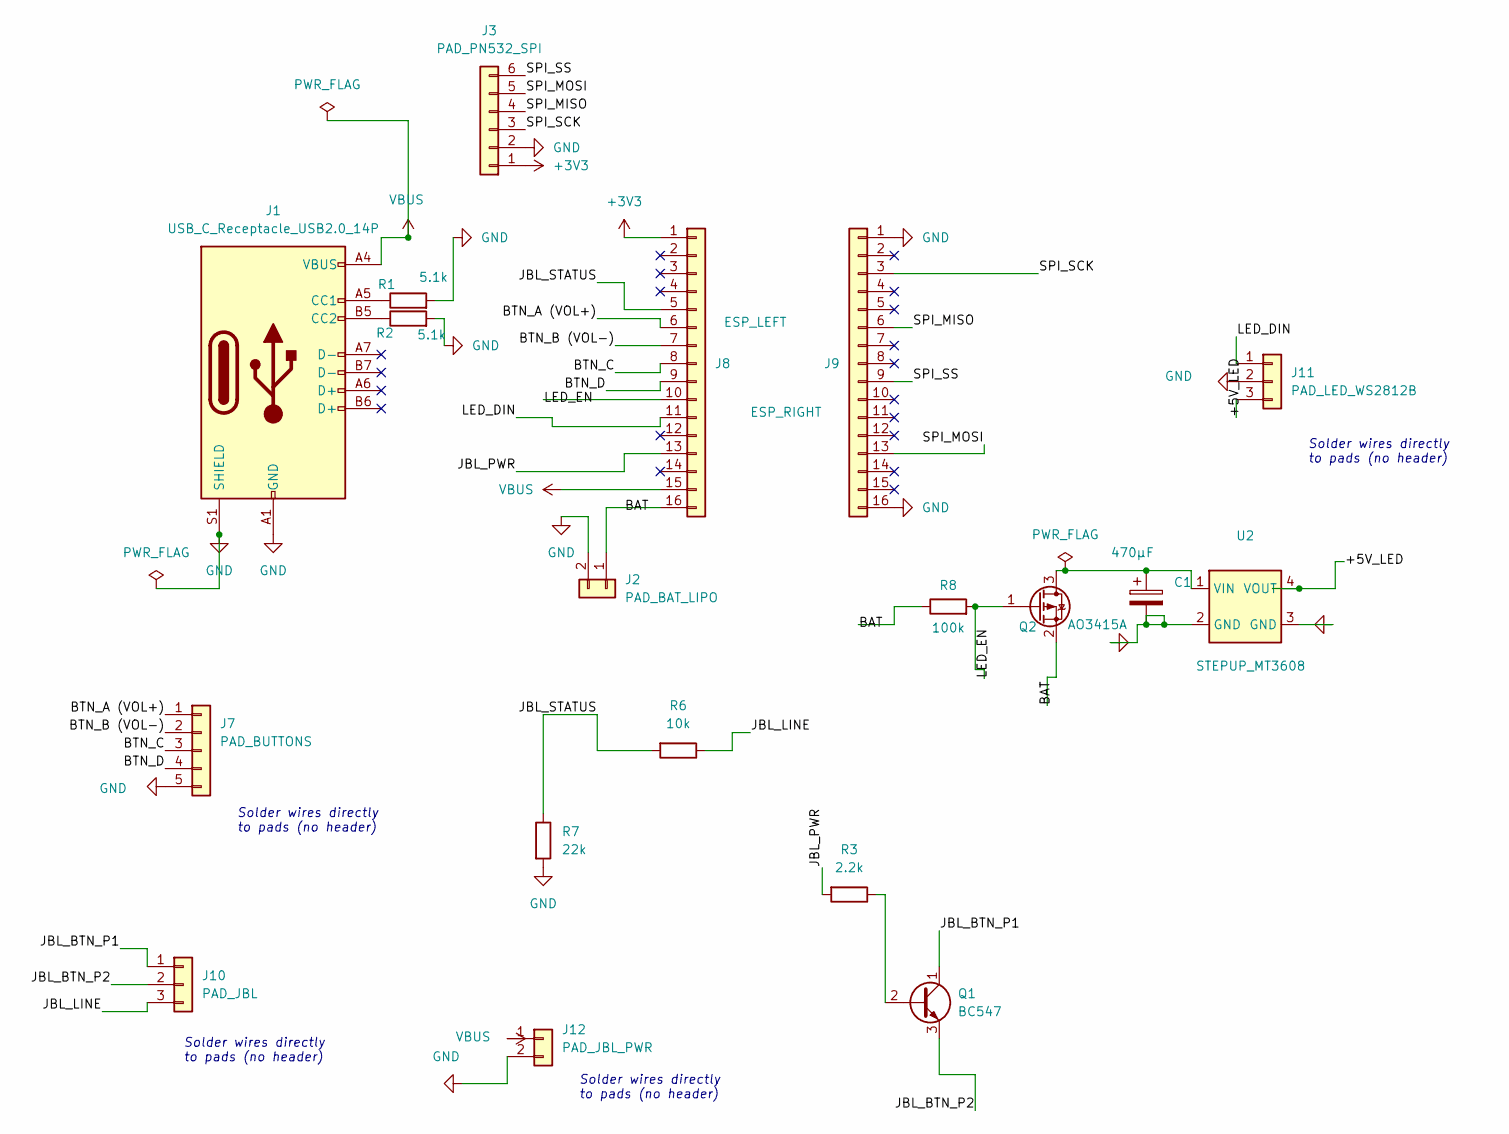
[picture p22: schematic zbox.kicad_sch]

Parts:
C1: 470µF; CP_Radial_D8.0mm_P3.50mm
J1: USB_C_Receptacle_USB2.0_14P; USB_C_Receptacle_GCT_USB4085
J2: PAD_BAT_LIPO; SolderPad_1x02_W2.2mm_H3mm_P2.7mm
J3: PAD_PN532_SPI; SolderPad_1x06_W2.2mm_H3mm_P2.7mm
J7: PAD_BUTTONS; SolderPad_1x05_W2.2mm_H3mm_P2.7mm
J8: ESP_LEFT; PinHeader_1x16_P2.54mm_Vertical
J9: ESP_RIGHT; PinHeader_1x16_P2.54mm_Vertical
J10: PAD_JBL; SolderPad_1x03_W2.2mm_H3mm_P2.7mm
J11: PAD_LED_WS2812B; SolderPad_1x03_W2.2mm_H3mm_P2.7mm
J12: PAD_JBL_PWR; SolderPad_1x02_W2.2mm_H3mm_P2.7mm
Q1: BC547; TO-92_Inline
Q2: AO3415A; SOT-23
R1, R2: 5.1k; R_Axial_DIN0207_L6.3mm_D2.5mm_P10.16mm_Horizontal
R3: 2.2k; R_Axial_DIN0207_L6.3mm_D2.5mm_P10.16mm_Horizontal
R6: 10k; R_Axial_DIN0207_L6.3mm_D2.5mm_P10.16mm_Horizontal
R7: 22k; R_Axial_DIN0207_L6.3mm_D2.5mm_P10.16mm_Horizontal
R8: 100k; R_Axial_DIN0207_L6.3mm_D2.5mm_P10.16mm_Horizontal
U2: STEPUP_MT3608; MT3608_Pancake

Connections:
+3V3: J3.1, J8.1
/+5V_LED: J11.3, U2.4 (VOUT)
/BAT: J2.1, J8.16, Q2.2 (S), R8.1
/BTN_A (VOL+): J7.1, J8.6
/BTN_B (VOL-): J7.2, J8.7
/BTN_C: J7.3, J8.8
/BTN_D: J7.4, J8.9
/JBL_BTN_P1: J10.1, Q1.1 (C)
/JBL_BTN_P2: J10.2, Q1.3 (E)
/JBL_LINE: J10.3, R6.1
/JBL_PWR: J8.13, R3.2
/JBL_STATUS: J8.5, R6.2, R7.1
/LED_DIN: J8.11, J11.1
/LED_EN: J8.10, Q2.1 (G), R8.2
/SPI_MISO: J3.4, J9.6
/SPI_MOSI: J3.5, J9.13
/SPI_SCK: J3.3, J9.3
/SPI_SS: J3.6, J9.9
GND: C1.2, J1.A1 (GND), J1.A12 (GND), J1.B1 (GND), J1.B12 (GND), J1.S1 (SHIELD), J2.2, J3.2, J7.5, J9.1, J9.16, J11.2, J12.2, R1.2, R2.2, R7.2, U2.2 (GND), U2.3 (GND)
unnamed: J1.A5 (CC1), R1.1
unnamed: J1.B5 (CC2), R2.1
unnamed: Q1.2 (B), R3.1
unnamed: C1.1, Q2.3 (D), U2.1 (VIN)
VBUS: J1.A4 (VBUS), J1.A9 (VBUS), J1.B4 (VBUS), J1.B9 (VBUS), J8.15, J12.1

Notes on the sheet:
Solder wires directly to pads (no header)

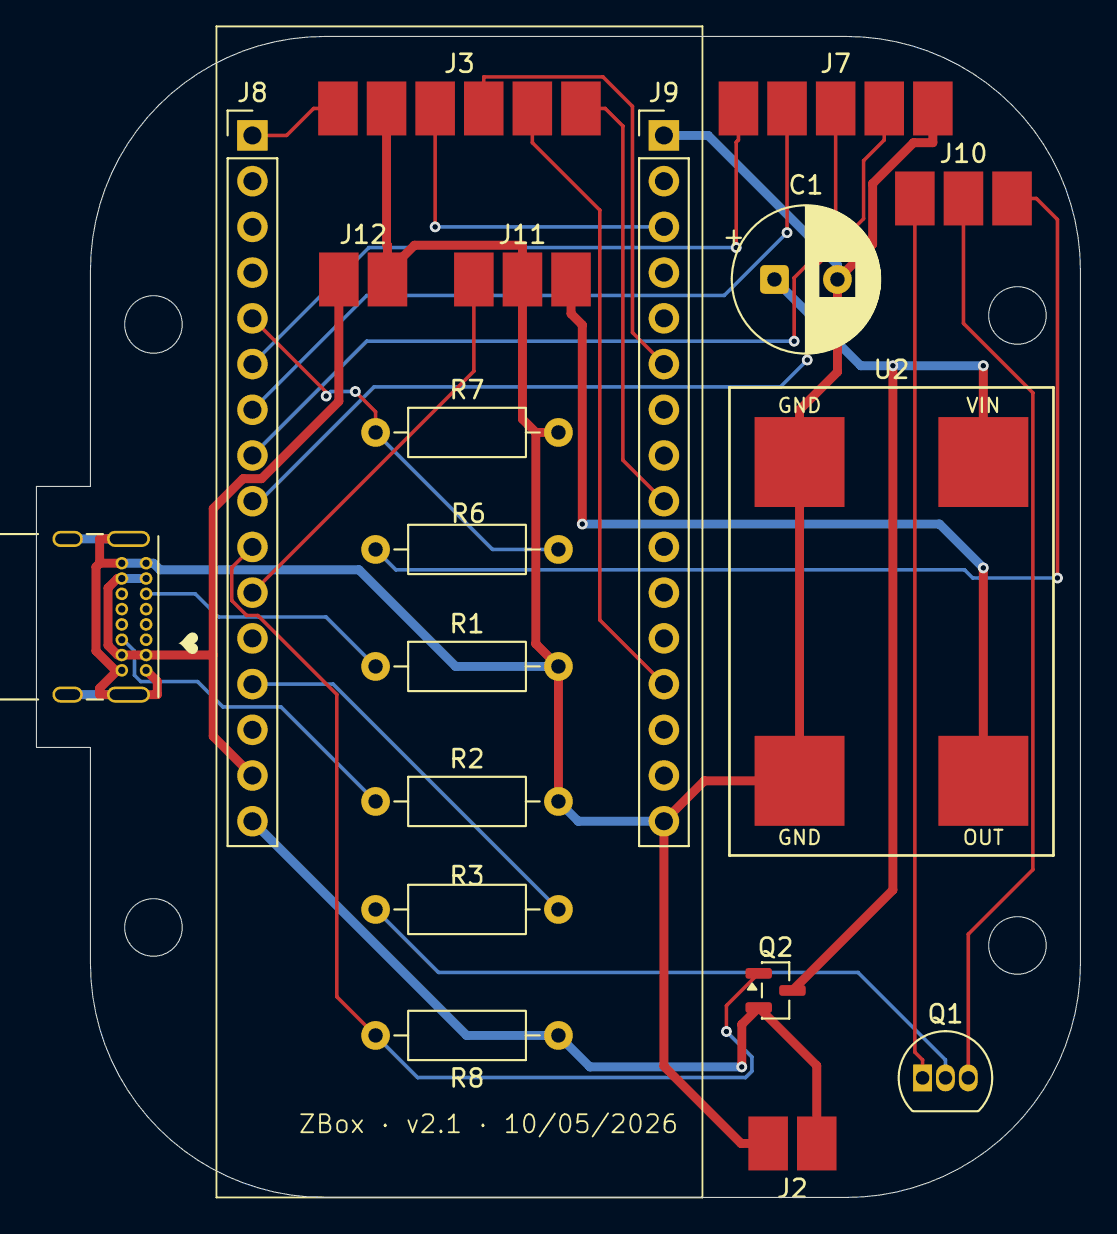
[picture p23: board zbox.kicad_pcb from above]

Board: 2 copper layers, 58.0 x 64.5 mm, 19 parts (0 on the bottom side), 24 nets.

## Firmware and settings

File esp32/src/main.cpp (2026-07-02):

#include <Arduino.h>
#include <SD.h>
#include <esp_idf_version.h>
#include <esp_sleep.h>
#include <esp_system.h>
#include <esp_task_wdt.h>

#include "audio.h"
#include "bt_adapter.h"
#include "button_adapter.h"
#include "diagnostics.h"
#include "dispatcher.h"
#include "event_queue.h"
#include "events.h"
#include "leds.h"
#include "logging.h"
#include "nfc_adapter.h"
#include "nfc_module.h"
#include "night_light.h"
#include "persistent_log.h"
#include "playback.h"
#include "peripheral_power.h"
#include "sleep.h"
#include "sd_storage.h"
#include "state.h"
#include "sync_mode.h"
#include "volume.h"
#include "zbox_config.h"

namespace {
constexpr uint32_t NFC_RETRY_SHORT_DELAYS_MS[] = {500, 1500, 3000};
constexpr uint32_t NFC_RETRY_BACKOFF_MS = 30000;
static volatile bool s_nfcWanted = false;
static volatile bool s_nfcRuntimeStarted = false;
static TaskHandle_t s_nfcBootTaskHandle = nullptr;

void deferredNfcBootTask(void *param)
{
    (void)param;
    s_nfcBootTaskHandle = xTaskGetCurrentTaskHandle();
    nfcPowerSwitchOn();
    vTaskDelay(pdMS_TO_TICKS(NFC_BOOT_INIT_DELAY_MS));
    if (!s_nfcWanted) {
        nfcBusHiZForPowerOff();
        nfcPowerSwitchOff();
        s_nfcBootTaskHandle = nullptr;
        vTaskDelete(NULL);
        return;
    }

    bool ready = false;
    uint8_t attempt = 0;
    while (s_nfcWanted) {
        attempt++;
        LOGI("[NFC] deferred init attempt %u wake_cause=%d\n",
             (unsigned)attempt, (int)esp_sleep_get_wakeup_cause());
        ready = nfcInit();
        LOGC("[BOOT] nfc_init=%s deferred=1 attempt=%u\n",
             ready ? "OK" : "FAIL", (unsigned)attempt);

        if (ready)
            break;

        uint32_t delayMs = NFC_RETRY_BACKOFF_MS;
        if (attempt <= (sizeof(NFC_RETRY_SHORT_DELAYS_MS) / sizeof(NFC_RETRY_SHORT_DELAYS_MS[0]))) {
            delayMs = NFC_RETRY_SHORT_DELAYS_MS[attempt - 1];
        }
        LOGW("[NFC] deferred init failed, retry in %lu ms\n", (unsigned long)delayMs);
        vTaskDelay(pdMS_TO_TICKS(delayMs));
    }

    if (!s_nfcWanted) {
        if (ready) {
            nfcPrepareForPowerOff();
        }
        nfcBusHiZForPowerOff();
        nfcPowerSwitchOff();
        s_nfcBootTaskHandle = nullptr;
        vTaskDelete(NULL);
        return;
    }

    vTaskDelay(pdMS_TO_TICKS(NFC_BOOT_MAPPING_DELAY_MS));
    if (!s_nfcWanted) {
        nfcPrepareForPowerOff();
        nfcBusHiZForPowerOff();
        nfcPowerSwitchOff();
        s_nfcBootTaskHandle = nullptr;
        vTaskDelete(NULL);
        return;
    }

    if (sdReady) {
        loadMappings();
        postEventFromTask(makeMappingsLoadedEvent(mappingCount()));
        LOGC("[BOOT] mappings=%d system_sounds=%d deferred=1\n",
             (int)mappingCount(), (int)systemSoundCount());
    }

    if (playbackIsNfcMode() && sdReady) {
        char preUidBuf[30] = {};
        if (nfcPrescan(preUidBuf, sizeof(preUidBuf))) {
            LOGI("NFC pre-scan: %s\n", preUidBuf);
            postEventFromTask(makeNfcPrescanEvent(true, preUidBuf));
        } else {
            LOGI("NFC pre-scan: no tag\n");
            postEventFromTask(makeNfcPrescanEvent(false, nullptr));
        }
    }

    nfcStartTask();
    s_nfcRuntimeStarted = true;
    s_nfcBootTaskHandle = nullptr;
    vTaskDelete(NULL);
}

void startDeferredNfcBootTask()
{
    if (!ENABLE_NFC) return;
    s_nfcWanted = true;
    if (s_nfcRuntimeStarted || s_nfcBootTaskHandle) return;
    xTaskCreatePinnedToCore(deferredNfcBootTask, "nfc_boot", 4096, NULL, 1, &s_nfcBootTaskHandle, 1);
}

void stopNfcForMusicMode()
{
    if (!ENABLE_NFC) return;
    if (!s_nfcWanted && !s_nfcRuntimeStarted && !nfcIsReady()) return;
    s_nfcWanted = false;
    nfcStopTaskForSleep();
    s_nfcRuntimeStarted = false;
    nfcPrepareForPowerOff();
    nfcBusHiZForPowerOff();
    nfcPowerSwitchOff();
}

void syncNfcToPlaybackMode(PlaybackMode mode)
{
    if (!ENABLE_NFC || runtimeIsNightLight()) return;
    if (mode == PlaybackMode::Nfc) {
        startDeferredNfcBootTask();
    } else {
        stopNfcForMusicMode();
    }
}
}

static void configureLoopWatchdog() {
#if ESP_IDF_VERSION_MAJOR >= 5
    esp_task_wdt_config_t wdt_cfg = {
        .timeout_ms = 15000,
        .idle_core_mask = 0,
        .trigger_panic = true
    };
    esp_task_wdt_reconfigure(&wdt_cfg);
#else
    esp_task_wdt_init(15, true);
#endif
    esp_task_wdt_add(nullptr);
}

void setup() {
    bootStart = millis();
#if defined(LOG_ENABLED)
    // Keep debug UART at the ROM/ESP-IDF boot baud so early boot and app logs
    // stay readable in one monitor session.
    Serial.setTxBufferSize(1024);
    Serial.begin(115200);
#else
    Serial.begin(115200);
#endif
    plogInit(false);
    LOGI("\n\n=== zBox ===\n");
    LOGI("Boot start\n");
    peripheralPowerInitEarly();

    const WakeDecision wakeDecision = handleWakeFromDeepSleep();
    runtimeSetSessionMode(wakeDecision == WakeDecision::NIGHT_LIGHT
                              ? RuntimeSessionMode::NIGHT_LIGHT
                              : RuntimeSessionMode::NORMAL);
    bootStart = millis();

    ledInit();
    buttonAdapterInit();

    sdReady = initSD();
    if (!sdReady) {
        LOGW("[BOOT] No SD card\n");
    } else {
        ledLoadConfigFromSd();
    }
    LOGI("SD %s\n", sdReady ? "OK" : "FAIL");

    plogInit(sdReady);
    plogMark("CRIT", "BOOT");
    {
        const esp_reset_reason_t reason = esp_reset_reason();
        LOGC("[BOOT] reset_reason=%d(%s) wake_cause=%d sd=%s heap=%u min_heap=%u\n",
             (int)reason, resetReasonName(reason), (int)esp_sleep_get_wakeup_cause(),
             sdReady ? "OK" : "FAIL", ESP.getFreeHeap(), ESP.getMinFreeHeap());
    }

    const bool syncPending = sdReady && SD.exists(SYNC_PENDING_PATH);
    LOGI("[BOOT] sync_pending flag: %d\n", syncPending);
    if (syncPending) {
        LOGC("[BOOT] sync mode requested via %s\n", SYNC_PENDING_PATH);
        runSyncMode();
        return;
    }

    dispatcherInit();
    postEventFromTask(makeEvent(EventType::BootStarted));

    if (runtimeIsNightLight()) {
        LOGI("\n--- Night light mode ---\n");
        nightLightInit();
        audioInit();
        btAdapterInit();
        buttonAdapterStartTask();

        postEventFromTask(makeBrightnessLoadedEvent(nightLightGetBrightnessPercent()));
        postEventFromTask(makeEvent(EventType::WakeCauseResolvedNightLight));
        postEventFromTask(makeEvent(EventType::BootInitCompleted));
        dispatcherStartTask();
        configureLoopWatchdog();

        LOGC("[BOOT] night_light=1 loop_core=%d setup_ms=%lu\n",
             xPortGetCoreID(), millis() - bootStart);
        LOGI("Ready! Night light active.\n");
        return;
    }

    LOGI("\n--- Normal mode ---\n");

    if (!ENABLE_NFC) {
        LOGC("[BOOT] nfc_init=SKIPPED test_disabled=1\n");
        LOGI("NFC disabled for test\n");
    }

    if (sdReady) {
        loadSystemSounds();
    }
    playbackInit();
    postEventFromTask(makePlaybackModeLoadedEvent(playbackGetMode()));
    LOGC("[BOOT] system_sounds=%d mappings_deferred=%d\n",
         (int)systemSoundCount(), (ENABLE_NFC && playbackIsNfcMode()) ? 1 : 0);

    loadOutputVolume();
    postEventFromTask(makeVolumeLoadedEvent(getOutputVolumeLevel()));
    postEventFromTask(makeEvent(EventType::WakeCauseResolvedNormal));

    audioInit();
    applyOutputVolume();
    btAdapterInit();

    buttonAdapterStartTask();
    postEventFromTask(makeEvent(EventType::BootInitCompleted));
    dispatcherStartTask();
    configureLoopWatchdog();

    if (ENABLE_NFC && playbackIsNfcMode()) {
        startDeferredNfcBootTask();
    } else if (ENABLE_NFC) {
        LOGC("[BOOT] nfc_init=SKIPPED playback_mode=music\n");
    }

    LOGC("[BOOT] loop_core=%d setup_ms=%lu\n", xPortGetCoreID(), millis() - bootStart);
    LOGI("Ready! Local audio active.\n");
}

void loop() {
    esp_task_wdt_reset();
    const AppState snap = getDiagnosticSnapshot();
    if (snap.boot_state == BootState::Ready) {
        syncNfcToPlaybackMode(snap.playback_mode);
    }

    btAdapterPoll();
    vTaskDelay(pdMS_TO_TICKS(5));

    if (!runtimeIsNightLight() && ENABLE_NFC &&
        snap.playback_mode == PlaybackMode::Nfc && s_nfcRuntimeStarted) {
        nfcAdapterDrain();
    }

    static unsigned long lastHeartbeat = 0;
    if (millis() - lastHeartbeat > 5000) {
        lastHeartbeat = millis();
        LOGI("[LOOP] alive audio=%d bt=%d out=%d\n",
             (int)snap.audio_state,
             (int)snap.bt_headphones_state,
             (int)snap.output_mode);
        plogFlushToSd();
    }

    static unsigned long lastDiag = 0;
    if (millis() - lastDiag > 30000) {
        lastDiag = millis();
        LOGI("[DIAG] HWM loop=%u led=%u audio=%u nfc=%u\n",
             uxTaskGetStackHighWaterMark(nullptr),
             ledGetTaskHWM(),
             audioGetTaskHWM(),
             nfcGetTaskHWM());
        LOGI("[DIAG] heap free=%u min=%u largest=%u\n",
             ESP.getFreeHeap(), ESP.getMinFreeHeap(), ESP.getMaxAllocHeap());
    }
}

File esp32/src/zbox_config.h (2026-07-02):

#pragma once

#define ENABLE_LEDS true
#define ENABLE_NFC true

// =============================================================================
// Pins
// =============================================================================

#define SD_CS 4 // SD card CS on the built-in Lolin D32 Pro slot

// PN532 NFC (software SPI)
#define PN532_SCK 22
#define PN532_MISO 21
#define PN532_MOSI 0
#define PN532_SS 5
#define NFC_EN 12  // Low-side N-MOSFET gate: HIGH = PN532 on, LOW = off

#define LED_PIN 14  // WS2812B DIN
#define LED_EN  27  // P-MOSFET gate (AO3415A): LOW = LEDs on, HIGH = off
#define LED_COUNT 12
#define LED_BRIGHTNESS 40

#define BTN_A 36 // VP / input-only, external pull-up required
#define BTN_B 39 // VN / input-only, external pull-up required
#define BTN_C 25 // VOL- (RTC)
#define BTN_D 26 // VOL+ (RTC, deep-sleep wake through ext0)
#define BTN_COUNT 4

#define AUDIO_I2S_BCLK 32
#define AUDIO_I2S_LRCK 33
#define AUDIO_I2S_DOUT 13
#define NS_EN 15 // High-side P-MOSFET gate: LOW = NS4168 on, HIGH = off
#define BAT_ADC_PIN 35 // GPIO35 (I35) reads the onboard D32 Pro battery divider
#define BAT_ADC_DIVIDER_RATIO 2.0f // D32 Pro: VBAT --100k-- GPIO35 --100k-- GND
#define BAT_ADC_CALIBRATION 0.983f // Per-device ADC calibration factor

// Active low-voltage cutoff: while the device is running, a sustained critical
// voltage forces a normal deep sleep (power-off sound + shutdown) instead of
// discharging the cell down to the pack's PCM cutoff (~2.5 V). No hardware latch
// exists, so deep sleep is the lowest state firmware can reach.
#define BAT_CRITICAL_VOLTAGE 3.30f    // force deep sleep below this
#define BAT_CRITICAL_RELEASE_V 3.40f  // hysteresis: reset the low counter above this
#define BAT_CRITICAL_POLL_MS 15000UL  // sampling cadence while awake
#define BAT_CRITICAL_CONSECUTIVE 3    // consecutive lows before sleeping (~45 s debounce)

// =============================================================================
// Configuration
// =============================================================================

#define LONG_PRESS_MS 2000
#define DOUBLE_CLICK_WINDOW_MS 350
#define WAKE_ABORT_MS 400
#define NIGHT_LIGHT_SLEEP_HOLD_MS 1000
#define DEBOUNCE_MS 20
#define NFC_READ_INTERVAL 1000
#define NFC_PRESENT_POLL_INTERVAL_MS NFC_READ_INTERVAL
#define NFC_BOOT_INIT_DELAY_MS 250
#define NFC_BOOT_MAPPING_DELAY_MS 350
#define NFC_ERROR_THRESHOLD 10
#define NFC_TAG_LOST_MS 1500  // Require a sustained missing read before treating the tag as removed
#define NFC_LOST_POLL_INTERVAL_MS 150
#define PN532_WAKE_SETTLE_MS 5
#define AUDIO_BUF_SIZE 2048

// Output volume
#define SYSTEM_SOUND_VOL_PERCENT 20
#define NIGHT_LIGHT_BRIGHTNESS_STEP 10
#define NIGHT_LIGHT_BRIGHTNESS_MIN 10
#define NIGHT_LIGHT_BRIGHTNESS_MAX 100
#define NIGHT_LIGHT_BRIGHTNESS_DEFAULT 50

// Idle timeout -> deep sleep
#define IDLE_TIMEOUT_MS (10UL * 60 * 1000) // 10 minutes without playback
#define NIGHT_LIGHT_TIMEOUT_MS (15UL * 60 * 1000)

// Sync / service mode
#define WIFI_HOSTNAME "zbox"
#define SYNC_PENDING_PATH "/data/sync_pending"
#define SYNC_AP_NAME "zBox-Sync"
#define SYNC_HTTP_PORT 80
#define SYNC_OTA_PORT 3232
#define SYNC_LOG_INTERVAL_MS 5000

// Bluetooth target speaker (NVS-backed, changeable from web portal)
#define BT_TARGET_NVS_KEY   "bt_target"
#define BT_TARGET_MAC_NVS_KEY "bt_mac"
#define BT_DEFAULT_NAME     "zBox Headphones"
#define BT_SCAN_MAX_RESULTS 12
#define BT_SCAN_NAME_MAX    64

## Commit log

2026-03-20 dziala ale szumi
    [musicbox-B_Cu.gbr, musicbox-B_Mask.gbr, musicbox-B_Paste.gbr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]
2026-03-24 workin bt solution
    [custom_4mb_noota.csv]
2026-04-30 krok 1: usuń martwy kod (currentNfcUid, lastNfcRead, noTagCount)
2026-04-30 krok 2: scope cleanup — anon namespace, static local
    - nfcErrorCount, bootStart, bootTimingDone → anonymous namespace
    - bothCDHandled → static local w handleButtons()
2026-05-01 test: native unit tests — uid format, volume, battery, mapping
    31 testów native (PlatformIO + Unity, bez hardware):
    - test_uid_format: 7 testów uidToString() (padding, uppercase, separatory)
    - test_volume: 6 testów volume clamp + 10 testów batteryBars()
    - test_mapping: 8 testów loadMappings() z ArduinoJson v7
2026-05-01 test: serial harness + boot sequence and timing integration tests
    SerialHarness: reader thread, wait_for_line/sequence, DTR reset.
    test_boot_sequence: 5 testów kolejności logów przy normalnym boot.
    test_timing: 4 testy progów T+ (GPIO <200ms, SD <500ms, NFC <2500ms, BT <3000ms).
2026-05-01 test: tester ESP32-S3 firmware (button simulation)
    Firmware dla drugiego ESP32-S3 (N16R8). Komendy serial: PRESS/PRESS_COMBO/RELEASE ALL/PING.
    Release = Hi-Z (INPUT), nigdy OUTPUT HIGH. Safety timeout 10s.
    GPIO: OUT_A=4, OUT_B=5, OUT_C=6, OUT_D=7.
2026-05-01 test: button automation tests (volume, battery, sleep, sync)
    ButtonTester: sterowanie tester ESP32-S3 przez serial.
    6 testów @requires_tester: VOL+/VOL-, BAT voltage range,
    deep sleep trigger, sync mode (flag + restart + SYNC MODE log).
2026-05-01 test: manual NFC playback tests
    4 testy @manual: place figurka → startPlayback + PLAYBACK START,
    uid format validation ([0-9A-F]{2}(:[0-9A-F]{2}){3,6}),
    remove → stopPlayback, audio telemetry SD=N B/s.
2026-05-01 test: update PROGRESS.md — etap 1 zielony (31/31)
2026-05-01 test: fix integration tests — boot/timing/heartbeat 15/15 PASS
    Naprawione problemy:
    - conftest: session fixture nie resetuje (double-reset przerywał boot)
    - serial_harness: dodano wait_for_nth_occurrence() do śledzenia N wystąpień
    - test_timing: BT start próg 3000→5000ms (empirycznie T+3638ms)
    - test_heartbeat: brak resetu w heartbeat testach (obserwacja działającego
    device eliminuje problem kumulatywnych resetów BT)
    - conftest: auto-skip dla @manual i @requires_hardware (nowe opcje
    --run-manual, --run-hardware)
2026-05-01 test: update PROGRESS.md — etapy 1-3 zielone (46/46)
2026-05-01 docs: dokumentacja testów (tests/README.md)
    Pełna dokumentacja wszystkich 6 etapów testów:
    - co każdy test sprawdza, tabele wzorców i progów
    - infrastruktura (SerialHarness, ButtonTester, conftest fixtures)
    - wymagania sprzętowe per etap
    - znane zachowania hardware (BT reconnect, IDLE_TIMEOUT)
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2026-05-01 refactor: przenieś wszystkie testy do esp32/test/
    tests/ → esp32/test/integration/ (Python integration tests)
    tests/requirements.txt → esp32/test/requirements.txt
    tests/PROGRESS.md → esp32/test/PROGRESS.md
    Zaktualizowano ścieżki w README.md i PROGRESS.md.
    Katalog tests/ usunięty.
2026-05-02 refactor: extract musicbox_config.h, logging.h, helpers.h
    - musicbox_config.h: wszystkie #define (piny, stałe, timeouty, BTN_COUNT)
    - logging.h: makra LOG/LOGLN
    - helpers.h: inline pure functions — urlEncode, uidToString, batteryBars
    - test_uid_format.cpp: zastąp inline kopię uidToString #include helpers.h
    - test_volume.cpp: zastąp inline kopię batteryBars #include helpers.h
    - 31/31 native tests zielone
2026-05-02 refactor: extract shared_types and state skeleton
    - shared_types.h: Button struct, NfcEvent struct (TYLKO te dwa)
    - state.h: extern deklaracje shared globals
    - state.cpp: definicje shared globals (przeniesione z main.cpp)
    - main.cpp: usuwa duplikaty, dodaje #include shared_types/state
    - bootStart/bootTimingDone: z anonimowego namespace do state.cpp
    - nfcErrorCount: static (→ nfc_module.cpp w kroku 7)
    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
2026-05-02 refactor: extract battery module
    - battery.h/.cpp: readBatteryVoltage() — hardware ADC read
    - batteryBars() pozostaje w helpers.h (używany przez buttons.cpp)
    - main.cpp: usuwa definicję, dodaje #include battery.h
    - lolin_d32_pro build OK
2026-05-02 refactor: extract leds module
    - leds.h/.cpp: LED task, animacje, cały state prywatny (leds[], ledMode, etc.)
    - ENABLE_LEDS przeniesiony do musicbox_config.h
    - API: ledInit, ledPreInitHardware, ledSuspendTask, ledResumeTask,
    ledClear, ledSetWakeProgress, ledPowerOff, ledGetTaskHWM,
    ledSetBootProgress, ledSetWaitBt, ledSetIdle, ledSetPlaying,
    ledShowVolume, ledSetSyncWifi, ledSetSyncProgress,
    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
2026-05-02 refactor: extract sd_storage module
    Move initSD, readJsonFromSd, loadMappings, loadSystemSounds into
    sd_storage.h/.cpp. Remove unused Preferences.h include from main.cpp.
    SD/SPI includes stay in main.cpp until sync_mode and audio are extracted.
2026-05-02 refactor: extract nfc_module
    Move Adafruit_PN532, nfcMutex, nfcQueue, nfcTaskHandle,
    nfcTaskStopRequested, rtcNfcPowerDownSent, nfcErrorCount,
    all raw SPI helpers, nfcInitSequence, reinitNfc, readNfcTag,
    nfcTaskFunc, and nfcPowerDown into nfc_module.h/.cpp.
    Public API: nfcInit, nfcPrescan, nfcStartTask, nfcGetEvent,
    nfcStopTaskForSleep, nfcPowerDown, nfcGetTaskHWM.
    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
2026-05-02 refactor: extract buttons_isr (ISR + init only)
    Move Button buttons[], btnISR IRAM_ATTR, and buttonsInit()
    from main.cpp to buttons_isr.h/.cpp. buttons[] is extern,
    accessible to buttons.cpp in the next step.
2026-05-02 refactor: extract buttons action handler
    Move handleButtons() from main.cpp to buttons.h/.cpp.
2026-05-02 refactor: cleanup main.cpp to setup() + loop() only
    Remove includes no longer needed in main.cpp (WiFi, ArduinoJson,
    SPI, map, set, esp_bt — all moved to their modules).
    main.cpp is now 361 lines: setup() + loop() + module includes.
    [main.cpp]
2026-05-05 dziala wszystko, zmiana sync mode gotowa
    [custom_4mb_ota.csv]
2026-05-08 for github
    [musicbox-B_Cu.gbr, musicbox-B_Mask.gbr, musicbox-B_Paste.gbr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]
2026-05-16 glosnik przez modul dziala i naprawione bugi po refacotrze oraz kilka usrpawnien
    [audio.cpp, battery.cpp, button_adapter.cpp]
2026-06-01 wszystko dziala, nie dziala rozlaczanie slcuhawek bo crash
    [audio.cpp, main.cpp, nfc_module.cpp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]
2026-07-01 Fixes for audio stutter and extra logging for esp
    [zbox.kicad_sch]
2026-07-01 disable logs for prod build, introduce prod build, introduce go to sleep when low voltage
2026-07-03 Repo cleanup
    [front_lid_zbox_clear.stl, nfc_card_slot_zbox_clear.stl, rear_lid_zbox_clear.stl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]
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
